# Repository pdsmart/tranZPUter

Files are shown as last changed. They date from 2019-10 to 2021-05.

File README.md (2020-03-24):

## Foreword

The tranZPUter is actively being developed and will be reflected in this document.

## Overview

The Sharp MZ80A is based on the Z80 CPU running at 2MHz. It is vintage and under powered compared with modern computers (or a Raspberry Pi). Besides being part of history, it has a software base that is useful from time to time and still has followers. A software Emulator could be written to prolong the usage of the software but there is something special about using original hardware and this is an alternative to keep the machine original yet provide an upgrade that can power the machine with multiple different CPU's (in FPGA, ie. ZPU, 68000 etc) and also power it with a Z80 running upto 128MHz. This is done by bus mastering where the original CPU is tri-stated and the FPGA takes control of the bus.

Besides providing more powerful and alternative CPU's and memory, the FPGA can also act as a Floppy Drive, Hard Drive etc using the connected SD Card and provide a menu system by overlaying the video memory when invoked.

This design is still a work in progress, I stopped development when I needed to advance the ZPU Evo SDRAM controller which I had been putting off for a while. The SDRAM is critical as the Cyclone 10LP on the CYC1000 has limited BRAM, only enough for the cache and IOCP Bootloader. Many features have been tested and the schematic/pcb made, it is just a matter of furthering the VHDL now that the SDRAM controller works and to develop the C/C++ code to provide the menu/SD services (already done in the ZPU code base).

I chose the CYC1000 as the FPGA solution as I am not competent soldering BGA devices, also at US$30 it is quite a cost effective choice. For software minded people, it is not that difficult to use a Pi Zero W or similar in place of the CYC1000 just a reworking of the PCB and interface logic, but that is a project for another time.

As the design replaces a Z80 in-situ it is not limited to the MZ80A but can be used in any Z80 based computer with the right software.

## tranZPUter

The tranZPUter gets its name from: A TRANsformable ZPU compuTER as the base CPU in the FPGA will be the ZPU Evo. The ZPU Evo will provide the Menu, SD, Video Overlay services to the Sharp MZ80A by tri-stating the original Z80 and accessing the MZ80A memory and peripherals as though they were ZPU devices.

To provide different CPU's it is just a matter of mapping in VHDL the softcore CPU signals to the MZ80A bus via this designs interface. The program memory could either be that on the MZ80A or the faster SDRAM. ie. There is no real need to use the MZ80A memory when using a softcore CPU. In my SharpMZ Emulator I run a Z80 at 112MHz using FPGA BRAM but tests show at least 128MHz is sustainable, thus a softcore Z80 CPU running at 128MHz with 48K BRAM slowing down only for MZ80A peripheral access would see a 64x boost in program run, which for say CP/M or database use is very desirable.

In the gallery are pictures of the current design and files uploaded onto github are relatively stable, WIP files wont be uploaded as they are in constant flux.

### Hardware

Sheet 1

The basics of this design lie in Z80 bus mastering, ie. the ability to switch the Z80 out of circuit and control the computer as required. Bus mastering was typically used by devices such as DMA for fast transfer of data from an I/O device to memory, or memory to memory 
for applications such as video/graphics. The device taking control of the Z80 bus could transfer data much faster than the Z80 running a program, hence the benefit.

In this design, the bus mastering is used in a similar vein, taking control of the Z80 bus to transfer data between main memory and an SD Card or between the I/O processor and the Video display buffer for presentation of menu's. It is also used where a soft processor
completely idle's the hard Z80 and acts as the main computer CPU. ie. using a soft T-80 ZPU CPU, it can process applications at 128MHz in local memory and slow down to access I/O and the Video buffer on the host machine.

The design centres around lifting the original Z80 onto a daughter card and rerouting several of its signals such that they can be controlled as needed. The core of the design is an FPGA, the Altera Cyclone 10LP on a mini development board made by Trenz Electronics.
This could quite easily be a Raspberry Pi or Teensy 3.6 but the aim of this project is to design electronic hardware in an FPGA using VHDL and making use of the ZPU Processor I have been working on in a seperate project.

The choice of the Trenz Electronic development board put a number of restrictions on the design in so much as it only provides limited I/O facilities. There were not so many other choices of pre-built FPGA development boards with the same size and features to choose from
and designing an FPGA directly into the design from project onset was considered too much a risk because my experience with BGA (Ball Grid Array) packaging and soldering of them was almost zero (I have reballed existing chips but those were working designs!).

As there were limited I/O facilities, I had to make use of two 16bit tri-state buffer latches in an addressed mode rather than a 1:1 mode. ie. The Z80 Data, Address and Control lines eminating out of the FPGA have to be 'set' one word at a time, ie. write data to latch, write address
to latch, write control signals to latch etc. This slows down the speed at which the FPGA can control the Z80 host (to be honest, a 100MHz FPGA can run 50 operations and still match the 2MHz original bus speed) and complicates the logic by requirement of FSM's in VHDL.

It is further complicated by the fact that the signals controlling the latches have themselves to be written in an addressed mode rather than direct, again due to lack of I/O facilities on the FPGA board. Thus in the schematic above you can see IC U6 & U8 being written to via
the common 16bit data bus (shared with the latches) and clocked by a single output signal from the FPGA. A delay line is used such that a write to the latch is performed by signal CYC_CTL/RST going high, this reaches the latch ~8ns after the same signal connected to the Master Reset goes high, thus clocking in the
data. The latches are reset when CYC_CTL/RST goes low and this is enough to control the 16 bit latches U5 & U9. ie. to write a 16bit word into U5 the procedure would be:
```
CYC_CTL/RST low
Set CYC_D0:7 to 0x02 (ADDR_LE active, low)
Set CYC_CTL/RST high, data on CYC_D0:7 is latched into U6/U8 and ADDR_LE goes active enabling transfer of data on CYC_D0:15 into U5 registers (latches on the rising edge of ADDR_LE).
Set required data on CYC_D0:15 that will be passed across to the Z80 BUS.
Set CYC_CTL/RST low, ADDR_LE goes inactive (high) and the data on CYC_D0:15 is latched into U5
```

Once the FPGA FSM is fine tuned, the actual write and read to/from the Z80 bus will be transparent but it is overly complicated as mentioned due to lack of I/O on the Trenz development board. 

### To Do
1. Write the ZPU C/C++ code to take control of the MZ80A, save/update/restore the Video Memory (for Menu system), convert the Main/sharpmz.? Menu/control code, and additional glue to use the SD card.<br/>
2. Convert the T80 CPU to act as a Z80 upgrade for the MZ80A.

## Credits

Where I have used or based any component on a 3rd parties design I have included the original authors copyright notice. All 3rd party software, to my knowledge and research, is open source and freely useable, if there is found to be any component with licensing restrictions, it will be removed from this repository and a suitable link/config provided.

## Licenses

This design, hardware and software, is licensed under the GNU Public Licence v3.

### The Gnu Public License v3
 The source and binary files in this project marked as GPL v3 are free software: you can redistribute it and-or modify it under the terms of the GNU General Public License as published by the Free Software Foundation, either version 3 of the License, or (at your option) any later version.

 The source files are distributed in the hope that it will be useful, but WITHOUT ANY WARRANTY; without even the implied warranty of MERCHANTABILITY or FITNESS FOR A PARTICULAR PURPOSE.  See the GNU General Public License for more details.

 You should have received a copy of the GNU General Public License along with this program.  If not, see http://www.gnu.org/licenses/.

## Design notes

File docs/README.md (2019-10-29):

## Foreword

This document is a work in progress.

## Overview

The Sharp MZ80A is based on the Z80 CPU running at 2MHz. It is vintage and under powered compared with modern computers (or a Raspberry Pi). Besides being part of history, it has a software base that is useful from time to time and still has followers. A software Emulator could be written to prolong the usage of the software but there is something special about using original hardware and this is an alternative to keep the machine original yet provide an upgrade that can power the machine with multiple different CPU's (in FPGA, ie. ZPU, 68000 etc) and also power it with a Z80 running upto 128MHz. This is done by bus mastering where the original CPU is tri-stated and the FPGA takes control of the bus.

Besides providing more powerful and alternative CPU's and memory, the FPGA can also act as a Floppy Drive, Hard Drive etc using the connected SD Card and provide a menu system by overlaying the video memory when invoked.

This design is still a work in progress, I stopped development when I needed to advance the ZPU Evo SDRAM controller which I had been putting off for a while. The SDRAM is critical as the Cyclone 10LP on the CYC1000 has limited BRAM, only enough for the cache and IOCP Bootloader. Many features have been tested and the schematic/pcb made, it is just a matter of furthering the VHDL now that the SDRAM controller works and to develop the C/C++ code to provide the menu/SD services (already done in the ZPU code base).

I chose the CYC1000 as the FPGA solution as I am not competent soldering BGA devices, also at US$30 it is quite a cost effective choice. For software minded people, it is not that difficult to use a Pi Zero W or similar in place of the CYC1000 just a reworking of the PCB and interface logic, but that is a project for another time.

As the design replaces a Z80 in-situ it is not limited to the MZ80A but can be used in any Z80 based computer with the right software.

## tranZPUter v1.0

The tranZPUter gets its name from: A TRANsformable ZPU compuTER as the base CPU in the FPGA will be the ZPU Evo. The ZPU Evo will provide the Menu, SD, Video Overlay services to the Sharp MZ80A by tri-stating the original Z80 and accessing the MZ80A memory and peripherals as though they were ZPU devices.

To provide different CPU's it is just a matter of mapping in VHDL the softcore CPU signals to the MZ80A bus via this designs interface. The program memory could either be that on the MZ80A or the faster SDRAM. ie. There is no real need to use the MZ80A memory when using a softcore CPU. In my SharpMZ Emulator I run a Z80 at 112MHz using FPGA BRAM but tests show at least 128MHz is sustainable, thus a softcore Z80 CPU running at 128MHz with 48K BRAM slowing down only for MZ80A peripheral access would see a 64x boost in program run, which for say CP/M or database use is very desirable.

Below are pictures of the current design and files uploaded onto github are relatively stable, WIP files wont be uploaded.

#### To Do
a) Write the ZPU C/C++ code to take control of the MZ80A, save/update/restore the Video Memory (for Menu system), convert the Main/sharpmz.? Menu/control code, and additional glue to use the SD card.<br/>
b) Convert the T80 CPU to act as a Z80 upgrade for the MZ80A.

### Images of the tranZPUter daughter board
##### 

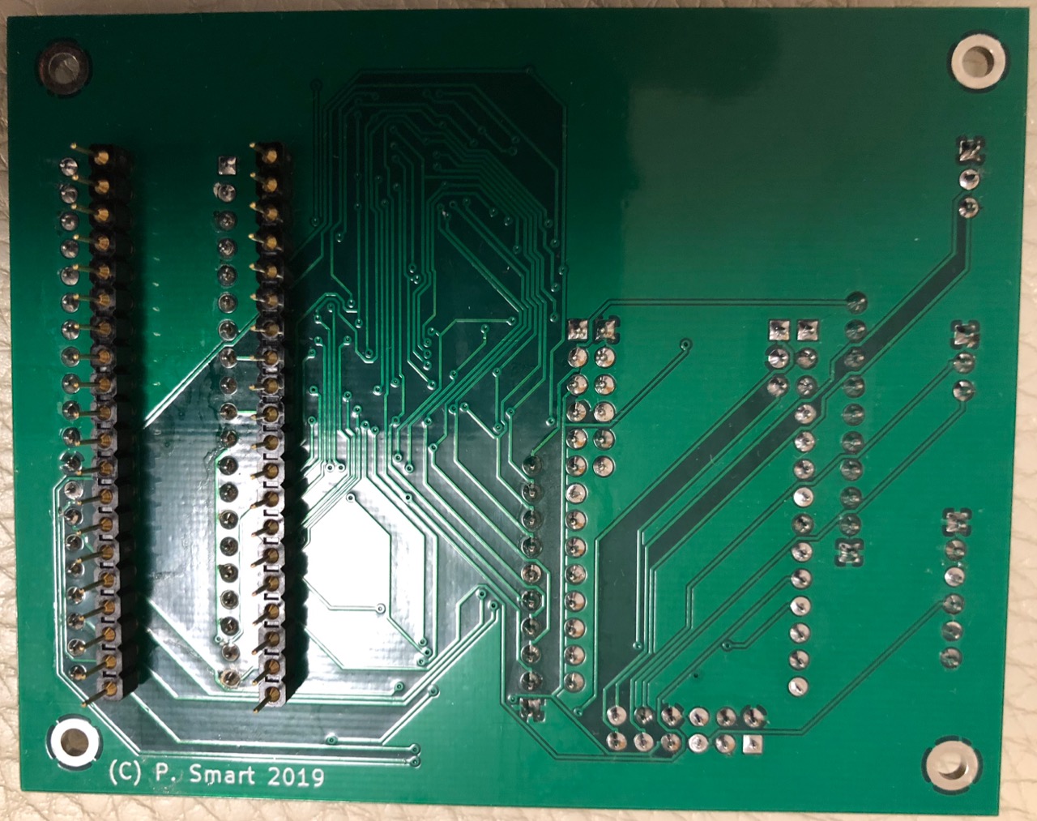
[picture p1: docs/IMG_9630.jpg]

Underside of the daughter board showing a 40pin standoff connector. The original Z80 CPU is removed, located onto the daughter board which is then connected by the 40pin standoff to the main board.

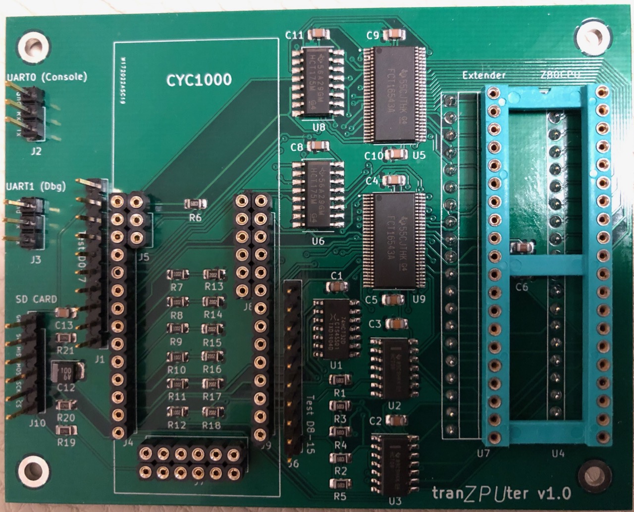
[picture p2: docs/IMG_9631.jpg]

Topside of the daughter board without the Z80 or CYC1000 devices.

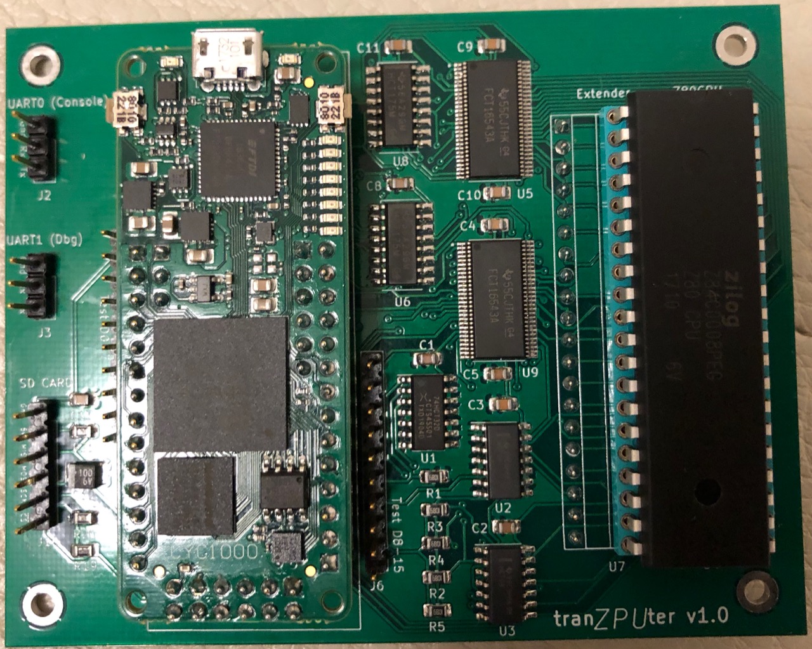
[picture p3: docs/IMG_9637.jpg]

Topside of the daughter board with the Z80 and CYC1000 in place.

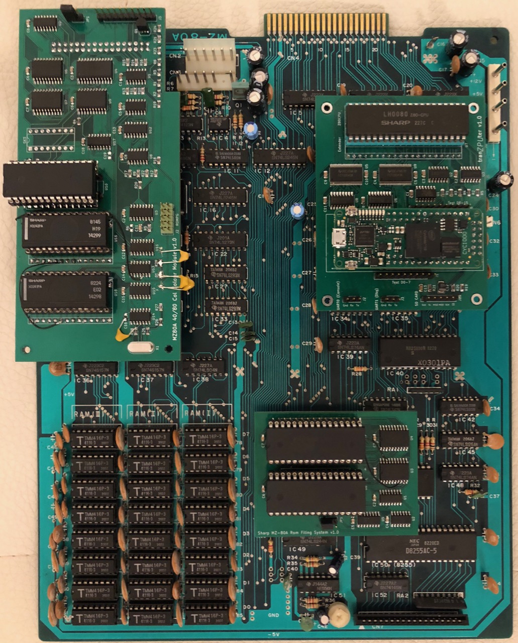
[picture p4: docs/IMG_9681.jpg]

The original motherboard, the tranZPUter daughter board is located top right and the 40/80 column and RFS daughter boards can also be seen in place.

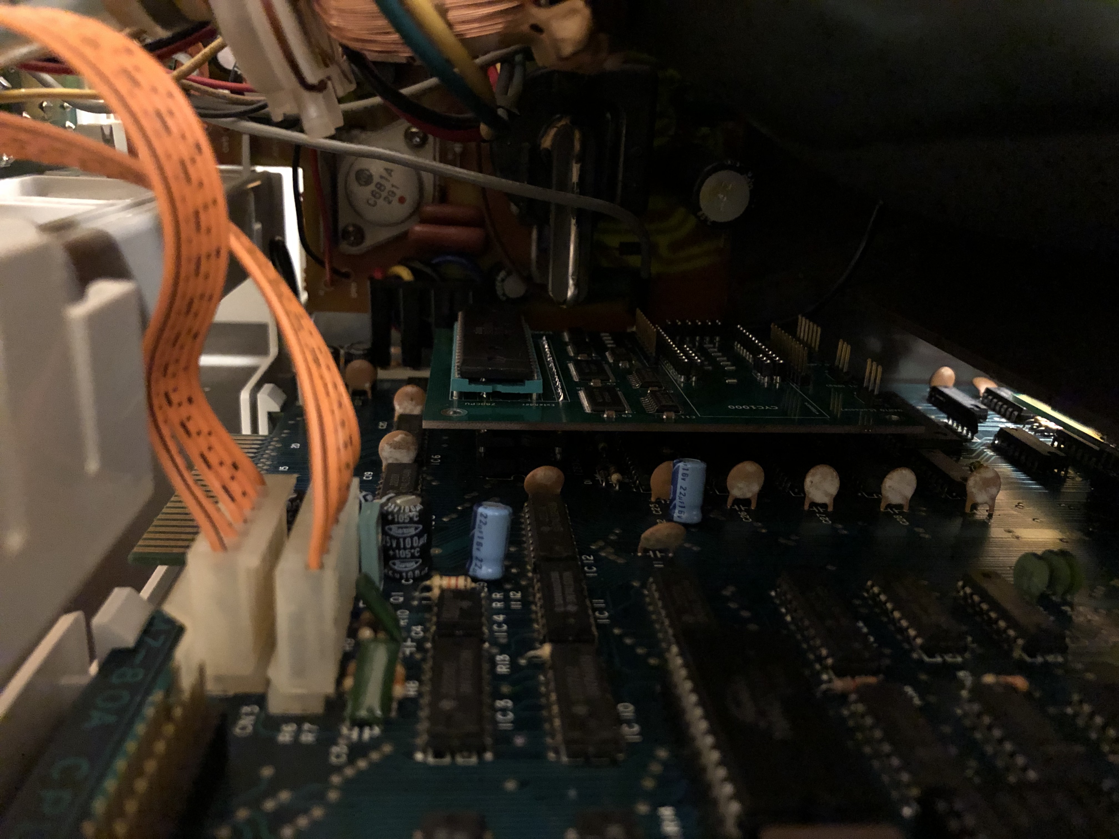
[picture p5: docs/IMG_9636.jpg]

A test to verify that the board sits correctly within the MZ80A computer.

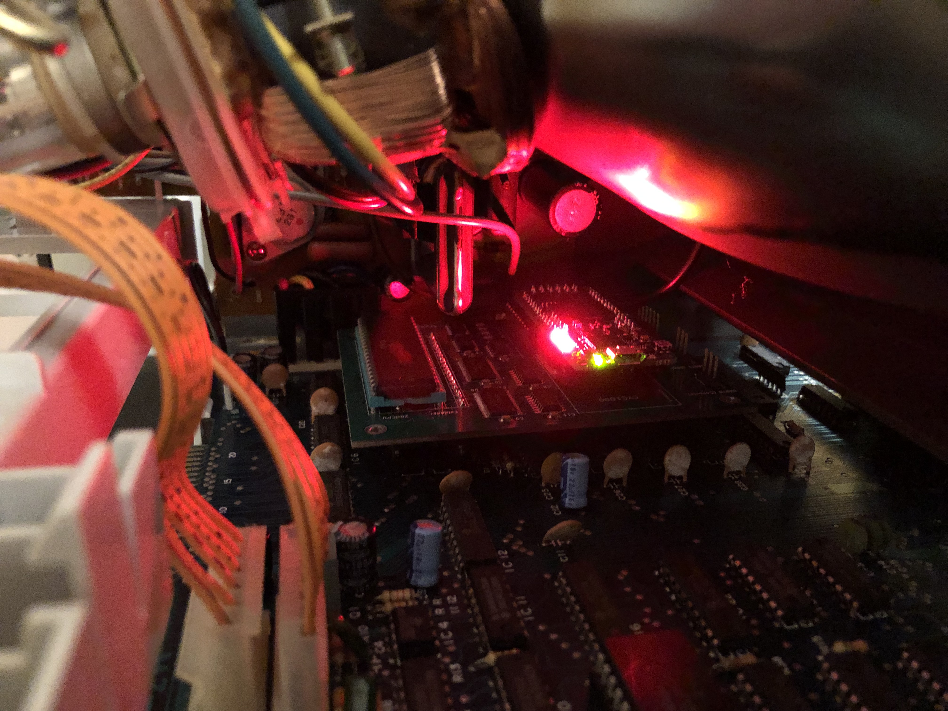
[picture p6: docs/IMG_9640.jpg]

A power on test and verification.

## Credits

Where I have used or based any component on a 3rd parties design I have included the original authors copyright notice.

## Licenses

This design, hardware and software, is licensed under th GNU Public Licence v3.

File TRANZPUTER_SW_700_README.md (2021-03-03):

## Foreword

<div style="text-align: justify">
The tranZPUter SW-700 is an evolution and merge of the tranZPUter, tranZPUter SW and Video Module v2.0 projects which were originally developed for the Sharp MZ-80A.
<br><br>

The project aims to provide the same functionality to the Sharp MZ-700 as is now provided on the Sharp MZ-80A.
<br><br>

The Sharp MZ-700 is a more compact design which required a new solution for upgrading it's CPU and Video. It wasnt possible, without hardware hacks, to upgrade the existing video and
with limited internal space presented more of a challenge. I eventually settled on a combined board where the tranZPUter SW and Video Module designs were used but with less components
and a co-existence of the new enhanced video with the original. This solution allows the machine to run as original or with selectable enhanced features as required. It is a more
wholesome solution with many possibilites beyond enhancing the MZ-700, for example it would be quite easy to run Linux on this machine, either via the on-board K64F processor using the
host as a terminal and/or reprogramming of the CPLD/FPGA to instantiate a soft-cpu and creating a development station for any conceivable processor, so would be of great use to 
students studying microprocessors and FPGA's.
<br><br>

The design is still being developed and these pages will be updated as new information becomes available. The reader is encouraged to read the seperate sections on the tranZPUter,
tranZPUter SW and Video Module to gain an understanding of the tranZPUter SW-700 evolution.
<br><br>

Everything will be written in C/C++ (FLW - Famous Last Words - I had to write the interrupt service routines in ARM Thumb assembler for the original tranZPUter SW as the K64F wasnt quite powerful enough
using compiled C).
</div>

--------------------------------------------------------------------------------------------------------

## Overview

<div style="text-align: justify">
The Sharp MZ-700 is based on the Z80 CPU running at 3.54MHz. It is vintage (albeit the Z80 is still widely used in new industrial designs clocking at 33MHz and above) and under powered compared
with modern computers (or a Raspberry Pi). Besides being part of history, it has a software base that is useful from time to time and still has followers. Many software Emulator's have been written
for the Sharp MZ-700 to prolong the usage of the software but there is something special about using original hardware and this is an alternative to keep the machine original yet provide an upgrade that can power
the machine with additional processing capabilities, storage and with multiple different CPU's based in software like the PiCoPro on the BBC Micro. This is all made possible with bus mastering
where the original CPU is tri-stated and the K64F/CPLD/FPGA takes control of the bus and the underlying original mainboard peripherals, when needed.
<br><br>

The upgrade also extends the Z80 hardware capabilities by providing additional RAM to allow for a 64K version of CP/M v2.2 (and upto 512K CP/M v3 when I get around to porting it) and to increase the speed of the
processor whilst maintaining the original speed when accessing the Sharp MZ-700 motherboard peripherals.
<br><br>

This design is a work in progress, albeit now mature and stable, it is working in tandem with the tranZPUter, tranZPUter SW and Video Module projects. As updates to the aforementioned projects are made or viz-a-viz, they are
back ported to this design. The C/C++ control software written for the tranZPUter SW is common and also intended to work on the tranZPUter under the ZPU.
</div>

--------------------------------------------------------------------------------------------------------

## tranZPUter SW-700

<div style="text-align: justify">
The tranZPUter gets its name from: A TRANsformable ZPU compuTER as the base CPU intended for the original tranZPUter is the ZPU Evo. The requirement was for the ZPU Evo to provide intended Menu, SD and Video Overlay services to the
Sharp MZ-80A by tri-stating the original Z80 and accessing the MZ-80A memory and peripherals as though they were ZPU devices.
<br><br>

The tranZPUter SW-700 follows on from the tranZPUter / tranZPUter SW designs and in addition adding the Video Module functionality to upgrade the host video. It also upgrades the underlying Z80 hardware enabling higher performance
and increased memory. It embeds a Freescale K64F ARM Cortex-M4 in place of the ZPU Evo as the tranZPUter SW-700 is more a software solution to the requirement rather than the ZPU Evo which is based on VHDL on an FPGA.
The project adds the suffix SW-700 for <u>S</u>oft<u>W</u>are for the MZ-<u>700</u> to distinguish the designs. 
<br><br>

The design of the tranZPUter SW-700 upgrades the Z80 hardware and can clock the processor, detached from the Sharp MZ-700 motherboard, at much higher clock rates, 
reliably tested and verified at 24MHz by overclocking a Z84C0020 20MHz CPU. Higher CPU performance will be a benefit to programs such as CP/M or databases such as DBase II.
<br><br>

To provide different CPU's you have the choice of taking existing ARM based software CPU emulations, for example those used in the PiCoPro and adapting them to use the CPU signals on the MZ-700 bus via this
designs interface or hardware based 'soft' processors instantiated on the FPGA. The program memory could be either: the MZ-700 motherboard 64K; the tranZPUter 512K; the faster K64F 256K memory;  FPGA BRAM or any combination. There is no real
need to use the MZ-700 memory when using a soft/'soft' CPU except for perhaps cache purposes. The benefits of using a soft/'soft' CPU with local K64F/FPGA RAM is better performance and access to alternative software.
<br><br>

In the gallery are pictures of the current design, files have been uploaded onto github and are relatively stable, WIP files wont be uploaded as they are in constant flux.
</div>

--------------------------------------------------------------------------------------------------------

## Hardware

<div style="text-align: justify">
The basics of this design lie in Z80 bus mastering, ie. the ability to switch the Z80 out of circuit and control the remaining computer hardware as required. Bus mastering was typically used
by devices such as DMA for fast transfer of data from an I/O device to memory, or memory to memory for applications such as video/graphics. The device taking control of the Z80 bus could transfer data much
faster than the Z80 running a program to perform the same action, hence the benefit.
<br><br>

Bus mastering is used to take control of the Z80 bus and to transfer data between main memory and an SD Card or between the I/O processor and the Video display
buffer for presentation of menu's. It is also used where a soft processor completely idle's the hard Z80 and acts as the main computer CPU. ie. using a soft CPU emulator, it can process
applications in local memory and slow down to access I/O and the Video buffer (if running with original video, the enhanced video runs at full speed) on the host machine as needed presenting a completely different
computing experience. Imagine, a 6809 or a 68000 based Sharp MZ-700!
<br><br>

The design centres around lifting the original Z80 onto a daughter card and rerouting several of its signals such that they can be controlled as needed. It also takes video output from the mainboard and routes it
internally to the FPGA based video module, where original or enhanced video can be selected before it is rerouted to the modulator via a new connector.
<br><br>

Design versions v1.0 and v1.1 were internal designs and wont appear in the repository. v1.2 was the first design which went on to be assembled and tested on the MZ-700. This design was used to further the software and FPGA development
and verify stability and reliability.  v1.3 is now the mainstream design, based on a more powerful FPGA, a Cyclone IV 75K (or a Cyclone IV 115K - build time selectable) which allows for higher resolution graphics and the ability to utilise 
alternate 'soft' hardware based processors, specifically the Z80 clone, T80 and the ZPU Evolution.
<br><br>

v1.2 and v1.3, with fundamental differences in logic and software, maintain their own branches in git. Both are proven designs, with v1.2 being cheaper to produce.
</div>

--------------------------------------------------------------------------------------------------------

## v1.2 Schematics

Version 1.2 is the first official release of the tranZPUter SW-700 design. It is based around the Sharp MZ-80A tranZPUter SW v2.2 and the Video Module v2.0 with optimisations to fit the Sharp MZ-700 platform.

### v1.2 Z80 Upgrade Schematic

Sheet 1

<div style="text-align: justify">
In order to be able to run programs for other Sharp models (ie. MZ-80A) or 64K CP/M the design adds a 512KB Static RAM device with necessary paging logic. An older MAX7000 series 512 macro cell CPLD is used as these devices are
5V tolerant thus saving on voltage translation circuitry between the 5V signals of the Sharp MZ-700 and the 3.3V signals used by the CPLD/FPGA. The CPLD provides the decoding logic, I/O remapping (ie. keyboard) and interface
to the FPGA (which is only 3.3V tolerant). The use of a CPLD, besides it's voltage translation abilities, allows for a very flexible development environment where features can be added at will, subject to the 512 macro cell limit.
<br><br>

The above schematic has been designed such that the board can be installed into an MZ-700 and the CPLD will be configured such that the machine is original, ie. no additional features enabled on power up. A write by the Z80 to the CPLD
I/O registers can enable features as required. This fulfills the requirement of keeping the machine original to maintain maximum compatibility with software.
</div>

### v1.2 The K64 I/O Processor

Sheet 2

<div style="text-align: justify"><br>
In order to provide embedded debugging, development and learning tools, enhanced features such as an SD card, soft-processors and offloaded co-processor services, an Freescale K64F ARM Cortex-M4 CPU is added into the design. This processor
has all the necessary hardware connectivity with the CPLD/Z80 giving it the ability to read or control any aspect of the tranZPUter SW-700 board or the MZ-700 mainboard. Under default conditions the K64F interacts with the Z80 to load the TZFS
enhanced monitor, provide an SD drive and aid in providing the alternate MZ series emulations such as the MZ-80A.
<br><br>

As the K64F utilises <b>zOS</b> as it's embedded OS, a USB connection can be made to the MZ-700 and a user can interact with an embedded session to change CPU frequency, edit/dump memory, change registers etc. This feature is ideal for learning
how a computer works or for debugging Z80/ARM code.
<br><br>

An optional feature is the installation and use of the PJRC bootstrap MCU which allows updating the K64F firmware via a USB cable. Without this MCU, the JTAG interface has to be used along with a compatible Open SDA interface such as the one provided
on the Freescale FRDM-K64F development board to update the K64F firmware. To allow for this optional device there are a set of 5 solder jumpers, connecting pads 1-2 on JP1-5 allows programming and use of the PJRC MCU, connecting pads 2-3 on JP1-4, pins 1-2 on JP5 
enables programming via the JTAG interface using the SWD protocol.
<br><br>

To power the K64F a seperate 3.3V regulator is used. It was intentionally chosen to use a seperate LDO to power the K64F rather than combining with the CPLD/FPGA requirements and use a larger LDO.
<br><br>

NB. A zOS application is being developed to flash new firmware into the K64F via the zOS console from the SD card and will remove the need to use the PJRC or JTAG tools. This tool should be available in zOS v1.2.
</div>

### v1.2 JTAG Programming and Oscillator

Sheet 3

<div style="text-align: justify"><br>
This design uses a CPLD and an FPGA both of which require programming via a JTAG interface. Using Altera best-practice the JTAG interface is wired to the highest voltage device first (CPLD) and daisy chained to the lower voltage
FPGA. The recommended pull-up/down resistors are as per Altera specifications.
<br><br>

The FPGA requires a bit stream to configure its internal logic matrix, which in turn provides the desired hardware functionality. This can be done real-time via a JTAG interface but doesnt solve the issue on power up. This is the
reason for the 16Mbit EPCS16 which is connected to the Cyclone III FPGA bootstrap pins. The EPCS16 is programmed via the Cyclone III using an Altera provided IP (Intellectual Property) which converts JTAG programming into EPCS16
programming. Once programmed and upon power up or pressing of the CONFIG switch, the EPCS16 contents are read into the FPGA and configures its logic matrix.
<br><br>

As the FPGA has 4 onboard PLL devices, the main crystal is fed into the Cyclone III FPGA and this acts as the timebase for all internal synchronous signals and video mode clocks. The frequencies used by the Z80, ie. the mainboard
frequency SYSCLK and the K64 generated alternate frequency CTLCLK are also fed into the Cyclone III to enable synchronisation.
</div>

### v1.2 Power Supply

Sheet 4

<div style="text-align: justify"><br>
Using more advanced technology requires voltages different to the original 5V standard. The CPLD requires 3.3V to function and the FPGA requires 1.2V for internal operations, 2.5V for analogue and PLL devices and a selectable 
I/O voltage, which in this design is 3.3V as it interfaces with the CPLD.
<br><br>

In order to generate these voltages, 3 LDO devices are used, each specified to 1A per rail. Using Altera tools the maximum power requirement for the CPLD/FPGA will be met by these LDO devices and by the original Sharp MZ-700 PSU.
<br><br>

Additionally, using CPLD/FPGA devices requires significant decoupling and Altera provide a dynamic spreadsheet to work out the number and value required. This is reflected in the schematic above.
</div>

### v1.2 Video Interface

Sheet 5

<div style="text-align: justify"><br>
Provision of enhanced video in this design differs from the method used in the Video Module v2.0. It was not possible to uplift existing IC's from the mainboard as most are soldered in place and internal space for expansion 
is also a big issue. Alternative methods were considered, eventually deciding on a mechanism which not only provided enhanced video from the FPGA but also allowed the original video to remain, switching between the two by software
as needed.
<br><br>

Using this mechanism, the video signals are uplifted from the mainboard modulator connector, routed into the FPGA via the CPLD (CPLD is 5V tolerant) and the FPGA either switches the original video to the output or generates it's 
own video. The CPLD takes care of enabling the mainboard such that when the enhanced FPGA video is being used, the signals to the original video hardware are blocked via the bus tri-state mechanism.
<br><br>

On the Video Module v2.0, 4 bits (3:0) per colour are output to give greater colour depth than the original MZ-700 hardware, which can be either driven directly from video ram attribute bits or via a colour palette lookup table. As this
design now has to maintain compatibility with the original modulator a 5th bit per colour has been added so that digital RGB monitors and the circuitry for composite/TV inside the modulator are driven by a voltage > 2V for logical
1 as opposed to the analogue RGB requirements of 0 - 0.75Vp-p. When driving a digital RGB monitor or driving the composite/TV output of the MZ-700 the 5th bit will be activated along with all the other bits therefore ensuring > 2.0V
for a digital 1. When driving an analogue RGB monitor the 5th bit cannot be activated as it will over saturate the inputs, BUT if the bit is set to hi-Z or 0 levels then the 5th bit can be used to create a further 16 sets of shades 
per colour, ie. R[3:0] + 0, G[3:0] + 0, B[3:0] + 0 or R[3:0] + hi-Z, G[3:0] + hi-Z, B[3:0] + hi-Z. This works when the 5th bit is set to 0 as it will act as a current sink for the other 4 bits, dropping the voltage seen by the monitor
when the 10R resistor is seen in-circuit. This provides 32 unique voltage levels per colour. When the 5th bit is set to hi-Z (high impedance) there is negligible change in the voltage output from bits 3:0.
<br><br>

</div>

#### v1.2 PCB

<div style="text-align: justify"><br>
The PCB requirements to fit inside the MZ-700 had to be accurate, in terms of the locations it could be sited to not affect mainboard components, casing obstacles, heat generation etc. Also the board has to fit into the Z80 socket yet
at the same time connect to the modulator connector, both would provide the anchor points to keep the board electrically connected and mechanically stable.
<br><br>

This design now uses 3 high density TQFP packages therefore adding more complexities, ie. routing. Space has to be available for all the lands given they are output in a 0.5mm pitch over a large area along with power distribution and decoupling.
The board is intentionally kept to 2 layer to gain the best production cost, typically US$60 including stencils for 10 boards, multi-layer would more than double the cost and only gain marginal size reductions.
<br><br>

The board below is a fully assembled and tested PCB for the Sharp MZ-700 along with images showing it installed in the physical machine.
</div>

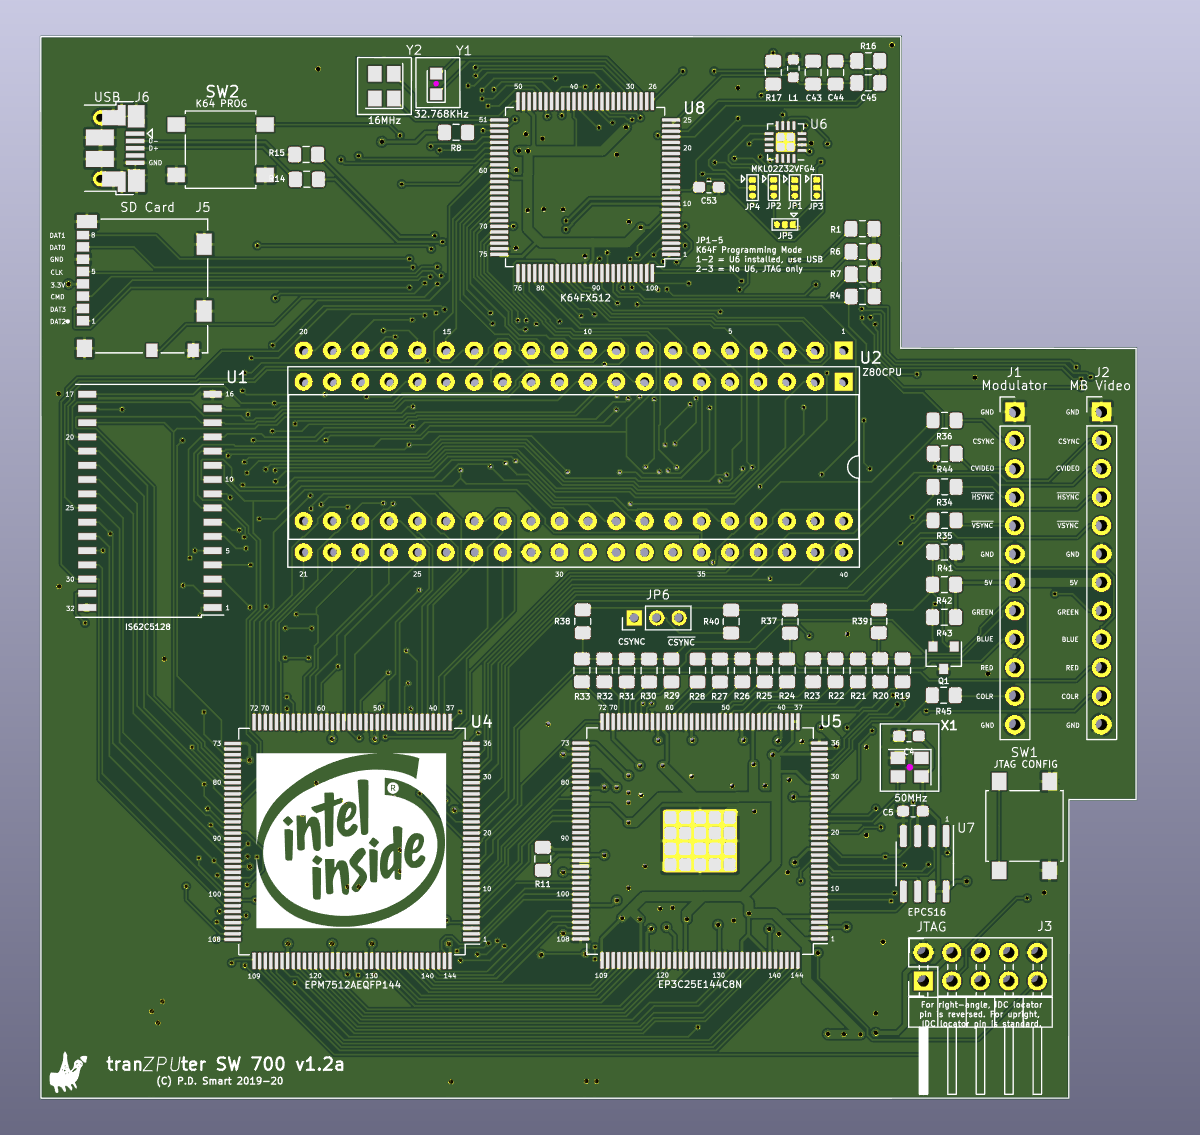
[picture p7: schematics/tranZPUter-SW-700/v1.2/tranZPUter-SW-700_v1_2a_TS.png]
PCB TopSide


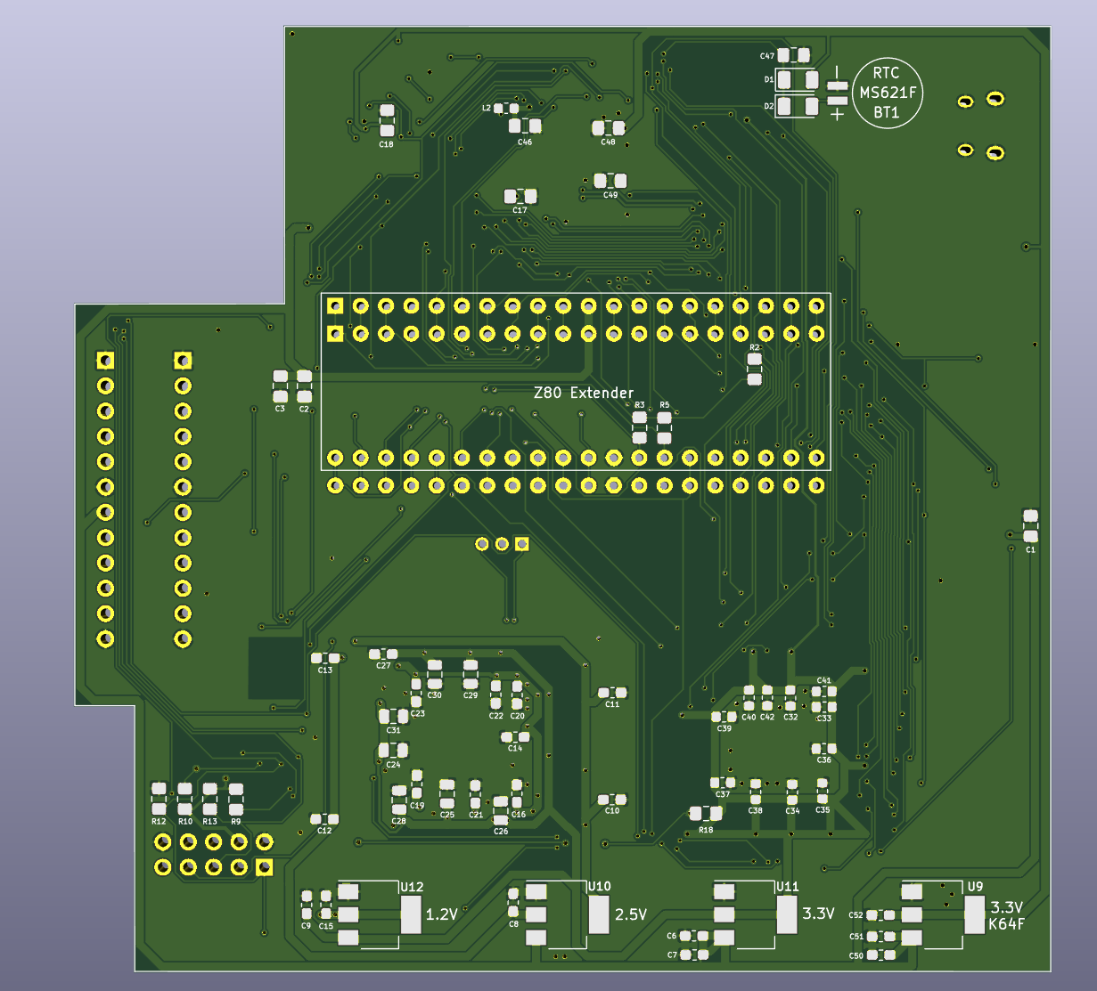
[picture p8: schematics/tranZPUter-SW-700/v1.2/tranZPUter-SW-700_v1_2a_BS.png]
PCB UnderSide


Installed, no case

Installed with case

--------------------------------------------------------------------------------------------------------

## v1.3 Schematics

Version 1.3 takes the working design of v1.2 and changes the FPGA to a more advanced component, the Cyclone IV EP4CE75, a 75K Logic Element device with over 340KB Block RAM. A build time option can use the Cyclone IV EP4CE115, a 115K Logic Element device with over 480K Block RAM.
These devices allows for more advanced graphics, higher resolution and more simultaneous colours. It also allows for the creation of 'soft' HDL based CPU's and is a stepping stone to the next iteration of the original ZPU based tranZPUter which will be based entirely on FPGA's (ie. no Z80, just a Z80 extender socket with 
the Z80 instantiated as a soft-cpu in the FPGA).

### v1.3 Z80 Upgrade Schematic

Sheet 1

<div style="text-align: justify">
Version 1.3 remains identical to v1.2 in all areas except the FPGA and additional interconnects between the CPLD/FPGA. V1.2 used a Cyclone III with 25K LE packaged as TQFP, v1.3 uses a Cyclone IV with 75K LE and is packaged as a 484pin BGA. The majority of the work centered around
decoupling, pin allocation and PCB production.
<br><br>

</div>

### v1.3 The K64 I/O Processor

Sheet 2

<div style="text-align: justify"><br>
The K64F schematic remains the same as v1.2 with the exception of reworking of the interconnects, removing some which no longer serve a useful function and adding to allow full 24bit direct addressing of memory and FPGA resources.
</div>

### v1.3 JTAG Programming and Oscillator

Sheet 3

<div style="text-align: justify"><br>
Version 1.3 sees the FPGA change and as a consequence, the clock is assigned to different clock inputs. In addition, as the device is larger, it requires a larger boot device in the form of the EPCS64, a 64mbit serial flash ram.
As the config switch proved redundant in v1.2 it has been removed from v1.3, programming via JTAG or PJRC MCU automatically invoke FPGA config mode.
</div>

### v1.3 Power Supply

Sheet 4

<div style="text-align: justify"><br>
Using a larger FPGA device places a greater demand on decoupling, no less than 34 decoupling capacitors are deemed necessary by the Altera PDN tool. This made for interesting PCB placement and routing!
</div>

### v1.3 Video Interface

Sheet 5

<div style="text-align: justify"><br>
The video interface remains the same as v1.2.
</div>

### v1.3 PCB

<div style="text-align: justify"><br>
Version 1.3 PCB is a rework of v1.2, replacing a 144 pin TQFP with a 484pin BGA, both identical in size but different in some parts placement and routing. The PCB remains as a 2 layer design but the inclusion of the BGA sees smaller via/land geometries and masked or filled via's. This increases the cost of PCB production
several fold over the v1.2 design. The PCB had a routing error which given the production cost had to be reworked, involving BGA pad rerouting and drilling, an intricate process but one which wont be forgotten. The old adage, 'measure twice, cut once' comes to mind, I measured twice but didnt make a final check, more especially after
a computer crash where I think the error originated, so my bad!
</div>

PCB TopSide

PCB UnderSide

PCB Installed
--------------------------------------------------------------------------------------------------------

## Design Detail

<div style="text-align: justify">
This section provides internal design information for understanding how the tranZPUter SW-700 functions and its interactions with the Host (the original computer).
</div>

--------------------------------------------------------------------------------------------------------

### K64F Z80 Host API

<div style="text-align: justify">
The API is based on a common block of RAM within the 64K memory space of the Z80 through which interprocessor communications take place. On the K64F this is declared
in C as a structure and on the Z80 as an assembler reference to memory variables.
<br>
</div>

```c
// Structure to contain inter CPU communications memory for command service processing and results.
// Typically the z80 places a command into the structure in it's memory space and asserts an I/O request,
// the K64F detects the request and reads the lower portion of the struct from z80 memory space, 
// determines the command and then either reads the remainder or writes to the remainder. This struct
// exists in both the z80 and K64F domains and data is sync'd between them as needed.
//
typedef struct __attribute__((__packed__)) {
    uint8_t                          cmd;                                // Command request.
    uint8_t                          result;                             // Result code. 0xFE - set by Z80, command available, 0xFE - set by K64F, command ack and processing. 0x00-0xF0 = cmd complete and result of processing.
    union {
        uint8_t                      dirSector;                          // Virtual directory sector number.
        uint8_t                      fileSector;                         // Sector within open file to read/write.
        uint8_t                      vDriveNo;                           // Virtual or physical SD card drive number.
    };
    union {
        struct {
            uint16_t                 trackNo;                            // For virtual drives with track and sector this is the track number
            uint16_t                 sectorNo;                           // For virtual drives with track and sector this is the sector number. NB For LBA access, this is 32bit and overwrites fileNo/fileType which arent used during raw SD access.
        };
        uint32_t                     sectorLBA;                          // For LBA access, this is 32bit and used during raw SD access.
    };
    uint8_t                          fileNo;                             // File number of a file within the last directory listing to open/update.
    uint8_t                          fileType;                           // Type of file being processed.
    union {
        uint16_t                     loadAddr;                           // Load address for ROM/File images which need to be dynamic.
        uint16_t                     saveAddr;                           // Save address for ROM/File images which need to be dynamic.
        uint16_t                     cpuFreq;                            // CPU Frequency in KHz - used for setting of the alternate CPU clock frequency.
    };
    union {
        uint16_t                     loadSize;                           // Size for ROM/File to be loaded.
        uint16_t                     saveSize;                           // Size for ROM/File to be saved.
    };
    uint8_t                          directory[TZSVC_DIRNAME_SIZE];      // Directory in which to look for a file. If no directory is given default to MZF.
    uint8_t                          filename[TZSVC_FILENAME_SIZE];      // File to open or create.
    uint8_t                          wildcard[TZSVC_WILDCARD_SIZE];      // A basic wildcard pattern match filter to be applied to a directory search.
    uint8_t                          sector[TZSVC_SECTOR_SIZE];          // Sector buffer generally for disk read/write.
} t_svcControl;
```

<div style="text-align: justify"><br>
Communications are all instigated by the Z80. When it needs a service, it will write a command into the svcControl.cmd field and set the svcControl.result field to 
REQUEST. The Z80 then writes to an output port (configurable but generally 0x68) which in turn sends an interrupt to the K64F. The K64F reads the command and sets the
svcControl.result to PROCESSING - the Z80 waits for this handshake, if it doesnt see it after a timeout period it will resend the command. The Z80 then waits for a valid
result, again if it doesnt get a result in a reasonable time period it retries the sequence and after a number of attempts gives up with an error.
<br><br>

Once the K64F has processed the command (ie. read directory) and stored any necessary data into the structure, it sets the svcControl.result to a valid result (success,
fail or error code) to complete the transaction.
</div>

**API Command List**

| Command | Cmd# | Description |
| --- | --- | --- |
| TZSVC_CMD_READDIR | 0x01 | Open a directory and return the first block of entries. |
| TZSVC_CMD_NEXTDIR | 0x02 | Return the next block in an open directory. |
| TZSVC_CMD_READFILE | 0x03 | Open a file and return the first block. |
| TZSVC_CMD_NEXTREADFILE | 0x04 | Return the next block in an open file. |
| TZSVC_CMD_WRITEFILE | 0x05 | Create a file and save the first block. |
| TZSVC_CMD_NEXTWRITEFILE | 0x06 | Write the next block to the open file. |
| TZSVC_CMD_CLOSE | 0x07 | Close any open file or directory. |
| TZSVC_CMD_LOADFILE | 0x08 | Load a file directly into tranZPUter memory. |
| TZSVC_CMD_SAVEFILE | 0x09 | Save a file directly from tranZPUter memory. |
| TZSVC_CMD_ERASEFILE | 0x0a | Erase a file on the SD card. |
| TZSVC_CMD_CHANGEDIR | 0x0b | Change active directory on the SD card. |
| TZSVC_CMD_LOAD40ABIOS | 0x20 | Request 40 column version of the SA1510 BIOS to be loaded, change frequency to match the Sharp MZ-80A. |
| TZSVC_CMD_LOAD80ABIOS | 0x21 | Request 80 column version of the SA1510 BIOS to be loaded, change frequency to match the Sharp MZ-80A. |
| TZSVC_CMD_LOAD700BIOS40 | 0x22 | Request 40 column version of the 1Z-013A MZ-700 BIOS to be loaded, change frequency to match the Sharp MZ-700 and action memory page commands. |
| TZSVC_CMD_LOAD700BIOS80 | 0x23 | Request 80 column version of the 1Z-013A MZ-700 BIOS to be loaded, change frequency to match the Sharp MZ-700 and action memory page commands. |
| TZSVC_CMD_LOAD80BIPL | 0x24 | Request the loading of the MZ-80B IPL, switch frequency and enable Sharp MZ-80B compatible mode. |
| TZSVC_CMD_LOADBDOS | 0x30 | Reload CPM BDOS+CCP. |
| TZSVC_CMD_ADDSDDRIVE | 0x31 | Attach a CPM disk to a drive number. |
| TZSVC_CMD_READSDDRIVE | 0x32 | Read an attached SD file as a CPM disk drive. |
| TZSVC_CMD_WRITESDDRIVE | 0x33 | Write to a CPM disk drive which is an attached SD file. |
| TZSVC_CMD_CPU_BASEFREQ | 0x40 | Set the tranZPUter to use the mainboard frequency for the Z80. |
| TZSVC_CMD_CPU_ALTFREQ | 0x41 | Switch the Z80 to use the K64F generated clock, ie. alternative frequency. |
| TZSVC_CMD_CPU_CHGFREQ | 0x42 | Change the Z80 frequency generated by the K64F to the Hertz value given in svcControl.cpuFreq, the Z80 will be clocked at the nearest timer resolution of this frequency. |
| TZSVC_CMD_CPU_SETZ80 | 0x50 | Switch to the external Z80 hard cpu. |
| TZSVC_CMD_CPU_SETT80 | 0x51 | Switch to the internal T80 soft cpu. |
| TZSVC_CMD_CPU_SETZPUEVO | 0x52 | Switch to the internal ZPU Evolution cpu. |
| TZSVC_CMD_SD_DISKINIT | 0x60 | Initialise and provide raw access to the underlying SD card.  |
| TZSVC_CMD_SD_READSECTOR | 0x61 | Provide raw read access to the underlying SD card. |
| TZSVC_CMD_SD_WRITESECTOR  | 0x62 | Provide raw write access to the underlying SD card. |
| TZSVC_CMD_EXIT | 0x7F | Terminate TZFS and restart the machine in original mode. |

**API Result List**

| Command | Result#  | Description |
| --- | --- | --- |
| TZSVC_STATUS_OK | 0x00 | The K64F processing completed successfully. |
| TZSVC_STATUS_FILE_ERROR | 0x01 | A file or directory error. |
| TZSVC_STATUS_BAD_CMD | 0x02 | Bad service command was requested. |
| TZSVC_STATUS_BAD_REQ | 0x03 | Bad request was made, the service status request flag was not set. |
| TZSVC_STATUS_REQUEST | 0xFE | Z80 has posted a request. |
| TZSVC_STATUS_PROCESSING | 0xFF | K64F is processing a command. |

--------------------------------------------------------------------------------------------------------

### K64F GPIO Organisation

<div style="text-align: justify">
In this design the K64F works in a supervisory and service role. The Z80 can function standalone without the K64F being present which leaves the host machine completely original and in addtion, the tranZPUter board also offers some
new upgrades such as 512K Static RAM which the Z80 can make use of as needed.
<br><br>

If advanced services are needed such as SD card access, alternate BIOS loading or variable alternative CPU clock then it needs the K64F to provide them, the Z80 see's the K64F as a hardware extension, it makes an I/O request and gets functionality in return.
<br><br>

If the Z80 for example requests a BIOS load, it generates an I/O out request which interrupts the K64F, the K64F puts the Z80 into tri-state bus mastered mode and then reads the BIOS from the SD card and operates the Z80 lines to write 
the BIOS data into the Z80 RAM.
<br><br>

In order to provide this functionality, the K64F needs to be able to read/write ALL of the Z80 signals. One of the advantages of the K64F is that it has an abundance of digitial I/O ports which are 5V tolerant, therefore connection
and operation of a 5V Z80 system is relatively straight forward.
<br><br>

The pin allocation of Z80 signals to K64F GPIO Port/Pin is a little disjointed as the K64F doesnt have a linear allocation of GPIO pins to internal registers, ie. the GPIO pins are split
over 5 32bit registers. This non-linear allocation adds overhead in piecing together 16bit address or 8bit data value's for realtime assembly and decode.
<br><br>

In earlier tranZPUter SW designs, the allocation of Z80 pins to GPIO Port/Pins led to some headaches in the interrupt service routine but these have now been solved by the addition of the CPLD which contains most of the time critical logic.
<br><br>

The following tables have been created to show Z80 signals to their associated K64F pins. The signals are spread across 5 x 32bit internal K64F registers.
</div>

##### K64F Port and Bit allocation 

| BIT / PORT | 31 | 30 | 29 | 28 | 27 | 26 | 25 | 24 | 23 | 22 | 21 | 20 | 19 | 18 | 17 | 16 | 15 | 14 | 13 | 12 | 11 | 10 | 9 | 8 | 7 | 6 | 5 | 4 | 3 | 2 | 1 | 0 |
|---|----|----|----|----|----|---|---|---|---|---|---|---|---|---|---|---|---|---|---|---|---|---|---|---|---|---|---|---|---|---|---|---|
| A | | | | | | | | | | | | | | |Z80_NMI |Z80_INT | |CTL_HALT  |CTL_RFSH |CTL_M1 | | | | | | |SYSCLK | | | | | |
| B | | | | | | | | |Z80_D7 |Z80_D6 |Z80_D5 |Z80_D4 |Z80_D3  |Z80_D2 |Z80_D1 |Z80_D0 | | | | |CTL_CLKSLCT|Z80_WAIT |Z80_MEM4 | | | | | |Z80_MEM3 |Z80_MEM2 |Z80_MEM1 |Z80_MEM0 |
| C | | | | | | | | | | | | | |Z80_A16 |Z80_A17 |Z80_A18 |Z80_A15 |Z80_A14 |Z80_A13 |Z80_A12 |Z80_A11 |Z80_A10 |Z80_A9 |Z80_A8 |Z80_A7 |Z80_A6 |Z80_A5 |Z80_A4 |Z80_A3 |Z80_A2 |Z80_A1 |Z80_A0 |
| D | | | | | | | | | | | | | | | | | | | | | | | | |Z80_RD |CTL_BUSACK |Z80_WR |Z80_RESET  |Z80_IORQ |Z80_MREQ |CTL_CLK |CTL_BUSRQ |
| E | | | | | |Z80_BUSACK| |SVCREQ  | | | | | | | | | | | | | | | | | | | | | | | | |

##### GPIO bits to Z80 Address Line mapping

| ADDR 18  | ADDR 17  | ADDR 16  | ADDR 15 | ADDR 14  | ADDR 13 | ADDR 12 | ADDR 11 | ADDR 10 | ADDR 9 | ADDR 8 | ADDR 7 | ADDR 6 | ADDR 5 | ADDR 4 | ADDR 3 | ADDR 2 | ADDR 1 | ADDR 0 |
|---|---|---|---|---|---|---|---|---|---|---|---|---|---|---|---|---|---|---|
|PORT C:16 | PORT C:17|PORT C:18 | PORT C:15 | PORT C:14| PORT C:13 | PORT C:12 | PORT C:11 | PORT C:10 | PORT C:9  | PORT C:8  | PORT C:7  | PORT C:6  | PORT C:5  | PORT C:4  | PORT C:3  | PORT C:2 | PORT C:1 | PORT C:0 |

##### GPIO bits to Z80 Data Line mapping

| DATA 7 | DATA 6 | DATA 5 | DATA 4 | DATA 3 | DATA 2 | DATA 1 | DATA 0 |
|---|---|---|---|---|---|---|---|
| PORT B:23 | PORT B:22 | PORT B:21 | PORT B:20 | PORT B:19 | PORT B:18 | PORT B:17  | PORT B:16  |

--------------------------------------------------------------------------------------------------------

### Z80 Memory Modes

<div style="text-align: justify">
One of the features of the tranZPUter SW-700 hardware design is the ability to create memory maps freely within the 512 macro cell CPLD. Any conceivable memory map within Z80 address space (or any soft-cpu address space upto 18 bits wide)
utilising the 512K Static RAM, 64K mainboard RAM, Video RAM, I/O can be constructed using a boolean equation and then assigned to a Memory Mode, The memory mode is then selected by Z80 software as required, ie. this ability is put to good
use in order to realise TZFS, CP/M and the compatible modes of the Sharp MZ-700 and MZ-80B.
<br><br>

The basis of the memory modes came from version 1 of the tranZPUter SW project where the decoder was based on a Flash RAM. All foreseen memory models required at that time, such as MZ-700, CP/M etc where devised. These modes have been enhanced in later designs
within the CPLD to cater for new features such as the Video Module and no doubt will be further enhanced in the future.
<br><br>

Modes which have been defined are in the table below leaving a few available slots for future expansion.
</div>

| Mode | Target | Range | Block&nbsp;&nbsp; | Function | DRAM Refresh | Description |
|---|---|---|---|---|---|---|
| 0 | Original | 0000:0FFF | Main  | MROM | Yes | Default, normal host (ie. Sharp MZ80A/MZ-700) operating mode, all memory and IO (except tranZPUter controlled I/O block) are on the mainboard |
| | | 1000:CFFF | Main  | D-RAM | | |
| | | D000:D7FF | Main  | VRAM | | |
| | | D800:DFFF | Main  | ARAM | | |
| | | E000:E7FF | Main  | MM I/O | | |
| | | E800:EFFF | Main  | User ROM | | |
| | | F000:FFFF | Main  | FDC ROM | | |
| 1 | Orig+ UROM  | 0000:0FFF | Main  | MROM | Yes | As 0 except User ROM is mapped to tranZPUter RAM and used for loadable BIOS images. |
| | | 1000:CFFF | Main  | D-RAM | | |
| | | D000:D7FF | Main  | VRAM | | |
| | | D800:DFFF | Main  | ARAM | | |
| | | E000:E7FF | Main  | MM I/O | | |
| | | E800:EFFF | RAM 0 | User ROM | | |
| | | F000:FFFF | Main  | FDC ROM | | |
| 2 | TZFS | 0000:0FFF | RAM 0 | MROM | No | Boot mode for TZFS or any other software requiring use of the tranZPUter RAM. User ROM appears as ROM to the Monitor so it will call the entry point at 0xE800 as part of it's normal startup procedure. The software stored at 0xE800 can switch out the mainboard and run in tranZPUter RAM as required. Two small holes at F3FE and F7FE exist for the Floppy disk controller (which have to be 2 bytes wude), these locations need to be on the mainboard. The floppy disk controller uses them as part of its data read/write as the Z80 isnt fast enough to poll the FDC. |
| | | 1000:CFFF | RAM 0 | Main RAM | | |
| | | D000:D7FF | Main  | VRAM | | |
| | | D800:DFFF | Main  | ARAM | | |
| | | E000:E7FF | RAM 0 | MM I/O | | |
| | | E800:EFFF | RAM 0 | User ROM | | |
| | | F000:FFFF | RAM 0 | FDC ROM | | |
| 3 | TZFS | 0000:0FFF | RAM 0 | MROM | No | Page mode for TZFS, all RAM in tranZPUter Block 0 except F000:FFFF which is in Block 1, this is page bank2 of TZFS. |
| | | 1000:CFFF | RAM 0 | Main RAM | | |
| | | D000:D7FF | RAM 0 | VRAM | | |
| | | D800:DFFF | RAM 0 | ARAM | | |
| | | E000:E7FF | RAM 0 | MM I/O | | |
| | | E800:EFFF | RAM 0 | User ROM | | |
| | | F000:FFFF | RAM 1 | FDC ROM | | |
| 4 | TZFS | 0000:0FFF | RAM 0 | MROM | No | As mode 3 but F000:FFFF is in Block 2, this is page bank3 of TZFS. |
| | | 1000:CFFF | RAM 0 | Main RAM | | |
| | | D000:D7FF | RAM 0 | VRAM | | |
| | | D800:DFFF | RAM 0 | ARAM | | |
| | | E000:E7FF | RAM 0 | MM I/O | | |
| | | E800:EFFF | RAM 0 | User ROM | | |
| | | F000:FFFF | RAM 2 | FDC ROM | | |
| 5 | TZFS | 0000:0FFF | RAM 0 | MROM | No | As mode 3 but F000:FFFF is in Block 3, this is page bank4 of TZFS. |
| | | 1000:CFFF | RAM 0 | Main RAM | | |
| | | D000:D7FF | RAM 0 | VRAM | | |
| | | D800:DFFF | RAM 0 | ARAM | | |
| | | E000:E7FF | RAM 0 | MM I/O | | |
| | | E800:EFFF | RAM 0 | User ROM | | |
| | | F000:FFFF | RAM 3 | FDC ROM | | |
| 6 | CP/M | 0000:FFFF | RAM 4 | Main RAM | No | CP/M, all memory on the tranZPUter board. Special case for F3C0:F3FF & F7C0:F7FF (floppy disk paging vectors) which resides on the mainboard. |
| 7 | CP/M | 0000:0100 | RAM 4 | CP/M Vectors | No | CP/M main CBIOS area, 48K + 2K available for the CBIOS and direct access to mainboard hardware. F000:FFFF remains in bank 4 and used as the gateway between this memory mode and mode 6. |
| | | 0100:CFFF | RAM 5 | Main RAM | | |
| | | D000:D7FF | Main  | VRAM | | |
| | | D800:DFFF | Main  | ARAM | | |
| | | E000:E7FF | Main  | MM I/O | | |
| | | E800:EFFF | RAM 5 | User ROM | | |
| | | F000:FFFF | RAM 4 | FDC ROM | | |
| 8 | Orig+ Emu | 0000:0FFF | Main  | MROM | Yes | Original mode but with the main RAM in the tranZPUter bank 0. This mode is used to bootstrap programs such as MZ-700 programs which bank change on startup and expect the loaded program to be within the main memory which is within a tranZPUter RAM bank. |
| | | 1000:CFFF | RAM 0 | Main RAM | | |
| | | D000:D7FF | Main  | VRAM | | |
| | | D800:DFFF | Main  | ARAM | | |
| | | E000:E7FF | Main  | MM I/O | | |
| | | E800:EFFF | Main  | User ROM | | |
| | | F000:FFFF | Main  | FDC ROM | | |
| 10 | MZ-700 | 0000:0FFF | RAM 6 | Main RAM | No | MZ-700 mode (OUT $E0) - Monitor RAM replaced with Main RAM |
| | | 1000:CFFF | RAM 0 | Main RAM | | |
| | | D000:D7FF | Main  | VRAM | | |
| | | D800:DFFF | Main  | ARAM | | |
| | | E000:E7FF | Main  | MM I/O | | |
| | | E800:EFFF | Main  | User ROM | | |
| | | F000:FFFF | Main  | FDC ROM | | |
| 11 | MZ-700 | 0000:0FFF | RAM 0 | MROM | No | MZ-700 mode (OUT $E0 + $E1) - I/O and Video block replaced with Main RAM |
| | | 1000:CFFF | RAM 0 | Main RAM | | |
| | | D000:D7FF | RAM 6 | VRAM | | |
| | | D800:DFFF | RAM 6 | ARAM | | |
| | | E000:E7FF | RAM 6 | MM I/O | | |
| | | E800:EFFF | RAM 6 | User ROM | | |
| | | F000:FFFF | RAM 6 | FDC ROM | | |
| 12 | MZ-700 | 0000:0FFF | RAM 6 | Main RAM | No | MZ-700 mode (OUT $E1 + $E2) - Monitor RAM replaced with RAM and I/O and Video block replaced with Main RAM |
| | | 1000:CFFF | RAM 0 | Main RAM | | |
| | | D000:D7FF | RAM 6 | VRAM | | |
| | | D800:DFFF | RAM 6 | ARAM | | |
| | | E000:E7FF | RAM 6 | MM I/O | | |
| | | E800:EFFF | RAM 6 | User ROM | | |
| | | F000:FFFF | RAM 6 | FDC ROM | | |
| 13 | MZ-700 | 0000:0FFF | RAM 0 | MROM | No | MZ-700 mode (OUT $E5) - Upper memory locked out, Monitor ROM paged in. |
| | | 1000:CFFF | RAM 0 | Main RAM | | |
| | | D000:FFFF | n/a | Undefined | | |
| 14 | MZ-700 | 0000:0FFF | RAM 6 | Main RAM | No | MZ-700 mode (OUT $E6) - Monitor RAM replaced with RAM and Upper memory locked out. |
| | | 1000:CFFF | RAM 0 | Main RAM | | |
| | | D000:FFFF | n/a | Undefined | | |
| 21 | K64F Access | 000000:FFFFFF | n/a | FPGA Resources | No | Access the FPGA memory by passing through the full 24bit Z80 address, typically from the K64F. |
| 22 | FPGA Access | 0000:FFFF | n/a | Host Resources | Yes | Access to the host mainboard 64K address space only. |
| 23 | K64F Access | 000000:FFFFFF | RAM | Main RAM | No | Access all memory and IO on the tranZPUter board with the K64F addressing the full 512K RAM. |
| 24 | K64F Access | 0000:FFFF | RAM 0 | Main RAM | Yes/No | All memory and IO are on the tranZPUter board, 64K block 0 selected. Mainboard DRAM is refreshed by the tranZPUter library when using this mode. |
| 25 | K64F Access | 0000:FFFF | RAM 1 | Main RAM | Yes/No | All memory and IO are on the tranZPUter board, 64K block 1 selected. Mainboard DRAM is refreshed by the tranZPUter library when using this mode. |
| 26 | K64F Access | 0000:FFFF | RAM 2 | Main RAM | Yes/No | All memory and IO are on the tranZPUter board, 64K block 2 selected. Mainboard DRAM is refreshed by the tranZPUter library when using this mode. |
| 27 | K64F Access | 0000:FFFF | RAM 3 | Main RAM | Yes/No | All memory and IO are on the tranZPUter board, 64K block 3 selected. Mainboard DRAM is refreshed by the tranZPUter library when using this mode. |
| 28 | K64F Access | 0000:FFFF | RAM 4 | Main RAM | Yes/No | All memory and IO are on the tranZPUter board, 64K block 4 selected. Mainboard DRAM is refreshed by the tranZPUter library when using this mode. |
| 29 | K64F Access | 0000:FFFF | RAM 5 | Main RAM | Yes/No | All memory and IO are on the tranZPUter board, 64K block 5 selected. Mainboard DRAM is refreshed by the tranZPUter library when using this mode. |
| 30 | K64F Access | 0000:FFFF | RAM 6 | Main RAM | Yes/No | All memory and IO are on the tranZPUter board, 64K block 6 selected. Mainboard DRAM is refreshed by the tranZPUter library when using this mode. |
| 31 | K64F Access | 0000:FFFF | RAM 7 | Main RAM | Yes/No | All memory and IO are on the tranZPUter board, 64K block 7 selected. Mainboard DRAM is refreshed by the tranZPUter library when using this mode. |

<font size="2">
<div style="text-align: left">
Key:<br>
    MROM       = Monitor ROM, the original boot firmware ie. SA-1510 <br>
    D-RAM      = Dynamic RAM on the mainboard. <br>
    VRAM       = Video RAM on the mainboard. <br>
    ARAM       = Colour Attribute RAM on the mainboard. <br>
    MM I/O     = Memory Mapped I/O controllers on the mainboard. <br>
    RAM 0 .. 7 = 64K RAM Block number within the 512K Static RAM chip. <br>
    Main       = Host computer mainboard, ie the Sharp MZ-80A mainboard. <br>
</div>
</font>

--------------------------------------------------------------------------------------------------------

### Z80 CPU Frequency Switching

<div style="text-align: justify">
In order to make the tranZPUter SW-700 compatible with other machines it is necessary to clock the CPU at the speed of that machine. It is also desirable to clock the CPU as fast as possible when using software such
as CP/M for maximum performance.
<br><br>

One of the main issues with frequency switching is that the underlying host cannot have its frequency changed, the host is generally generating the clock and it's circuits have been designed to operate within it's clock
tolerances. The tranZPUter SW-700 overcomes this limitation as described below.
<br><br>

To fulfil the requirement to have a switchable Z80 CPU frequency a positive edge triggered frequency switch has been implemented which takes the host frequency as one input and a square wave generator from the K64F as its second input.
The switching mechanism is tied to the bus control logic and so any access to the host will see the frequency of the CPU being changed to that of the host which ensures continued reliable operation. Under startup conditions, the Z80 is
always clocked by the host clock to ensure original specifications of the machine are met.
<br><br>

A second frequency can be selected if the K64F is present as it has the ability using its onboard timers to generate a programmable square wave output. The K64F sets the frequency of this second clock source
and the Z80 can select it via an I/O OUT command. This gives the software running on the Z80 the opportunity to change it's own frequency, albeit to a fixed set one. An extension to the K64F Host API allows the Z80 to make a request
of the K64F to set the Z80 CPU frequency to any possible value, this is useful in TZFS or CP/M so a user can select their own frequency.
<br><br>

Current testing on a CMOS Z84C0020 20MHz CPU has the following observations:
</div>

   * tranZPUter reliable in the range 1Hz to 24MHz for all functionality.
   * When the mainboard is accessed the frequency slows to 3.54MHz (ie. the system clock) and returns to the higher frequency after the mainboard access has completed.

<div style="text-align: justify"><br>
It is also possible to slow down the CPU for training or debugging purposes albeit access to the host circuitry will always run at the host clock frequency,
<br><br>

On an application running under the Z80, the following table outlines the I/O ports to which it must read/write in order to switch frequencies.
<br></div>

##### <u>Z80 CPU Frequency Switching Ports</u>

| Port | Dir  | Function |
| ---- | ---  | --- |
| 0x62 |  W | Switch Z80 CPU frequency to the second source, ie. the frequency generated by the K64F or external oscillator. |
| 0x64 |  W | Switch Z80 CPU frequency to default host source. This is the default on RESET. |
| 0x66 |  R | Bit [0] - Clock Selected, 0 = Host Clock, 1 = second clock source (K64F or external oscillator). |

--------------------------------------------------------------------------------------------------------

## System Configuration

The CPLD holds an internal configuration register to change how it operates with the underlying host. The table below outlines the ports along with each bits function.

##### <u>System Configuration Register (0x6E - 110 decimal)</u>

|  Bits | Dir  | Description |
|  ---- | ---  | --- |
|  2:0 | R/W  | Set hardware model compatibility. This configures the CPLD to remap host hardware to be compatible with the configured model.<br>000 = MZ-80K<br>001 = MZ-80C<br>010 = MZ-1200<br>011 = MZ-80A<br>100 = MZ-700<br>101 = MZ-800<br>110 = MZ-80B<br>111 = MZ-2000 |
|  3 | R/W  | Set the mainboard video state, 0 = enabled, 1 = disabled. If the mainboard video is enabled, the FPGA enhanced video will be disabled. |
|  4 | R/W  | Set the video wait state generator to be used during FPGA Video frame rendering, 0 = wait state disabled, 1 = enabled. |
|  7 | R/W  | Preserve configuration over reset (=1) or set to default on reset (=0). |

NB: The compatibility modes which have been implemented appear in the paragraphs below, all other modes are yet to be implemented. Selecting a mode which hasnt been implemented results in no mapping and reverts to the base MZ-700 hardware.

The CPLD also holds a read only information register which indicates the capabilities of the running machine.

##### <u>System Information Register (0x6F - 111 decimal)</u>

|  Bits | Dir | Description |
|  ---- | --- | --- |
|  2:0 |  R  | The underlying host model in which the tranZPUter is installed, ie. the physical computer hardware.<br>000 = MZ-80K<br>001 = MZ-80C<br>010 = MZ-1200<br>011 = MZ-80A<br>100 = MZ-700<br>101 = MZ-800<br>110 = MZ-80B<br>111 = MZ-2000 |
|  3 |  R  | FPGA Video Module installed, 0 = not installed, 1 = installed. |
|  7:5 |  R  | Version number of the CPLD. Used by Z80 code when newer versions of the CPLD VHDL provide differing features.  |

--------------------------------------------------------------------------------------------------------

## Soft Processors

<div style="text-align: justify">
One of the primary goals of the tranZPUter project was to be able to run various physical processors on a host machine. In this project, the host is a Sharp MZ series computer utilizing a Zilog Z80 processor but the board and concept could quite easily be used on another
host architecture, such as the BBC Micro Model B using the MOS 6502 CPU.
<br><br>

In the FPGA or even ASIC world, the word 'soft' can often be used out of context. A 'soft' processor isnt a software emulation, it
is a physical hardware device described in a HDL which can be instantiated and used inside an FPGA or masked onto an ASIC. The 'soft' is more relevant to FPGA where you can change the actual hardware device by uploading a new interconnect map at will. This
is because an FPGA (Field Programmable Gate Array) is a mass of electronic components with an interconnect layer and this interconnect layer is like RAM where a '1' will link two components together. You load up an interconnect bit map either by a
JTAG programming tool or via one of the FPGA's supported protocols such as a serial Flash configuration device. Once a device is instantiated and its interconnect loaded, it behaves like any other piece of hardware and so a 'soft' processor in an FPGA, when running,
is the same as any other 'hard' processor. 
<br><br>

Initially, to work out the framework for a 'soft' CPU to exist in the FPGA yet control the underlying Sharp MZ-700 hardware I chose to embed a T80 processor. This is a redesign of the venerable Zilog Z80 and achieves near cycle accuracy implementing all the documented
and undocumented instructions and presenting the correct hardware signals for external use. The design required changes in the CPLD as it now had to be a bidirectional gateway along with instantiation of a T80 processor and support logic within the FPGA. The end result was a processor,
running in the FPGA on a Sharp MZ-700 which was identical to the 'hard' Z80 running on the tranZPUter card.
<br><br>
Apart from aiding in the framework design, the 'soft' T80 has no advantages over a 'hard' Z80 except that you can modify the architecture/instructions for research 
or to aid a program speed and optionally choose the enhanced 'fast' mode of the T80. The actual Fmax is slower than the 'hard' Z80 due to the switching and propogation delays of the FPGA/CPLD, the 'hard' Z80 can run at 24MHZ, the T80 tops out at 18MHz. NB. If RAM was instantiated on the
FPGA and the T80 ran from FPGA BRAM instead of the hard 512K static RAM on the tranZPUter card it would achieve speeds upto 120MHz as it does in my Sharp MZ Series Emulator but this would require reworking of the control software (TZFS and the 1Z-013A monitor) as the memory model would be different.
<br><br>

Keeping with the Z80 theme, the AZ80 and the NextZ80 were added as build time choices (instead of the T80) for evaluation and comparison. The AZ80 has some slight I/O timing issues which result in an odd spurious keyboard read but otherwise runs flawlessly with all the MZ-700 software I tested. The NextZ80 is more of an instruction
compatible Z80 processor and doesnt present all the correct signals or follow the Z80 timing cycles, so more work is needed to make it run correctly.
</div>

The second processor added is the ZPU Evolution, a 32bit stack based processor originally written by Øyvind Harboe from [Zylin AS](https://opensource.zylin.com/) as a minimal logic size CPU to run in a supervisory mode in embedded systems. There have been a few extensions to the
design, the ZPU Flex and ZPUINO of note, but both didnt offer what I wanted for embedding into the Sharp MZ Series Emulator, so I redesigned it to gain speed and expandability creating the [ZPU Evolution](/zpu-evo/).

As the ZPU Evolution was intended to be embedded, [zOS](/zos/) was written with this functionality in mind, an OS which would run tasks inside a device to enhance it's functionality along with provision of an interactive session over a serial connection. Using a console connected to the serial connection you would be presented with
an MS-DOS like environment where you could run applications, control hardware or inspect/update memory and process flow, an ideal tool to work with a 'soft' ZPU Evolution running inside an FPGA which in turn was running inside an end application such as the Sharp MZ Series Emulator. When the tranZPUter SW project was born, zOS
was ported to the K64F which has been a great asset, being able to connect inside the tranZPUter SW and the Sharp MZ host has aided design and debug immensely. 

Adding a ZPU Evo into the tranZPUter SW-700 as a 'soft' processor required zOS to evolve, it no longer had serial connectivity and was required to control keyboard, screen etc directly. This led to the SharpMZ module being added which provides zOS with the basic hardware abstraction layers to drive the Sharp MZ-700 keyboard and screen, providing
the basic user I/O functionality including an ANSI terminal emulator. When the ZPU is selected from the Sharp MZ-700 monitor, zOS boots and you are presented with an interactive, MS-DOS like environment. There are some basic applications such as tbasic, mbasic. kilo (a VT100 based screen editor) and these can all be found in the [apps](/apps/) section of zOS.
As can be imagined, there isnt a lot of software to be run under zOS, although a lot of open source projects can be ported, the limiting factor is the GNU C/C++ 99 standard compiler or missing features such as thread control and virtual memory.

<div style="text-align: justify">
The ZPU and zOS are really for research and development and not meant for an end user. It is useful to learn the ZPU architecture, to design a processor or an OS so would benefit a student of electronics or computers immensely.
</div>

I am currently looking at instantiating a NIOSII processor with MMU as the FPGA has the resources to implement this processor and its support circuits and the end result would be Linux running on a Sharp MZ-700. This would be a far more useful platform so consider this is work in progress until completed and this page updated.

### CPU Configuration Registers

##### <u>CPU Configuration Register (0x6C - 108 decimal)</u>

|  Bits | Dir  | Description |
|  ---- | ---  | --- |
|  5:0 | R/W  | This register configures the FPGA to enable a soft/hard CPU and the CPLD is reconfigured to allow a CPU operation on the FPGA side rather than the physical hardware side.<br>Only one processor can be selected at one time, 1 bit per processor. Multiple bit selection will be voided and the hard processor selected.<br>000000 = Hard CPU <br>000001 = T80 CPU <br>000010 = ZPU Evolution <br>000100 = NIOS11<br>001000 = Future CPU 4 <br>010000 = Future CPU 5 <br>100000 = Future CPU 6 |
|  6 | R/W  | Clock enable. Enable (1) or disable the soft CPU clock. |
|  7 | R/W  | CPU Reset. When set to active ('1'), a reset pulse is generated and the bit state returned to 0. |

The FPGA holds a read only information register which indicates the soft processor capabilities.

##### <u>CPU Information Register (0x6D - 109 decimal)</u>

|  Bits | Dir | Description |
|  ---- | --- | --- |
|  5:0 |  R  | Bit mask, a 1 indicates a processor is available.<br>000000 = Hard CPU only<br>000001 = T80 CPU <br>000010 = ZPU Evolution <br>000100 = NIOSII<br>001000 = Future CPU 4 <br>010000 = Future CPU 5 <br>100000 = Future CPU 6 |
|  7:6 |  R  | Soft CPU capabilities, 01 = soft cpu capable, all other values indicate soft cpu capabilities not available. |

### ZPU Memory Map.

The ZPU has a configurable linear address space, typically 18-32 bit wide. When used as a soft processor it is configured for 24bit.

| Address Range | Sub Range |  Description |
| --- | --- |  --- |
| 000000:020000 | 000000:013FFF  |  zOS Kernel. |
| | 014000:01BFFF  |  Heap. |
| | 01C000:01FD7F  |  Stack. |
| | 01FD80:01FFFF  |  I/O processor service control record. Used for inter processor communications between the ZPU and the K64F so that the ZPU can make service calls, ie. read SD card. |
| 100000:180000 | |  512Kbyte 8bit wide static RAM on tranZPUter board. Applications are loaded and run from this area of RAM starting at 0x100000. |
| D00000:EFFFFF | |  Z80 Bus State Machine.  Depending on the accessed address will determine the type of transaction. In order to provide byte level access on a 32bit read CPU, a bank of addresses, word aligned per byte is assigned in addition to an address to read 32bit word aligned value. |
| | D00000:D7FFFF  | 512K Static RAM on the tranZPUter board. All reads are 32bit, all writes are 8, 16 or 32bit wide on word boundary. |
| | D80000:DBFFFF  | 64K address space on host mainboard (ie. RAM/ROM/Memory mapped I/O) accessed 1 byte at a time. The physical address is word aligned per byte, so 4 bytes on the ZPU address space = 1byte on the Z80 address space. ie. 0x00780 ZPU = 0x0078 Z80. |
| | DC0000:DFFFFF  | 64K I/O space on the host mainboard or the underlying CPLD/FPGA. 64K address space is due to the Z80 ability to address 64K via the Accumulator being set in 15:8 and the port in 7:0. The ZPU, via a direct address will mimic this ability for hardware which requires it. ie. A write to 0x3F with 0x10 in the accumulator would yield an address of 0xF103f.  All reads are 8 bit, writes are 8, 16 or 32bit wide on word boundary. The physical address is word aligned per byte, so 4 bytes on the ZPU address space = 1byte on the Z80 address space. ie. 0x00780 ZPU = 0x0078 Z80. |
| | E00000:E0FFFF  | 64K address space on host mainboard (ie. RAM/ROM/Memory mapped I/O) accessed 4 bytes at a time, a 32 bit read will return 4 consecutive bytes, start of read must be on a 32bit word boundary.
| | E80000:EFFFFF  | 512K Video address space - the video processor memory is directly mapped into ZPU memory address space. See the Video controller direct access mode below for a detailed explanation.
| | E80000:E8FFFF  | 64K Video / Attribute RAM
| | E90000:E9FFFF  | 64K Character Generator ROM/PCG RAM.
| | EA0000:EBFFFF  | 128K Red Framebuffer address space.
| | EC0000:EDFFFF  | 128K Blue Framebuffer address space.
| | EE0000:EFFFFF  | 128K Green Framebuffer address space.
| F00000:FFFFFF | F00800:F008FF  |  Interrupt Controller. Spacing between interrupt controller devices = 0x10. |
| | F00800:F00803  | Status Register. |
| | F00804:F00807  | Control Register. |
| | F00900:F009FF  |  SD Card Controller. |
| | F00900:F00903  | Address Register. |
| | F00904:F00907  | Data Register. |
| | F0090c:F0090f  | Status Register. |
| | F00C00:F00CFF  |  Timer. Spacing between timer devices = 0x40. |
| | F00C00:F00C3F  |  Timer 0. |
| | F00C00:F00C03  | TIMER_MICROSEC_DOWN - Programmable microsecond down counter. |
| | F00C04:F00C07  | TIMER_MILLISEC_DOWN - Programmable millisecond down counter. |
| | F00C08:F00C0B  | TIMER_MILLISEC_UP - Programmable millisecond up counter. |
| | F00C0C:F00C0F  | TIMER_SECONDS_DOWN - Programmable second down counter. |
| | F00C1C:F00C1F  | RTC_MILLISECONDS_EPOCH - Real Time milliseconds since EPOCH. |
| | F00C20:F00C23  | RTC_MICROSECONDS - Real Time microseconds count in current second. |
| | F00C24:F00C27  | RTC_MILLISECONDS - Real Time milliseconds count in current second. |
| | F00C28:F00C2B  | RTC_SECOND - Real Time seconds count. |
| | F00C2C:F00C2F  | RTC_MINUTE - Real Time minutes count. |
| | F00C30:F00C33  | RTC_HOUR - Real Time hours count. |
| | F00C34:F00C37  | RTC_DAY - Real Time days in month count. |
| | F00C38:F00C3B  | RTC_MONTH - Real Time month in year count.  |
| | F00C3C:F00C3F  | RTC_YEAR - Real Time current year count. |
| | F00C40:F00C7F  |  Timer 1 .. n, hardware build dependent. |
| | F00C40:F00C43  | Enable Register. |
| | F00C44:F00C47  | Index Register. |
| | F00C48:F00C4b  | Counter Register. |
| | F00F00:F00FFF  |  System on Chip Configuration. |
| | F00F00:F00F03  | SOCCFG_ZPU_ID - ID of the instantiated ZPU |
| | F00F04:F00F07  | SOCCFG_SYSFREQ - System Clock Frequency in MHz x 10 (ie. 100MHz = 1000) |
| | F00F08:F00F0B  | SOCCFG_MEMFREQ - Sysbus SDRAM Clock Frequency in MHz x 10 (ie. 100MHz = 1000) |
| | F00F0C:F00F0F  | SOCCFG_WBMEMFREQ - Wishbone SDRAM Clock Frequency in MHz x 10 (ie. 100MHz = 1000) |
| | F00F00:F00F03  | SOCCFG_DEVIMPL - Bit map of devices implemented in SOC. |
| | F00F04:F00F07  | SOCCFG_BRAMADDR - Address of Block RAM. |
| | F00F08:F00F0B  | SOCCFG_BRAMSIZE - Size of Block RAM. |
| | F00F0C:F00F0F  | SOCCFG_RAMADDR - Address of RAM (additional BRAM, DRAM etc). |
| | F00F00:F00F03  | SOCCFG_RAMSIZE - Size of RAM. |
| | F00F04:F00F07  | SOCCFG_BRAMINSNADDR - Address of dedicated instruction Block RAM. |
| | F00F08:F00F0B  | SOCCFG_BRAMINSNSIZE - Size of dedicated instruction Block RAM. |
| | F00F0C:F00F0F  | SOCCFG_SDRAMADDR - Address of SDRAM. |
| | F00F00:F00F03  | SOCCFG_SDRAMSIZE - Size of SDRAM. |
| | F00F04:F00F07  | SOCCFG_WBSDRAMADDR - Address of Wishbone SDRAM. |
| | F00F08:F00F0B  | SOCCFG_WBSDRAMSIZE - Size of Wishbone SDRAM. |
| | F00F0C:F00F0F  | SOCCFG_CPURSTADDR - Address CPU executes after a RESET. |
| | F00F00:F00F03  | SOCCFG_CPUMEMSTART - Start address of Memory containing BIOS/Microcode for CPU. |
| | F00F04:F00F07  | SOCCFG_STACKSTART - Start address of Memory for Stack use. |

--------------------------------------------------------------------------------------------------------

## Video Module

<div style="text-align: justify">
The Video Module, on the v1.2 board is based around an Altera Cyclone III FPGA with 76KB internal B(lock)RAM and 25K Logic Elements (groups of configurable logic gates). On the updated v1.3 board it is based around an
Altera Cyclone IV E75/E115 with 360K/480K and 75K/115K Logic Elements.
<br><br>

Using the FPGA allows the tranZPUter SW-700 to provide video capabilites for nearly all the Sharp MZ series, ie: MZ-80K, MZ-80C, MZ-1200, MZ-80A, MZ-700, MZ-80B (including graphics). In the near future the video capabilities will be upgraded to
include the MZ-800 and MZ-2000 machines. To use a specific machines video capabilities, a mode (described below) is written into the mode register to select the required video capabilites based on machine model and you then use the normal methods
of accessing the video of the selected machine ie. 0xD000-0xD7FF for video on an MZ-80A. This includes functions such as the invert or hardware scroll functionality.
<br><br>

An addition to the original Sharp MZ series capabilites, is the addition of a 640x200/320x200 8 colour Graphics frame buffer. This frame buffer is made up of 3x16K RAM blocks, 1 per colour with a resolution of 640x200 which matches the output display
buffer bit for bit.  If the display is working at 40x25 characters then the resolution is 320x200, otherwise for 80x25 it is 640x200.
<br><br>

For all modes except 640x200 (limitation only the Cyclone III) the display is double buffered whereby the image is assembled in a seperate buffer to the one which is rendered for screen display. Due to lack of memory in the Cyclone III FPGA, in 640x200 mode the display isnt double buffered
and therefore an optional WAIT state generator can be enabled to prevent screen snow/tear as required. The Cyclone IV has sufficient RAM to double buffer, as per the Sharp MZ Series Emulator from where the video logic design was taken.
<br><br>

The RAM for the Graphics frame buffer can be switched into the main CPU address range C000H – FFFFH by programmable registers, 1 bank at a time (ie. Red, Green, Blue banks). This allows for direct CPU addressable pixels to be read and/or written.
Each pixel is stored in groups of 8 (1 byte in RAM) scanning from right to left per byte, left to right per row, top to bottom. Ie. if the Red bank is mapped into CPU address space, the byte at C000H represents red pixels 7 - 0 of 320/640 (X) at pixel
0 of 200 (Y). Thus 01H written to C000H would set Pixel 7 (X), Row 0 (Y) to On, 80H written to C000H would set pixel 0 (X), Row 0 (Y) . This applies for Green and Blue banks when mapped into CPU address space.
<br><br>

In order to speed up the display, there is a Colour Write register (similar to what is available on the Sharp MZ-2500), so that a write to the graphics RAM will update all 3 banks at the same time which allows for immediate colour write.
</div>

### Programmable Registers

In order to make use of the video functionality a set of registers have been designed through which all functions can be accessed. 

The functionality is grouped as follows:
 <ul>
   <li style="margin: 1px 0"> Control  - set the video capability mode, set the column width, set the colour/mono capabilities.</li>
   <li style="margin: 1px 0"> Graphics - configure the graphics capability.</li>
   <li style="margin: 1px 0"> GPU - offload tasks to the inbuilt graphics processor to speed up video tasks.</li>
   <li style="margin: 1px 0"> Palette - set and configure the display palette.</li>
 </ul>

The registers lie in the upper I/O region from 0xD0 - 0XFD and are accessed with standard Z80 I/O commands IN/OUT. Unless otherwise stated, all registers are read/write and a read will return the current value stored.

##### <u>Control Register (0xF8 - 248 decimal)</u>

This is the video mode register. It specifies the hardware model the Video Module should function as in addition the column width and colour abilities of the output display.

|  Bits | Dir  | Description |
|  ---- | ---  | --- |
|  2:0 | R/W  | Set the hardware model of the Video Module.<br>000 = MZ-80K<br>001 = MZ-80C<br>010 = MZ-1200<br>011 = MZ-80A<br>100 = MZ-700<br>101 = MZ-800<br>110 = MZ-80B<br>111 = MZ-2000 |
|  3 | R/W  | Set the column width of the video output. 0 = 40 Column, 1 = 80 Column |
|  4 | R/W  | Set the colour capabilities of the video output. 0 = Monochrome, 1 = Colour.  |
|  5 | R/W  | Enable the Programmable Character Generator RAM. 0 = disabled, 1 = enabled. |
|  7:6 | R/W  | Set the VGA mode.<br>00 = Original MZ video format, 15.62KHz Horizontal x 60Hz Vertical.<br>01 = VGA 640x480 @ 60Hz<br>10 = VGA 1024x768 @ 60Hz<br>11 = VGA 800x600 @ 60Hz. |

##### <u>Graphics Mode Register (0xF9 - 249 decimal)</u>

This is the graphics mode control register. It specifies what video is to be output, how it is blended and which Graphics RAM bank can be read/written to.

|  Bits | Dir  | Description |
|  ---- | ---  | --- |
|  1:0 | R/W  | Read mode (00=Red Bank, 01=Green Bank, 10=Blue Bank, 11=Not used). Select which bank to be read when enabled in CPU address space. |
|  3:2 | R/W  | Write mode (00=Red Bank, 01=Green Bank, 10=Blue Bank, 11=Indirect). Select which bank to be written to when enabled in CPU address space.  |
|  4 | R/W  | VRAM Output. 0=Enable, 1=Disable. Output Character RAM to the display. |
|  5 | R/W  | GRAM Output. 0=Enable, 1=Disable. Output Graphics RAM to the display. |
|  7:6 | R/W  | Blend Operator (00=OR ,01=AND, 10=NAND, 11=XOR). Operator to blend Character display with Graphics Display. |

##### <u>Colour Writer Registers (0xFA - 250 decimal to 0xFC - 252 decimal)</u>

<div style="text-align: justify">
The colour writer register is a bit map which is applied to each colour frame buffer during an indirect write (ie. all 3 colour pages at once).
<br><br>

For Indirect mode (Control Register bits 3/2 set to 11), a write to the Graphics
RAM when mapped into CPU address space C000H – FFFFH will see the byte masked by the Red Colour Writer Register and written to the Red Bank with the same operation for Green and Blue. This allows rapid setting of a colour across the 3 banks.
<br><br>

ie. Red Filter = 0x80, Green Filter = 0x40, Blue Filter = 0x20, then an indirect write to address C000H will set pixel 0,0 to red, 1,0 to green, 2,0 to blue.
<br><br>
</div>

| Bit  | Dir  | Pixel  | I/O Addr | Colour | Description |
| ---  | ---  | -----  | --- | --- | --- |
| 0 | R/W  | 7 | 0xFAH | Red | Set to Red during indirect write.  |
| 1 | R/W  | 6 | 0xFAH | Red | |
| 2 | R/W  | 5 | 0xFAH | Red | |
| 3 | R/W  | 4 | 0xFAH | Red | |
| 4 | R/W  | 3 | 0xFAH | Red | |
| 5 | R/W  | 2 | 0xFAH | Red | |
| 6 | R/W  | 1 | 0xFAH | Red | |
| 7 | R/W  | 0 | 0xFAH | Red | Set to Red during indirect write.  |
| 0 | R/W  | 7 | 0xFBH | Green | Set to Green during indirect write.|
| 1 | R/W  | 6 | 0xFBH | Green | |
| 2 | R/W  | 5 | 0xFBH | Green | |
| 3 | R/W  | 4 | 0xFBH | Green | |
| 4 | R/W  | 3 | 0xFBH | Green | |
| 5 | R/W  | 2 | 0xFBH | Green | |
| 6 | R/W  | 1 | 0xFBH | Green | |
| 7 | R/W  | 0 | 0xFBH | Green | Set to Green during indirect write.|
| 0 | R/W  | 7 | 0xFCH | Blue | Set to Blue during indirect write. |
| 1 | R/W  | 6 | 0xFCH | Blue | |
| 2 | R/W  | 5 | 0xFCH | Blue | |
| 3 | R/W  | 4 | 0xFCH | Blue | |
| 4 | R/W  | 3 | 0xFCH | Blue | |
| 5 | R/W  | 2 | 0xFCH | Blue | |
| 6 | R/W  | 1 | 0xFCH | Blue | |
| 7 | R/W  | 0 | 0xFCH | Blue | Set to Blue during indirect write. |

##### <u>Memory Page Registers (0xFD - 253 decimal)</u>

This register is responsible for enabling Video memory into Z80 address space. It is possible to enable 1 of the 3 colour 16KB GRAM (chosen via the Graphics Mode register) into Z80 address C000:FFFF or the CGROM into Z80 address space D000:DFFF. This register
overrides all other memory page settings.

|  Bits | Dir  | Description |
|  ---- | ---  | --- |
|  0 | R/W  | Switches in a 16Kb graphics ram bank to C000 - FFFF. The bank (or colour) is selected by the Graphics Mode register.<br>0 = Off, normal Z80 memory operations.<br>1 = 16KB GRAM enabled.<br>Setting this register overrides all MZ-700/MZ-80B specific memory page settings. |
|  7 | R/W  | Switches in CGROM for upload at D000:DFFF. 0 - Normal memory operations, 1 - CGROM paged in. |

##### <u>Video Module Status Register (0xFD - 253 decimal)</u>

This register reports on the Video Module status. Bits 7 & 0 are reserved for reporting the Memory Page register settings.

|  Bits | Dir  | Description |
|  ---- | ---  | --- |
|  5 |  R | Framebuffer Horizontal Blanking. 1 = Horizontal Blanking active, 0 = no horizontal blanking. |
|  6 |  R | Framebuffer Vertical Blanking. 1 = Vertical Blanking active, 0 = no vertical blanking. |

##### <u>GPU Parameters Register (0xF6 - 246 decimal)</u>

<div style="text-align: justify">
This register is a 128bit push/pop register for storing parameters to be used by a GPU command. The actual contents varies according to the command issued (ie. see GPU command description below). Every push into this register shifts the current 128bits left by 8 bits and then stores the
new value into bits 7:0. 
<br><br>

A read from this register pops off bits 7:0 then shifts the register right by 8 bits.
</div>

##### <u>GPU Command Register (0xF7 - 247 decimal)</u>

<div style="text-align: justify">
The FPGA implements a basic Graphics Processing Unit which will expand in functionality over time. Currently the commands it executes are in the table below. To use the GPU, you first push any required parameters into the parameter register via the GPU Parameters Register at I/O port 0xF5.
You then issue the command and poll the status flag awaiting completion.
<br><br>
</div>

| Command  | Parameters  | Description |
| ---  | ---  | --- |
|  0x00 | n/a | No operation. This is the idle state command when the GPU isnt busy, issuing it performs no action. |
|  0x01 | n/a | Clear VRAM screen. The entire video and attribute RAM are cleared to space character (ie. blank) with white characters on a blue background. |
|  0x02 | [15:8] - character<br>[7:0] - attribute byte | Clear VRAM screen with char and attribute. The entire video and attribute RAM are cleared to the values given in the parameter list. |
|  0x03 | [47:40] - Start X<br>[39:32] - Start Y<br>[31:24] - End X<br>[23:16] - End Y<br>[15:8] - display char<br>[7:0] - attribute byte. | A portion of the video and attribute RAM are cleared to the given character and attribute value, starting at Start X/Y and finishing at End X/Y. |
|  0x81 | n/a | The entire 16KB frambuffer (red/green/blue) is cleared. |
|  0x82 | [87:72] - Start X<br>[71:56] - Start Y<br>[55:40] - End X<br>[39:24] - End Y<br>[23:16] - Red Filter<br>[15:8] - Green Filter<br>[7:0] - Blue Filter<br>R/G/B Filters are 8 pixel wide, bit 7 is the leftmost pixel. | A section of the 16KB frambuffer (red/green/blue) is cleared according to the given parameters. Cleared area is from Start X/Y to End X/Y and the filters set the pixels in this area according to their values. 1 = set the corresponding pixel, 0 - clear the corresponding pixel. |
|  0xFF | n/a | Reset the GPU. Cancel any running operation and return to idle state immediately. |

##### <u>GPU Status Register (0xF7 - 247 decimal)</u>

This register returns the current GPU status and should be polled before each new command is requested.

|  Bits | Dir  | Function | Description |
|  ---- | ---  | --- | --- |
| 0 | R | BUSY | Flag to indicate busy status of the GPU. 1 = Busy, 0 = Idle. If busy no further command will be processed until the GPU returns to Idle except the RESET command which will be acted on immediately. |

##### <u>VGA Border Area Register (0xF3 - 243 decimal)</u>

In VGA modes, the expansion of the graphics RAM/VRAM doesnt quite fill the entire display area which is normally left blank. This register allows attributes to be set so that different colours can be applied as needed.

|  Bits | Dir  | Description |
|  ---- | ---  | --- |
|  2:0 | R/W  | Set the border colour.<br>2: = Red<br>1: = Green<br>0: = Blue |

##### <u>Select Palette Register (0xF5 - 245 decimal)</u>

<div style="text-align: justify">
This register selects the active palette.  The Video Module supports 4 (5 bits on the tranZPUter SW-700) bits per colour output but there is only enough RAM for 1 bit per colour so the pallette is used to change the colours output.
<br><br>
There are 256 palettes, 0 is the default with system colours, 1..255 are fixed palettes at time of FPGA HDL compilation. The palettes can be reprogrammed via the palette configuration registers described below.
<br><br>
On the tranZPUter SW-700, bit 4 selects a shade of sub-colours for the given colour in bits 3:0. The hardware uses bit 4 to drive a digital output when in original mode and when in FPGA mode it can be configured to 1 which will select a set
of sub-colours or 0 for standard RGB 3:0 colours.
</div>

##### <u>Select Palette Configration Off Pointer Register (0xD3 - 211 decimal)</U>

This register sets the palette number to be configured when a pixel (R/G/B) is in the off state. ie. colour to be output when the pixels are off. A write to this register is made prior to writing into the actual palette colour registers.

##### <u>Select Palette Configration On Pointer Register (0xD4 - 212 decimal)</U>

This register sets the palette number to be configured when a pixel (R/G/B) is in the on state. ie. colour to be output when the pixels are on. A write to this register is made prior to writing into the actual palette colour registers.

##### <u>Set Palette Red Value Register (0xD5 - 213 decimal)</U>

This register sets the 5 bit Red value to be used in the palette selected via The Off/On Pointer Registers.

##### <u>Set Palette Green Value Register (0xD6 - 214 decimal)</U>

This register sets the 5 bit Green value to be used in the palette selected via The Off/On Pointer Registers.

##### <u>Set Palette Blue Value Regist

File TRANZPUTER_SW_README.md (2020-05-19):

## Foreword

The tranZPUter and tranZPUter SW are actively being developed and changes are reflected in the documentation on a regular basis.

The tranZPUter SW is an offshoot from the tranZPUter project and utilises a Freescale K64F processor as the IO Control processor as opposed to the ZPU in the original tranZPUter project.

During testing of the tranZPUter v1.0 and with the advent of the RFS v2.0 upgrade with CP/M it was noticed that the tranZPUter should be updated so that the Z80 had additional memory
and was able to run at higher clock frequencies. It should also run independent of the controlling IO processor, ie. the ZPU Evo on FPGA fabric.

V1.0 of the tranZPUter had design restrictions which in all honesty make the project much harder to complete, for example, because of my lack of experience soldering BGA (Ball Grid Array)
IC's, I chose the next best thing, a pre-fab FPGA board, the CYC1000 with the FPGA already soldered. This device and all other possibilities for the given size and FPGA ALM requirements had
too few general I/O pins. This meant that multiplexing had to be used with tri-state register latches. KISS comes back to mind, Keep It Simple Stupid! So in order to further the concept
and design I took a step back, looked at what was needed at the Z80 side to realise the CP/M requirements and looked at what was needed for the controlling IO Processor. As I am still not
happy about soldering a 30+ pound IC where only an X-Ray machine can validate that it was soldered correctly, I opted for a powerful mini-development board, the Teensy 3.5 which has more
than enough general I/O pins and is 5V tolerant, hence this interim design (which is actually better for anyone who is a software programmer and is not happy with electronics or VHDL yet 
wants to enhance a Z80 machine). Everything will be written in C/C++ and once working, I can take the bold step into speccing a tranZPUter v2.0 with a BGA knowing that the ZPU will run all
the software just written.

## Overview

The Sharp MZ80A is based on the Z80 CPU running at 2MHz. It is vintage and under powered compared with modern computers (or a Raspberry Pi). Besides being part of history, it has a software
base that is useful from time to time and still has followers. A software Emulator could be written to prolong the usage of the software but there is something special about using original
hardware and this is an alternative to keep the machine original yet provide an upgrade that can power the machine with additional processing capabilities, storage and with multiple different
CPU's based in software like the PiCoPro on the BBC Micro. This is all made possible with bus mastering where the original CPU is tri-stated and the K64F takes control of the bus and the
underlying original mainboard peripherals, when needed.

The upgrade also extends the Z80 hardware capabilities by providing additional RAM to allow for a 64K version of CP/M and to increase the speed of the processor whilst maintaining the
original speed when accessing the Sharp MZ80A motherboard peripherals.

This design is a work in progress, working in tandem with the tranZPUter. The C/C++ control software written for the tranZPUter SW will also work on the tranZPUter under the ZPU.

As the design replaces a Z80 in-situ it is not limited to the MZ80A but can be used in any Z80 based computer with the right software adaptations.

## tranZPUter SW

The tranZPUter gets its name from: A TRANsformable ZPU compuTER as the base CPU in the original tranZPUter is the ZPU Evo. The ZPU Evo provides the Menu, SD, Video Overlay services to the
Sharp MZ80A by tri-stating the original Z80 and accessing the MZ80A memory and peripherals as though they were ZPU devices.

The tranZPUter SW makes an improvement on the Z80 hardware and uses a Freescale K64F ARM Cortex-M4 in place of the ZPU Evo. As the K64F is a software solution rather than the ZPU Evo which
is based on VHDL in an FPGA, the project adds the suffix SW for *S*oft*W*are.

To provide different CPU's it is just a matter of taking existing CPU emulators, for example those used in the PiCoPro and adapting them to use the CPU signals on the MZ80A bus via this
designs interface. The program memory could either be that on the MZ80A or the faster K64F memory. ie. There is no real need to use the MZ80A memory when using a soft CPU. The benefits
of using a soft CPU is potentially better performance albeit this is yet to be determined as the K64F only runs at 120MHz. The design of the tranZPUter SW upgrades the Z80 hardware and can
clock the processor, detached from the Sharp MZ80A motherboard, at much higher clock rates, potentially to 20MHz using the Z8400 20MHz CPU. Higher CPU performance will be a benefit to
programs such as CP/M or databases such as DBase II.

In the gallery are pictures of the current design and files uploaded onto github are relatively stable, WIP files wont be uploaded as they are in constant flux.

### Hardware

Sheet 1

The basics of this design lie in Z80 bus mastering, ie. the ability to switch the Z80 out of circuit and control the computer as required. Bus mastering was typically used by devices such as
DMA for fast transfer of data from an I/O device to memory, or memory to memory for applications such as video/graphics. The device taking control of the Z80 bus could transfer data much
faster than the Z80 running a program, hence the benefit.

In this design, the bus mastering is used in a similar vein, taking control of the Z80 bus to transfer data between main memory and an SD Card or between the I/O processor and the Video display
buffer for presentation of menu's. It is also used where a soft processor completely idle's the hard Z80 and acts as the main computer CPU. ie. using a soft CPU emulator, it can process
applications in local memory and slow down to access I/O and the Video buffer on the host machine as needed presenting a completely different computing experience. Imagine, a 6809 or a 68000
based Sharp MZ80A!

The design centres around lifting the original Z80 onto a daughter card and rerouting several of its signals such that they can be controlled as needed. In order to be able to run programs
for other Sharp models (ie.MZ-700) or 64K CP/M the design adds a 512KB Static RAM device with necessary paging logic. As the design needs to be flexible at this stage on memory remapping
(ie. mapping blocks of the underlying Sharp MZ80A address space out and mapping in blocks of the 512Kbyte static RAM), a programmable decoder in the form of a Flash RAM is used. This allows
maximum flexibility during development to settle on a final set of memory maps for required functionality and a v2.0 of this project can use hardwired logic in a PAL/GAL rather than the Flash RAM
to save cost and board space.

The above schematic has been designed such that no IO processor is needed, just plug this board into the Z80 socket on the Sharp MZ80A, update the RFS software and you have an enhanced machine. Add the
IO Control processor (a Teensy 3.5) and suddenly a whole new range of options becomes available. Using this design it will be easier to use an FPGA in place of the Teensy 3.5 for the final 
tranZPUter project.

Sheet 2

The second schematic is the Teensy 3.5 development board which comes in a 48pin DIL package (outline, has more pins underneath), ideal to place onto a project board. It contains the Freescale K64F processor, an SD card and USB logic
to upload programs into its memory. Very little supporting hardware is needed to enable the Teensy3.5 to control the Z80 in this project.

### PCB

As per previous schematics and PCB boards, this project has been designed with KiCad Schematic Capture and PCB Layout. Below are the finished boards awaiting components and assembly.

PCB TopSide

PCB UnderSide

### Software

The existing ZPU software, ZPUTA and zOS have been ported to the K64F platform in anticipation of forwarding this design with rapid application development. Please see the [zSoft](/zsoft/) section for details
on current OS status.

Tools for the Teensy are stored in the \<z-tools> directory to aid in development and keeping consistent tested versions within the repository.

### Paths

For ease of reading, the following shortnames refer to the corresponding path in this chapter. Two repositories are used, the primary one for the [tranZPUter](https://github.com/pdsmart/tranZPUter) and [zSoft](https://github.com/pdsmart/zSoft) for the software developments.

*zSoft Repository (software)*

|  Short Name | |
|---|---|
| \[\<ABS PATH>\]  | The path where this repository was extracted on your system. |
| \<z-apps\> | \[\<ABS PATH>\]/zsoft/apps |
| \<z-build\> | \[\<ABS PATH>\]/zsoft/build |
| \<z-common\> | \[\<ABS PATH>\]/zsoft/common |
| \<z-libraries\>  | \[\<ABS PATH>\]/zsoft/libraries |
| \<z-teensy3\> | \[\<ABS PATH>\]/zsoft/teensy3 |
| \<z-include\> | \[\<ABS PATH>\]/zsoft/include |
| \<z-startup\> | \[\<ABS PATH>\]/zsoft/startup |
| \<z-iocp\> | \[\<ABS PATH>\]/zsoft/iocp |
| \<z-zOS\> | \[\<ABS PATH>\]/zsoft/zOS |
| \<z-zputa\> | \[\<ABS PATH>\]/zsoft/zputa |
| \<z-rtl\> | \[\<ABS PATH>\]/zsoft/rtl |
| \<z-docs\> | \[\<ABS PATH>\]/zsoft/docs |
| \<z-tools\> | \[\<ABS PATH>\]/zsoft/tools |

*tranZPUter Repository*

|  Short Name | |
|---|---|
| \<cpu\> | \[\<ABS PATH>\]/tranZPUter/cpu |
| \<build\> | \[\<ABS PATH>\]/tranZPUter/build |
| \<devices\> | \[\<ABS PATH>\]/tranZPUter/devices |
| \<docs\> | \[\<ABS PATH>\]/tranZPUter/docs |
| \<pcb\> | \[\<ABS PATH>\]/tranZPUter/pcb |
| \<roms\> | \[\<ABS PATH>\]/tranZPUter/software/roms |
| \<schematics\> | \[\<ABS PATH>\]/tranZPUter/schematics |
| \<software\> | \[\<ABS PATH>\]/tranZPUter/software |
| \<tools\> | \[\<ABS PATH>\]/tranZPUter/software/tools |

### Tools

All development has been made under Linux, specifically Debian/Ubuntu. Besides the standard Linux buildchain, the following software is needed.

| | |
| --- | --- |
[ZPU GCC ToolChain](https://github.com/zylin/zpugcc)        | The GCC toolchain for ZPU development. Install into */opt* or similar common area.                                  |
[Arduino](https://www.arduino.cc/en/main/software)          |  The Arduino development environment, not really needed unless adding features to the K64F version of zOS from the extensive Arduino library. Not really needed, more for reference. |
[Teensyduino](https://www.pjrc.com/teensy/td_download.html) | The Teensy3 Arduino extensions to work with the Teensy3.5 board at the Arduino level. Not really needed, more for reference. |

For the Teensy3.5/K64F the ARM compatible toolchain is stored in the repo within the build tree.

#### Memory Decoder Tool

The tranZPUterSW uses a 512KB Flash RAM as the active decoder. This was chosen intentionally to allow multiple different memory maps so as the development progressed the tranZPUter SW
could run software from the MZ80K/C/B/700/800 machines as they all are very similar just with different memory maps (graphics can differ but the [MZ80A Colour Board](/sharpmz-upgrades-80col/)
does a pretty good job at providing compatible video and it will be upgraded shortly with MZ80B/800 capable pixel graphics.

In order to generate the decoder bit map I have written a tool in C which creates the map based on internal coding. The internal coding uses Z80 sigals so it is relatively straight
forward to say 'Memory map 5, Z80 WR and Addr:0xE800:EFFF has tranZPUter RAM mapped into it'. This tool will be extended as development progresses.

To use it and create a bit map, clone the [repository](https://github.com/pdsmart/tranZPUter.git) and follow the steps below:

```
1. Change to <software>/src/tools/ directory and issue command:
   make
   make install
2. Run the command:
   <tools>/flashmmcfg -o <roms>/tranZPUterDecoderMappingFile.bin
3. Flash the file:<roms>/tranZPUterDecoderMappingFile.bin  to
   a suitable 512KB Flash RAM.
```

```
The tool currently has the following options:o

FLASHMMCFG v1.0

Options:-
  -h | --help              This help test.
  -i | --io-addr <addr>    Base address for the IO Control Registers.
  -o | --output <file>     Output the final binary image to the given file. This file is programmed into the Flash RAM.
  -v | --verbose           Output more messages.

Examples:
  flashmmcfg --output Decode1.bin --io-addr 0x20       Create the mapping binary using 0x20 as the base address for the IO Control Registers.
```

Adding decoding options is a matter of editting the file \<software\>/src/tools/flashmmcfg.c and adding suitable clauses in the setMap() method. I will add more detail how to do it
in this document later.

More software details specific to this board will appear here as development progresses.

### Flash Teensy3.5

All the necessary files and executables to program the Teensy can be found in the \<z-tools> directory within the [zSoft](/zsoft/) repository, 

To program the Teensy after an OS build, follow the steps below:

```
1. Connect the teensy 3.5 board to your PC with the USB cable.
2. Launch the Teensy programming application: 
   \<z-soft>/teensy 
3. In the Teensy application, select File->Open HEX file and navigate to the \<z-zOS> or \z<zputa> directory (depending on which OS your uploading) and select the file 'main.hex'.
4. Press the RESET button on the Teensy 3.5
5. In the Teensy application, select Operation->Program - this programs the onboard Flash RAM.
6. Ensure you have a terminal emulator open configured to the virtual serial device (if unsure, issue the 'dmesg' command from within Linux to see the latest USB attachment and its name). Normally the device is /dev/ttyACM0. There is no need to set the Baud rate or Bits/Parity, this is a virtual serial port and operates at USB speed.
7. In the Teensy application, select Operation->Reboot - this will now reboot the K64F and it will startup running zOS or ZPUTA.
8. Interact with the OS via the terminal emulator. 
```
For further information, see the Teensy [basic usage guid](https://www.pjrc.com/teensy/td_usage.html).

### To Do
1. Write the ZPU C/C++ code to take control of the MZ80A, save/update/restore the Video Memory (for Menu system), convert the MisTer Main/sharpmz application.? Menu/control code, and additional glue to use the SD card.<br/>
2. Look into converting the PiCoPro soft processors to work with the K64F. Both are ARM based so should be possible.

## Credits

Where I have used or based any component on a 3rd parties design I have included the original authors copyright notice. All 3rd party software, to my knowledge and research, is open source and freely useable, if there is found to be any component with licensing restrictions, it will be removed from this repository and a suitable link/config provided.

## Licenses

This design, hardware and software, is licensed under the GNU Public Licence v3.

### The Gnu Public License v3
 The source and binary files in this project marked as GPL v3 are free software: you can redistribute it and-or modify it under the terms of the GNU General Public License as published by the Free Software Foundation, either version 3 of the License, or (at your option) any later version.

 The source files are distributed in the hope that it will be useful, but WITHOUT ANY WARRANTY; without even the implied warranty of MERCHANTABILITY or FITNESS FOR A PARTICULAR PURPOSE.  See the GNU General Public License for more details.

 You should have received a copy of the GNU General Public License along with this program.  If not, see http://www.gnu.org/licenses/.

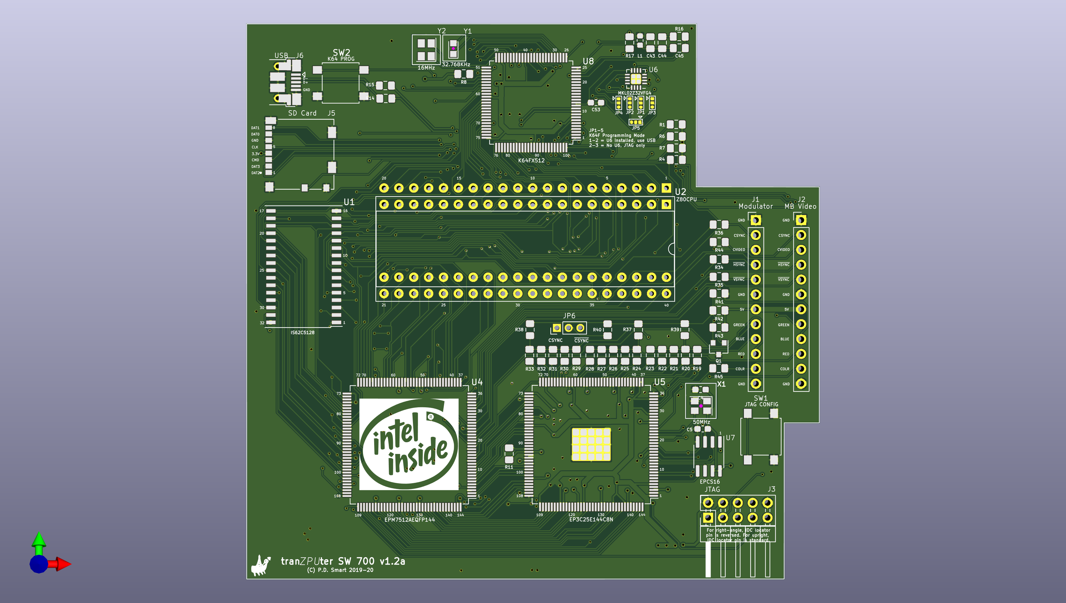
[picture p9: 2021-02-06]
schematics/tranZPUter-SW-700/v1.2/tranZPUter-SW-700_v1_2_TS.png

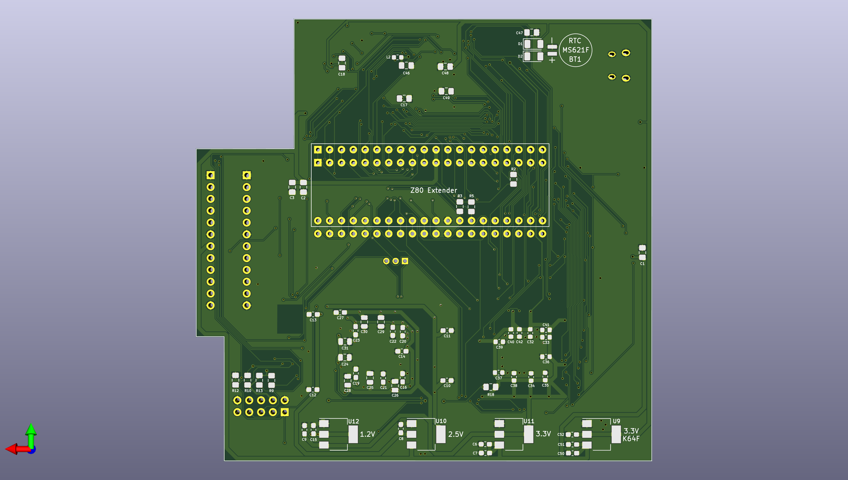
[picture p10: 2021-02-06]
schematics/tranZPUter-SW-700/v1.2/tranZPUter-SW-700_v1_2_BS.png

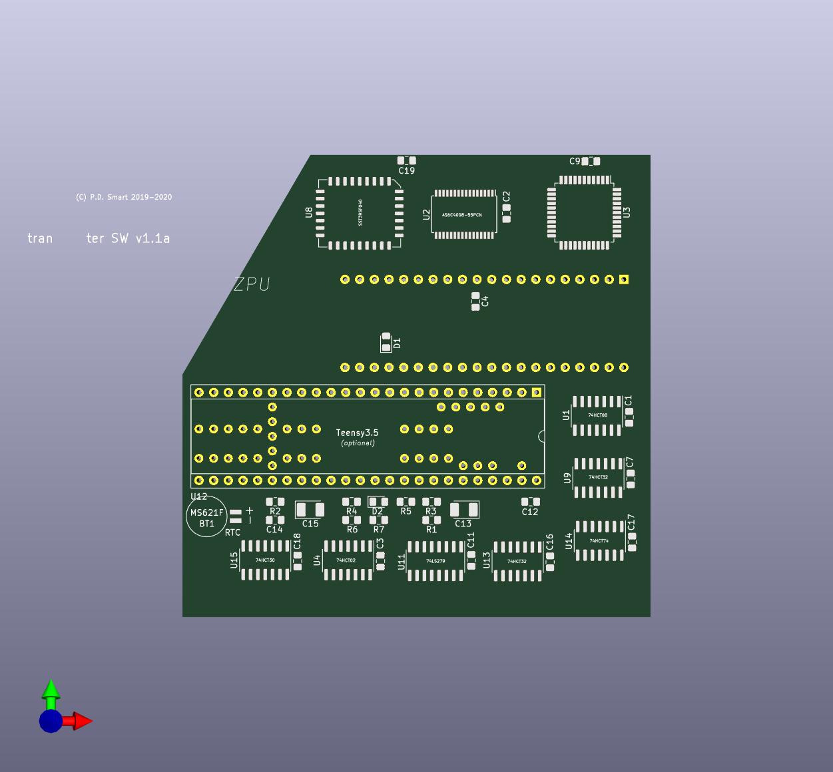
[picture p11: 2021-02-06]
schematics/tranZPUter-SW-700/v1.2/tranZPUter-SW-700_v1_2.jpg

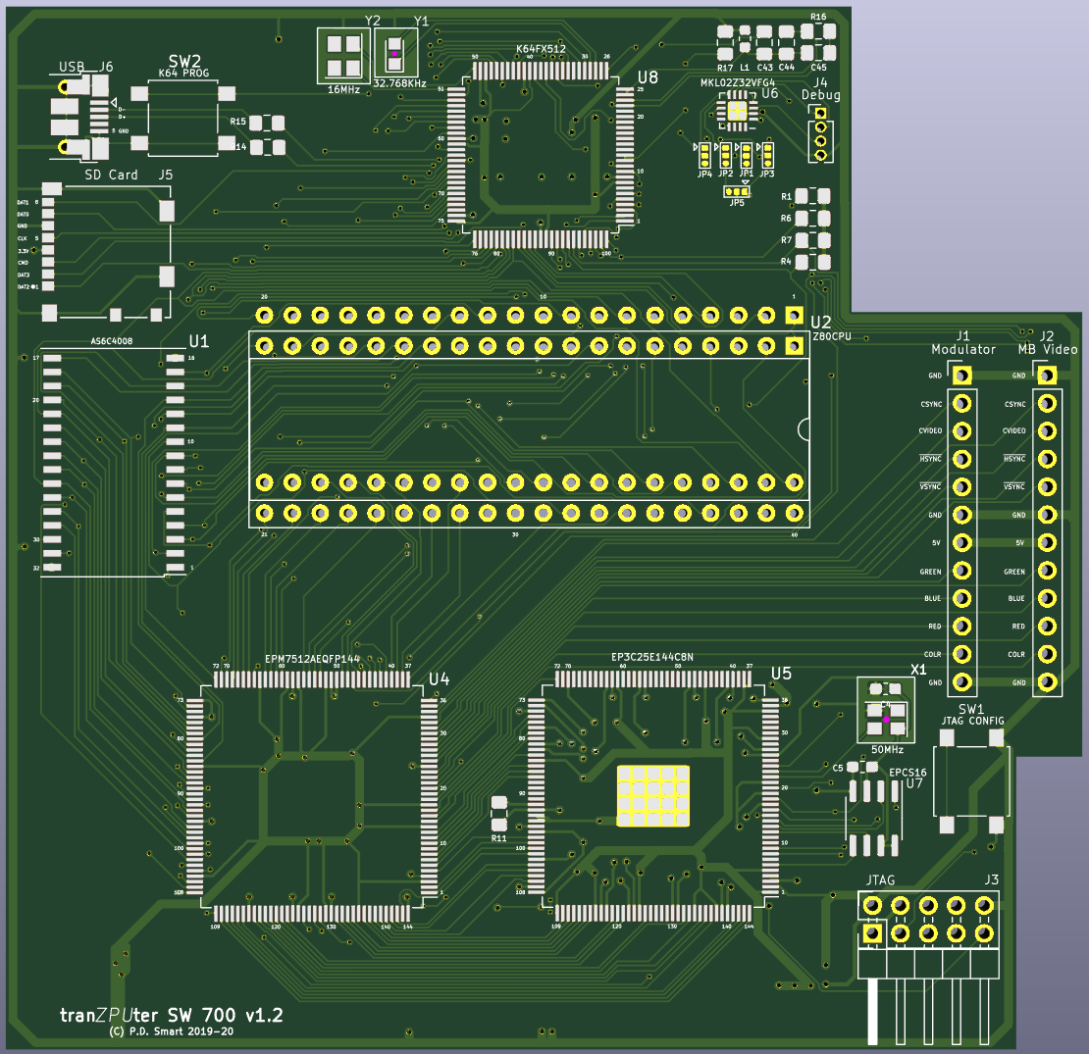
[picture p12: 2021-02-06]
schematics/tranZPUter-SW-700/v1.2/tranZPUter-SW-700_v1_2.png

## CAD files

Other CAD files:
build/tranZPUter.stp

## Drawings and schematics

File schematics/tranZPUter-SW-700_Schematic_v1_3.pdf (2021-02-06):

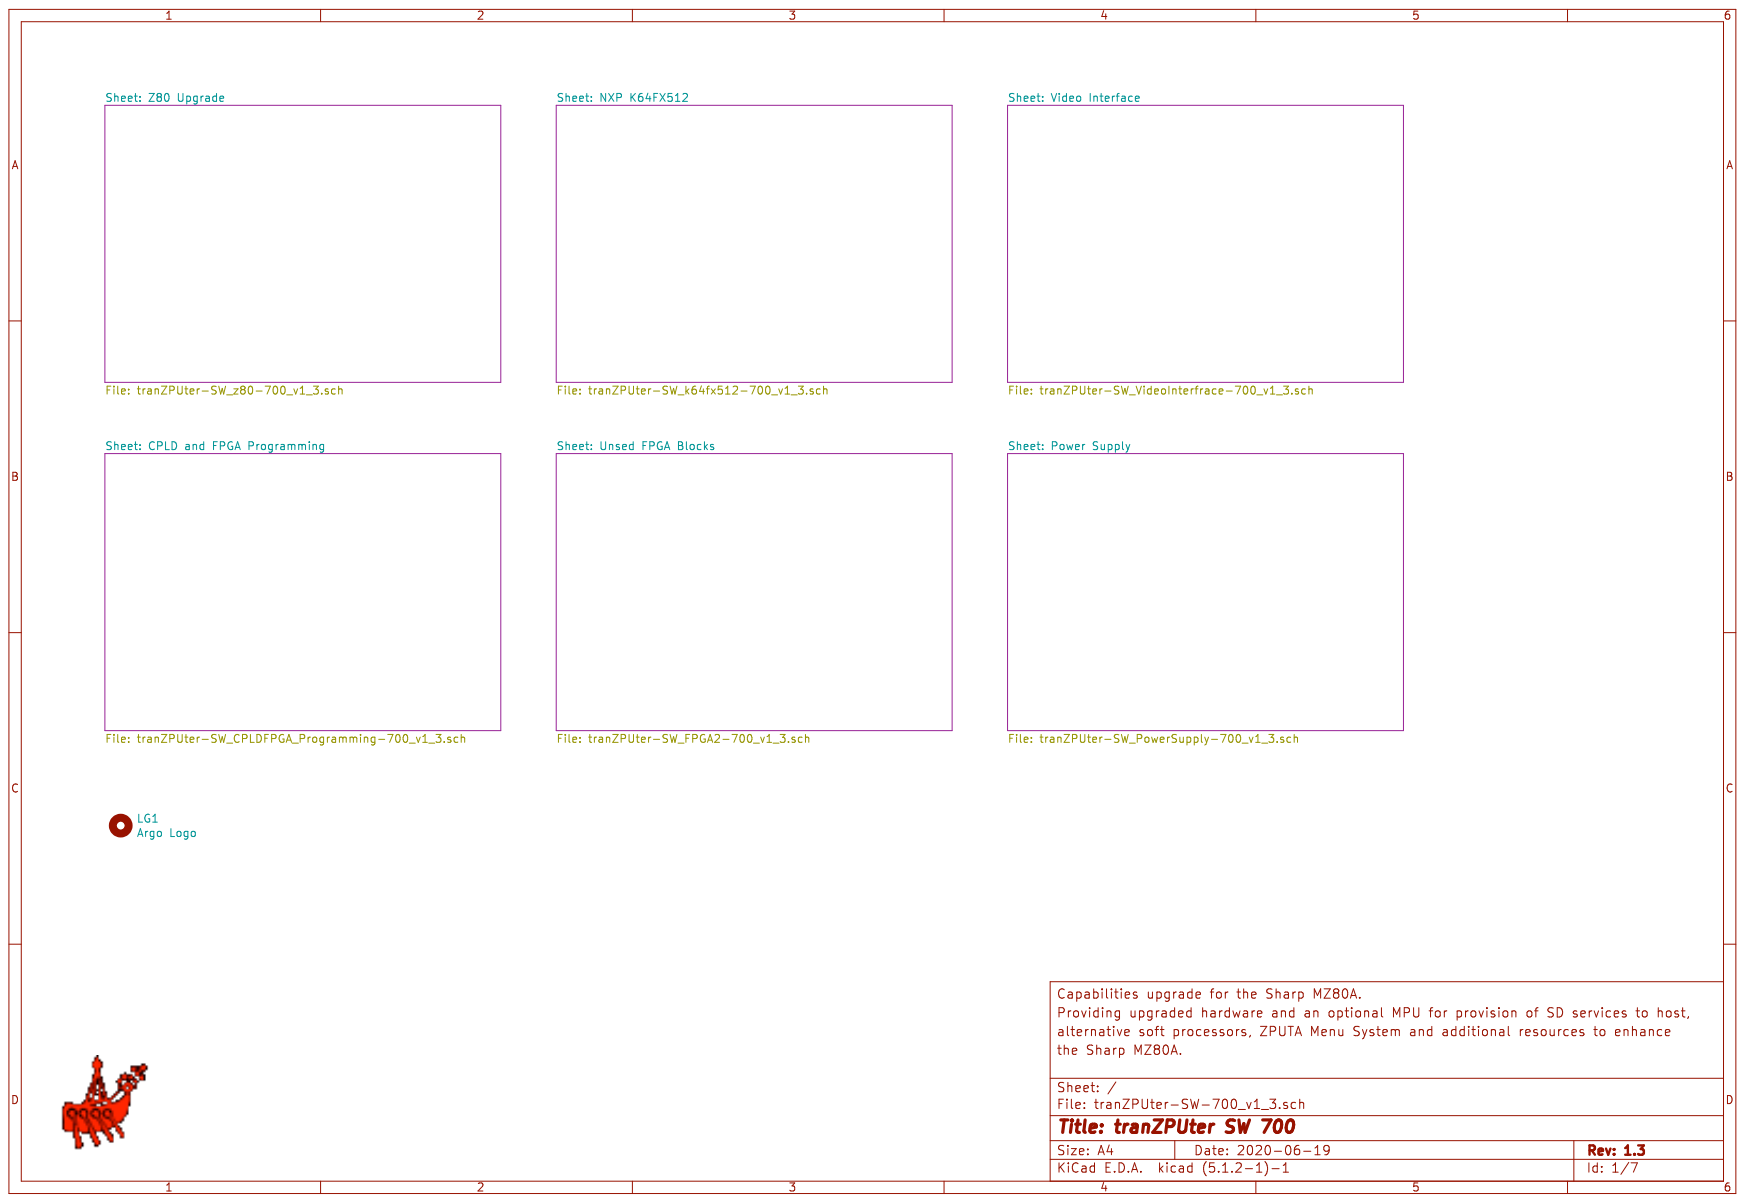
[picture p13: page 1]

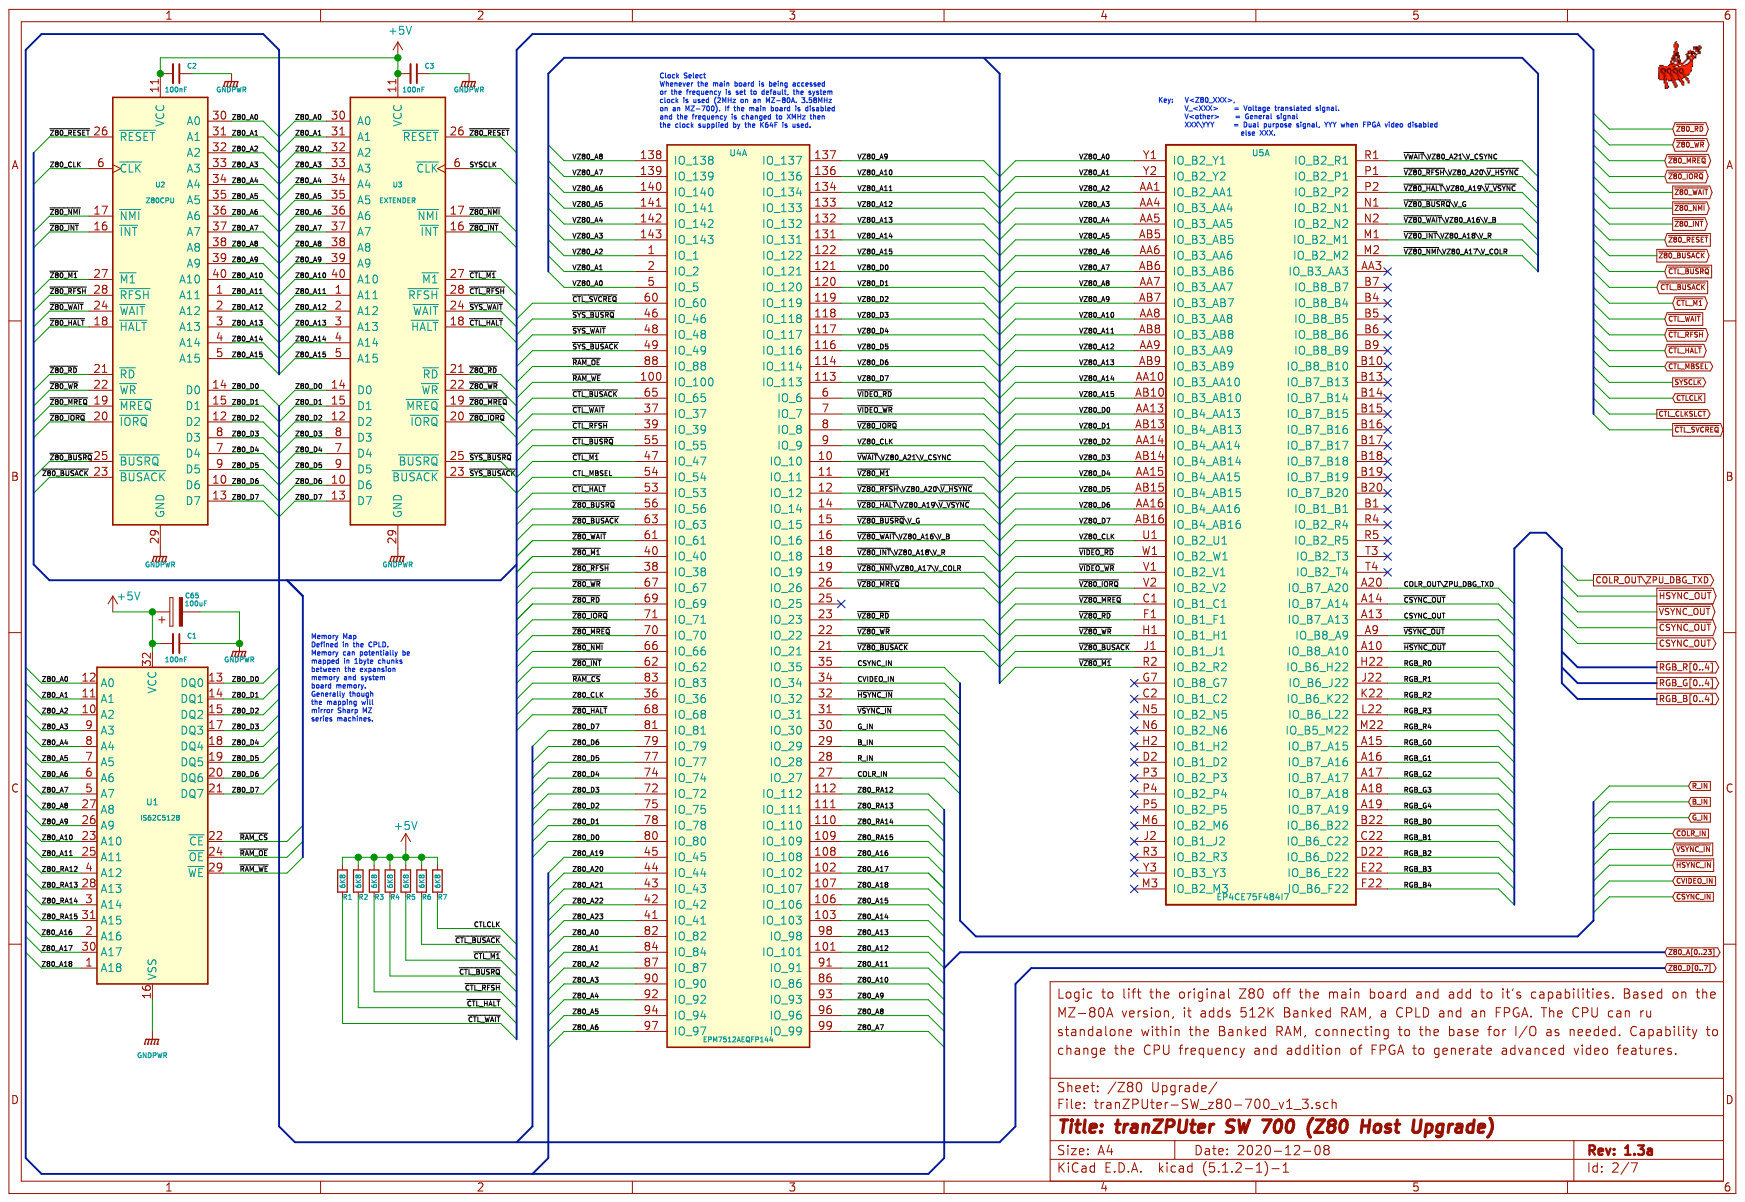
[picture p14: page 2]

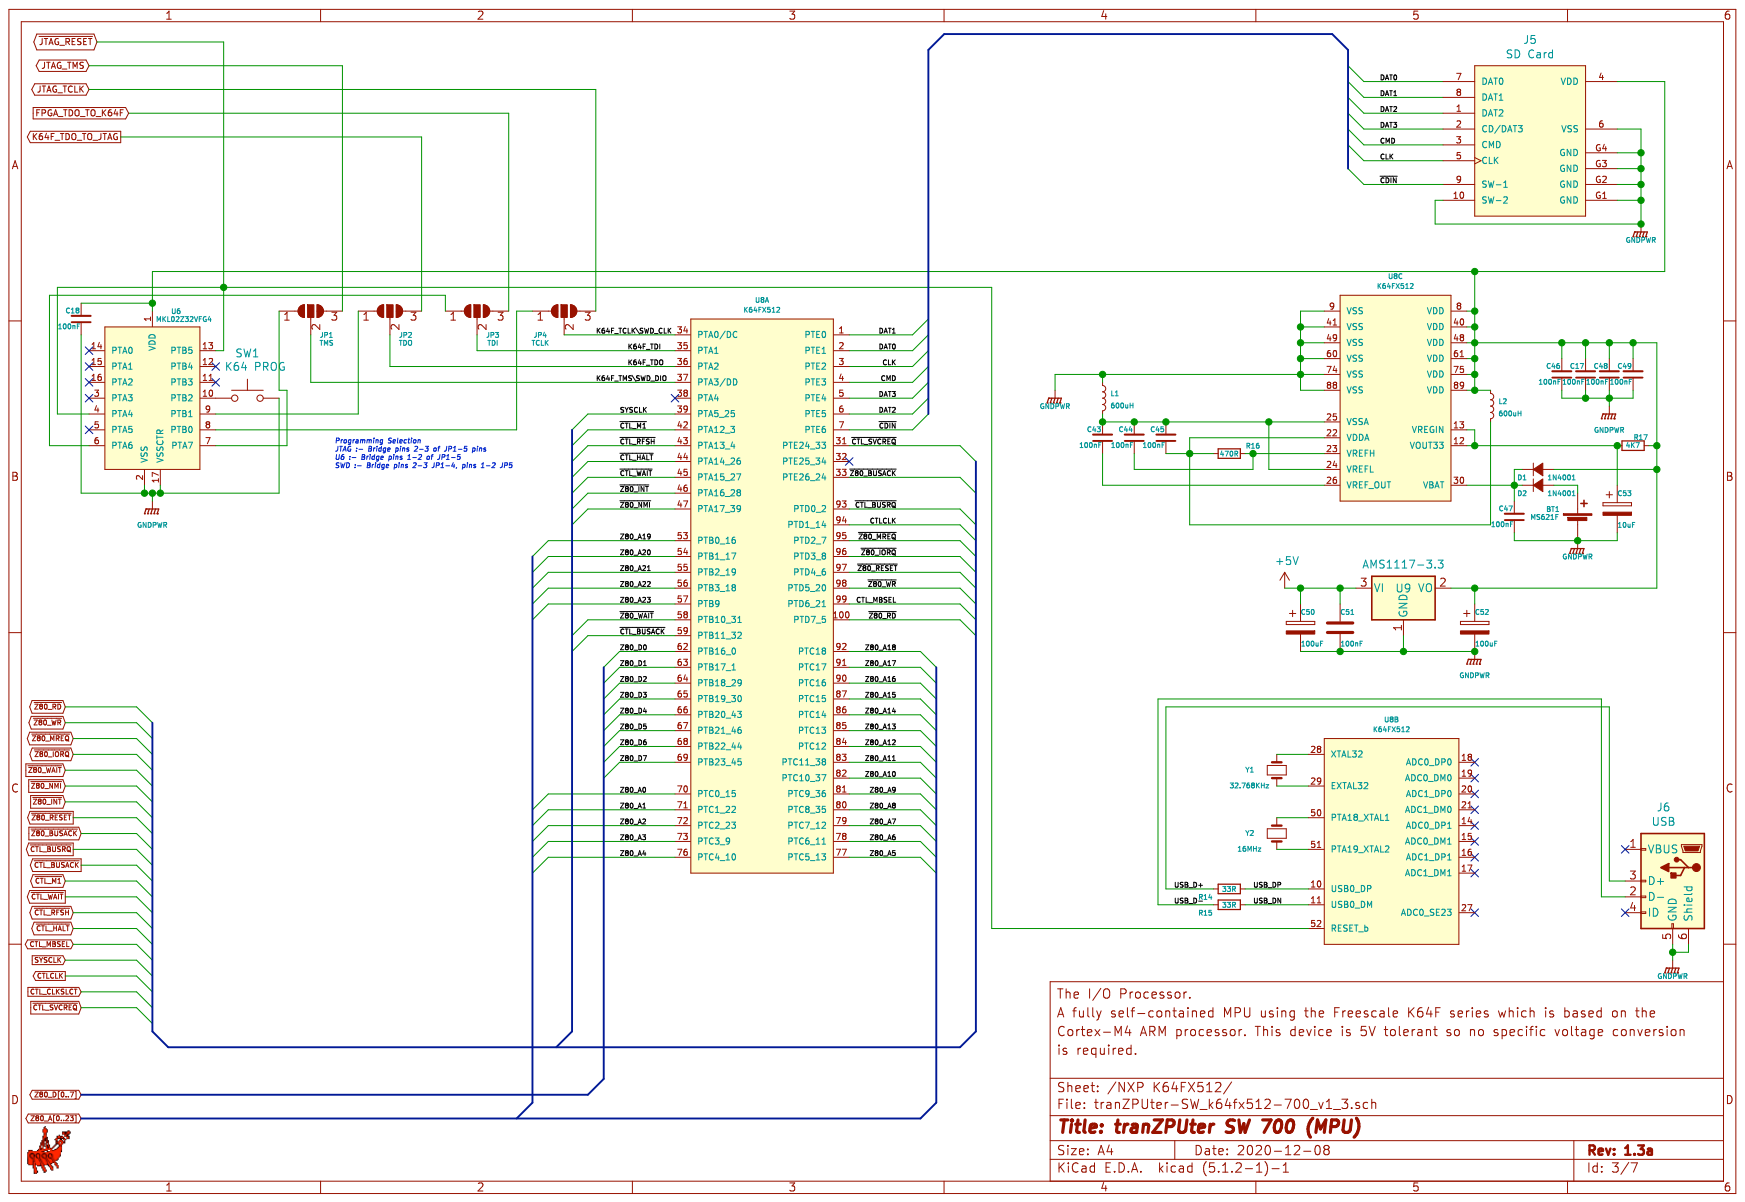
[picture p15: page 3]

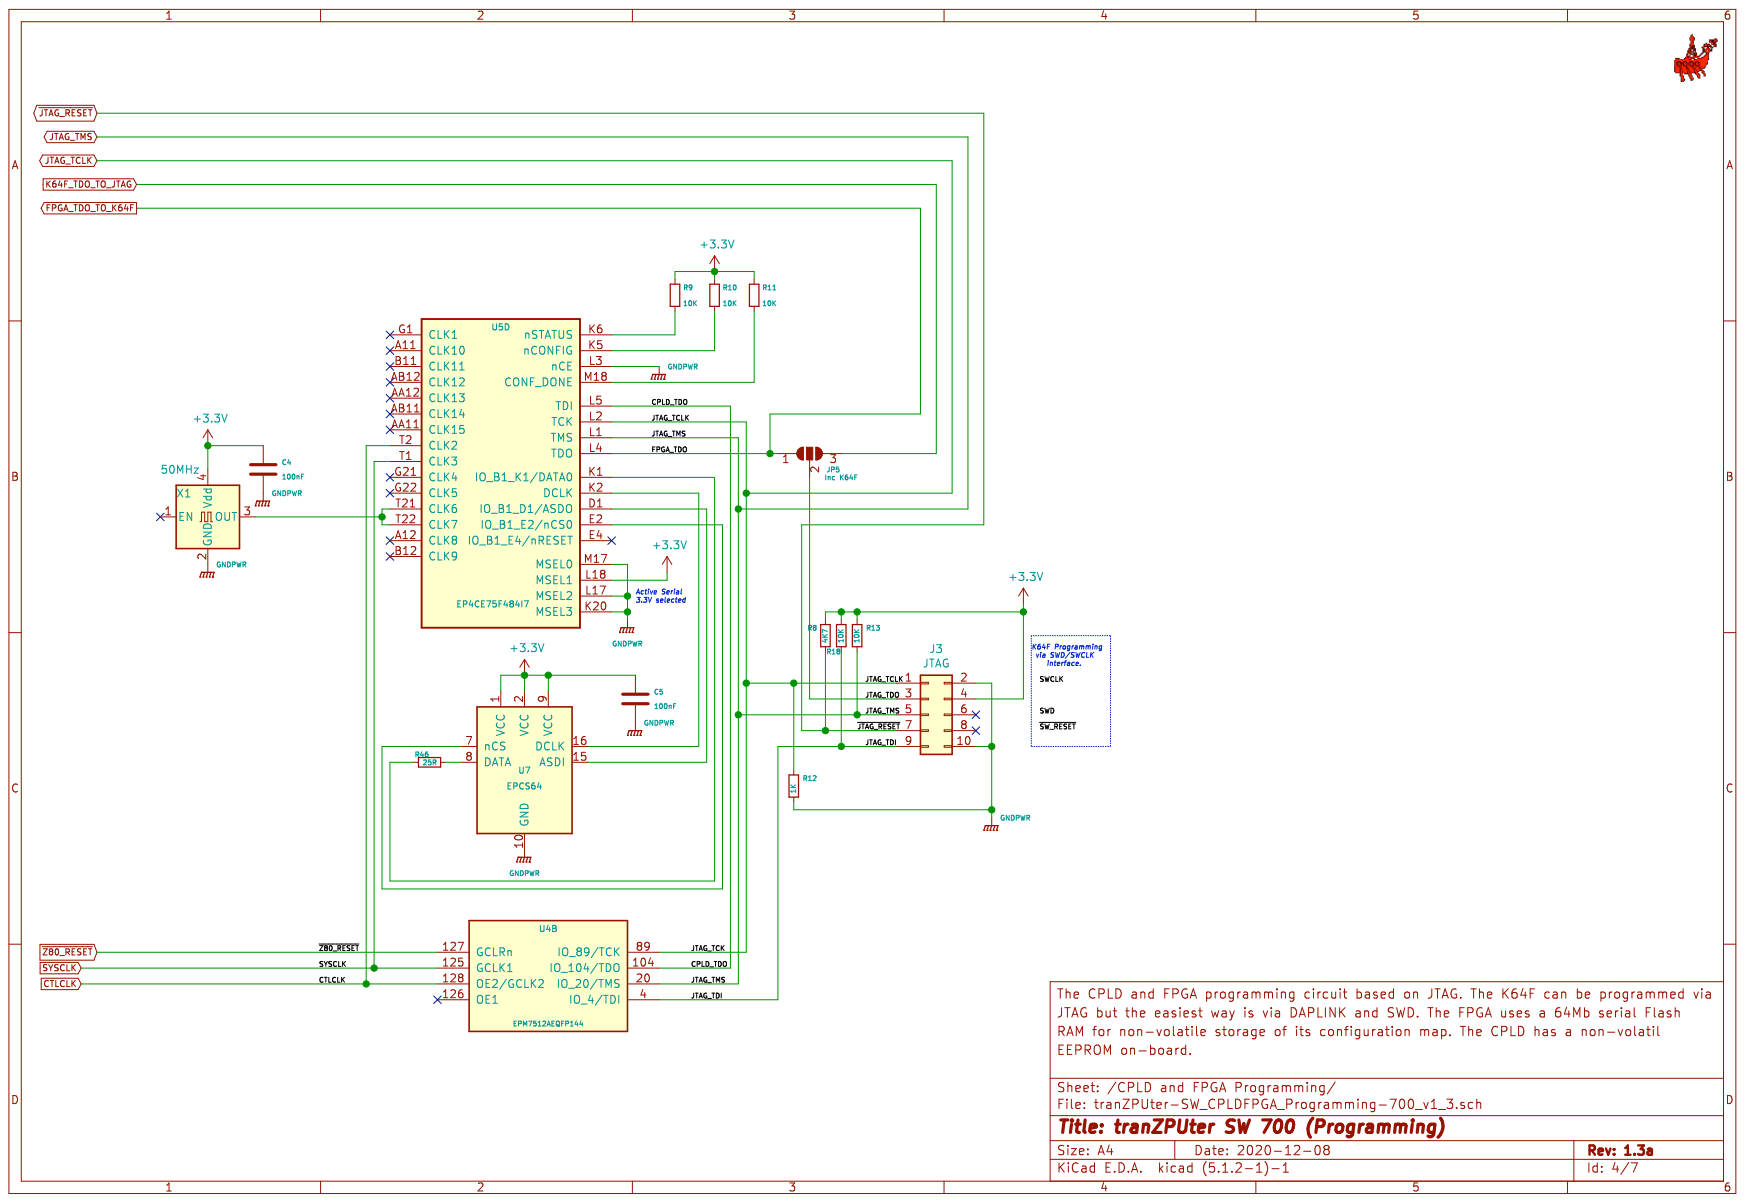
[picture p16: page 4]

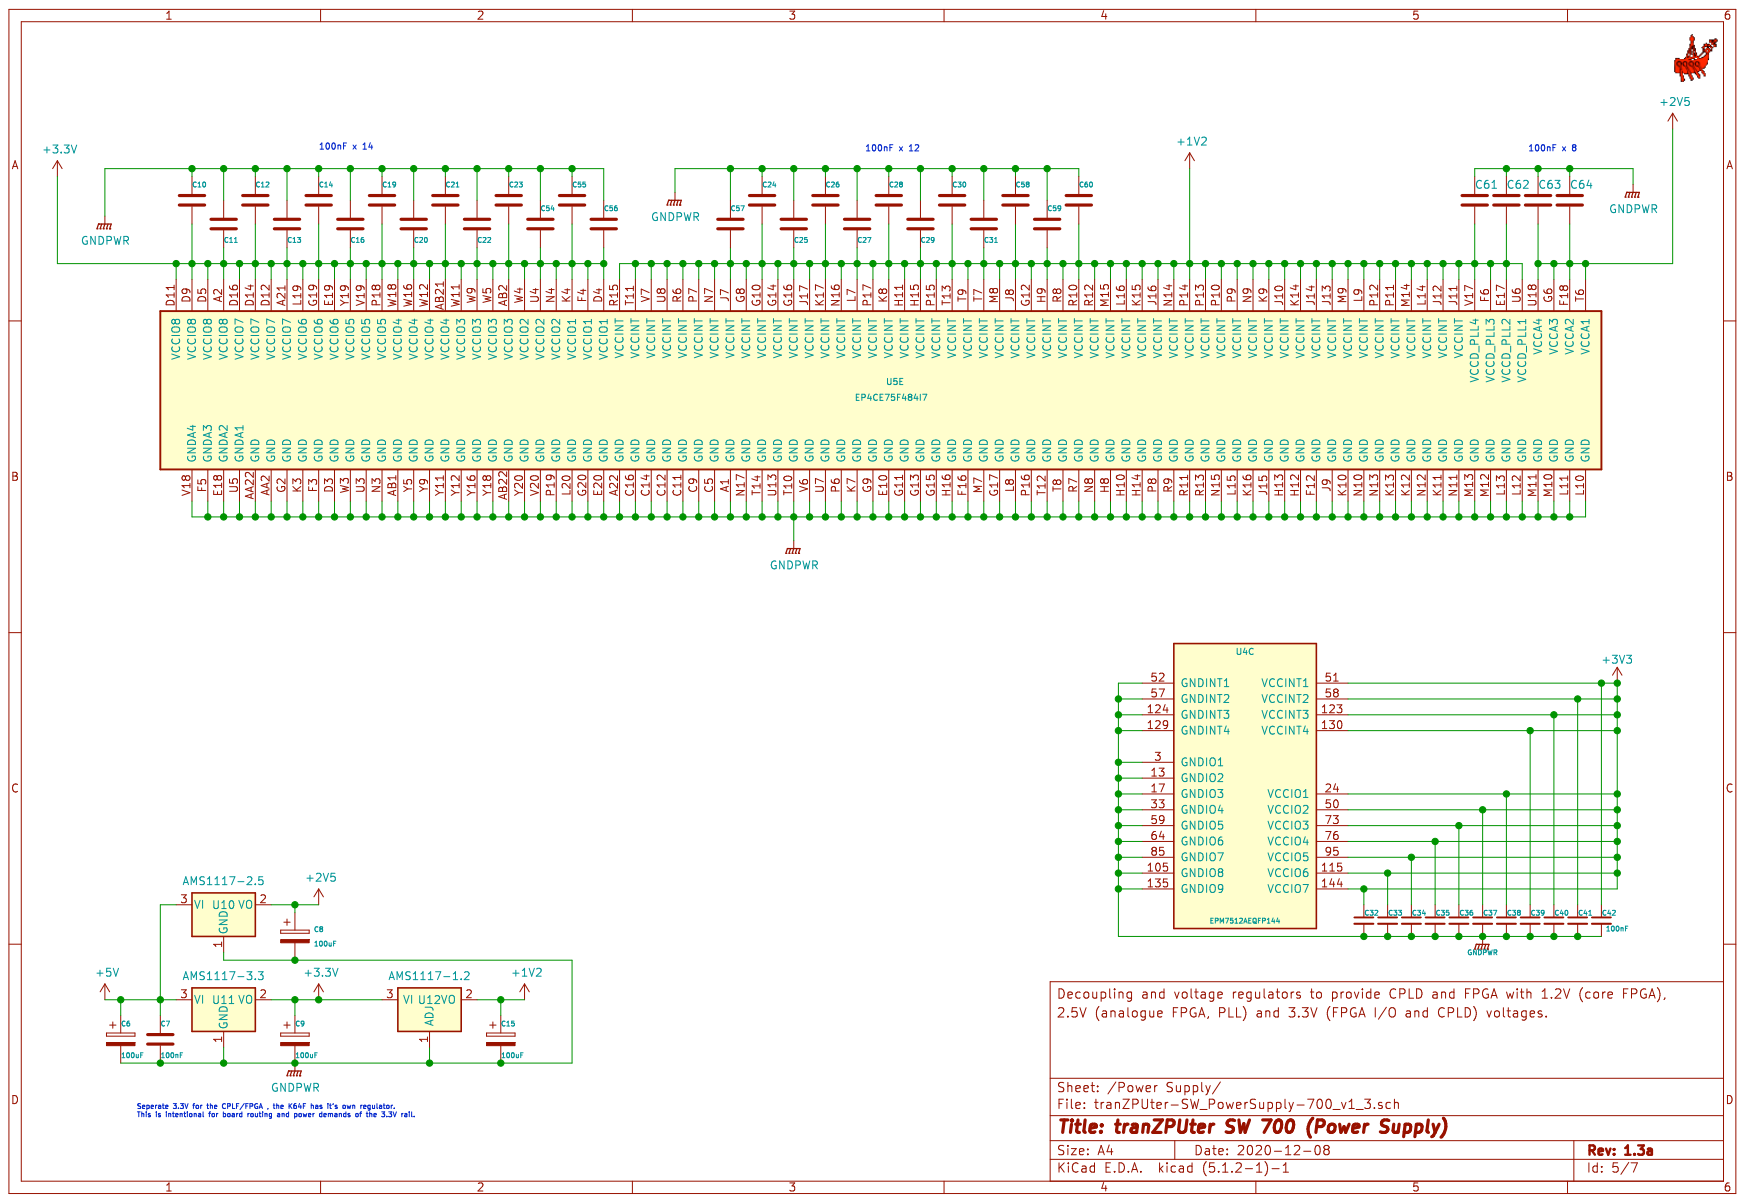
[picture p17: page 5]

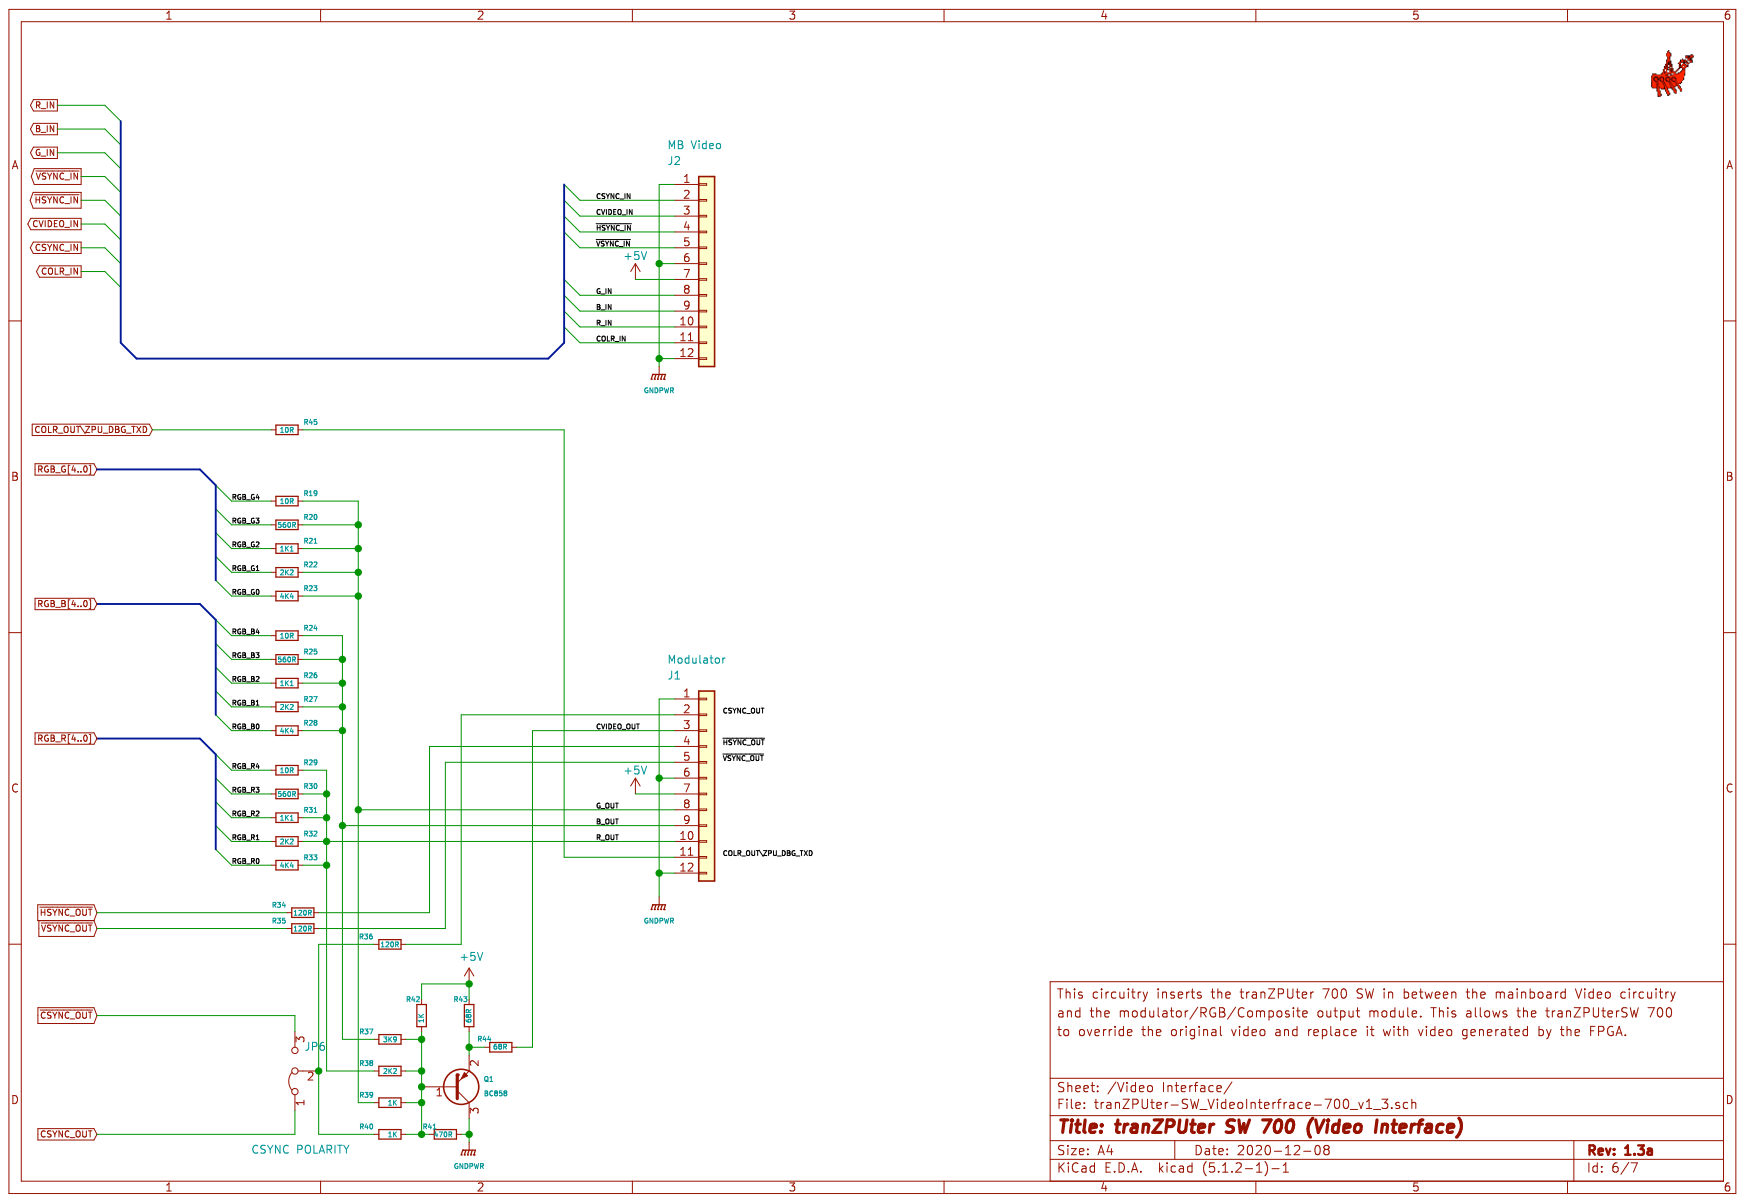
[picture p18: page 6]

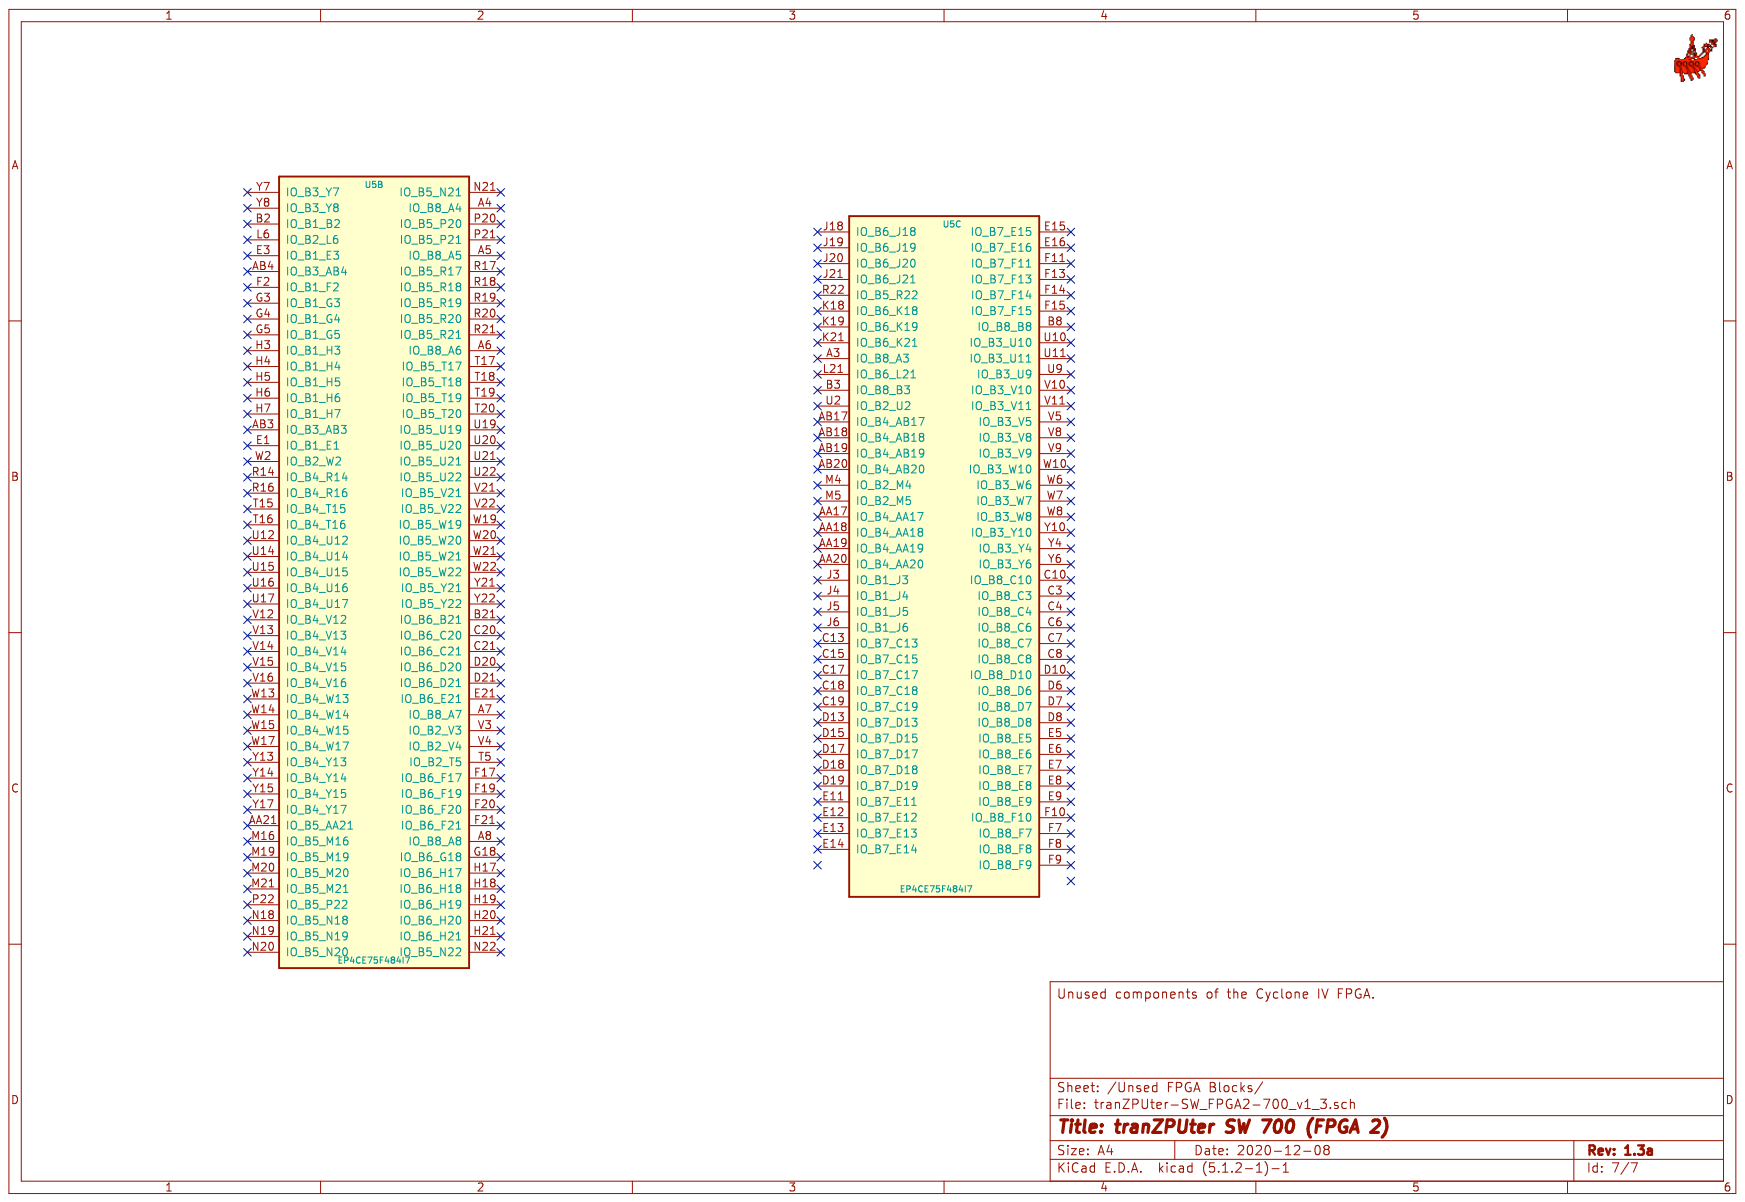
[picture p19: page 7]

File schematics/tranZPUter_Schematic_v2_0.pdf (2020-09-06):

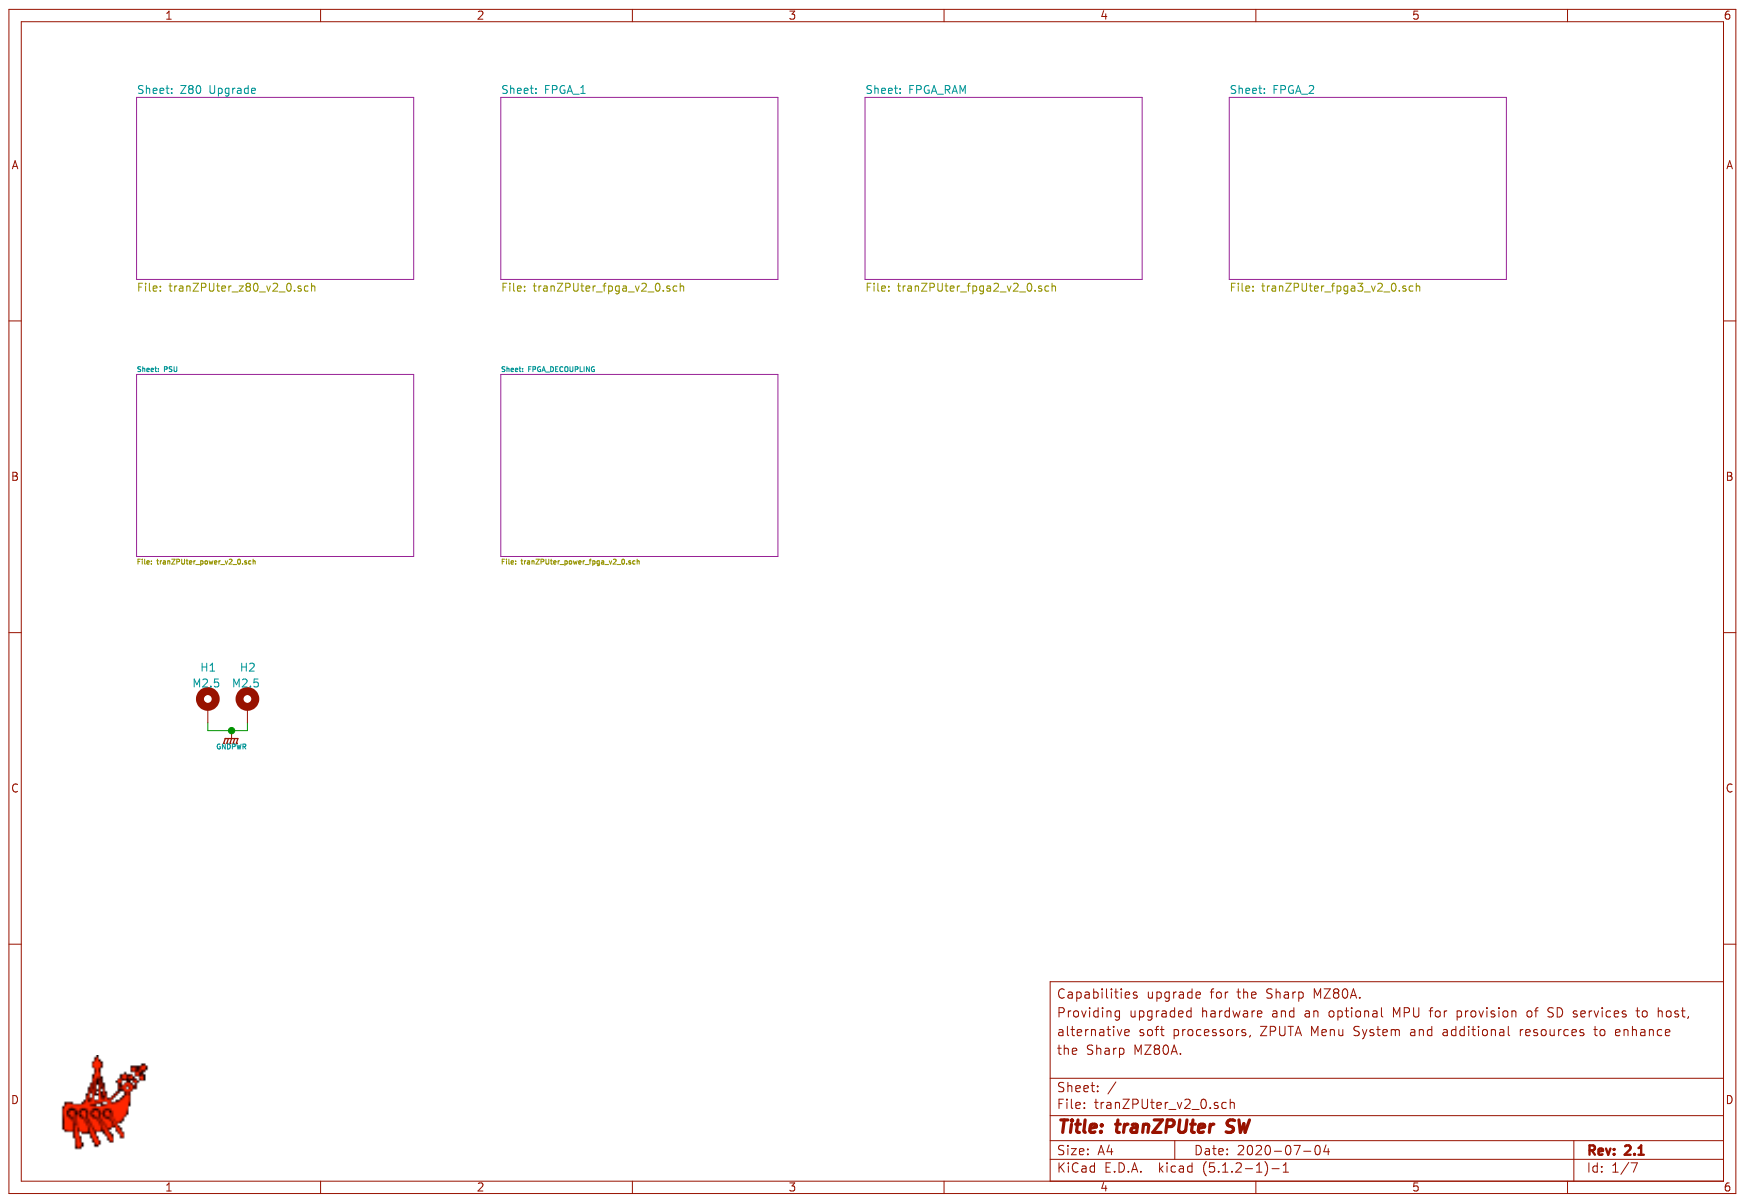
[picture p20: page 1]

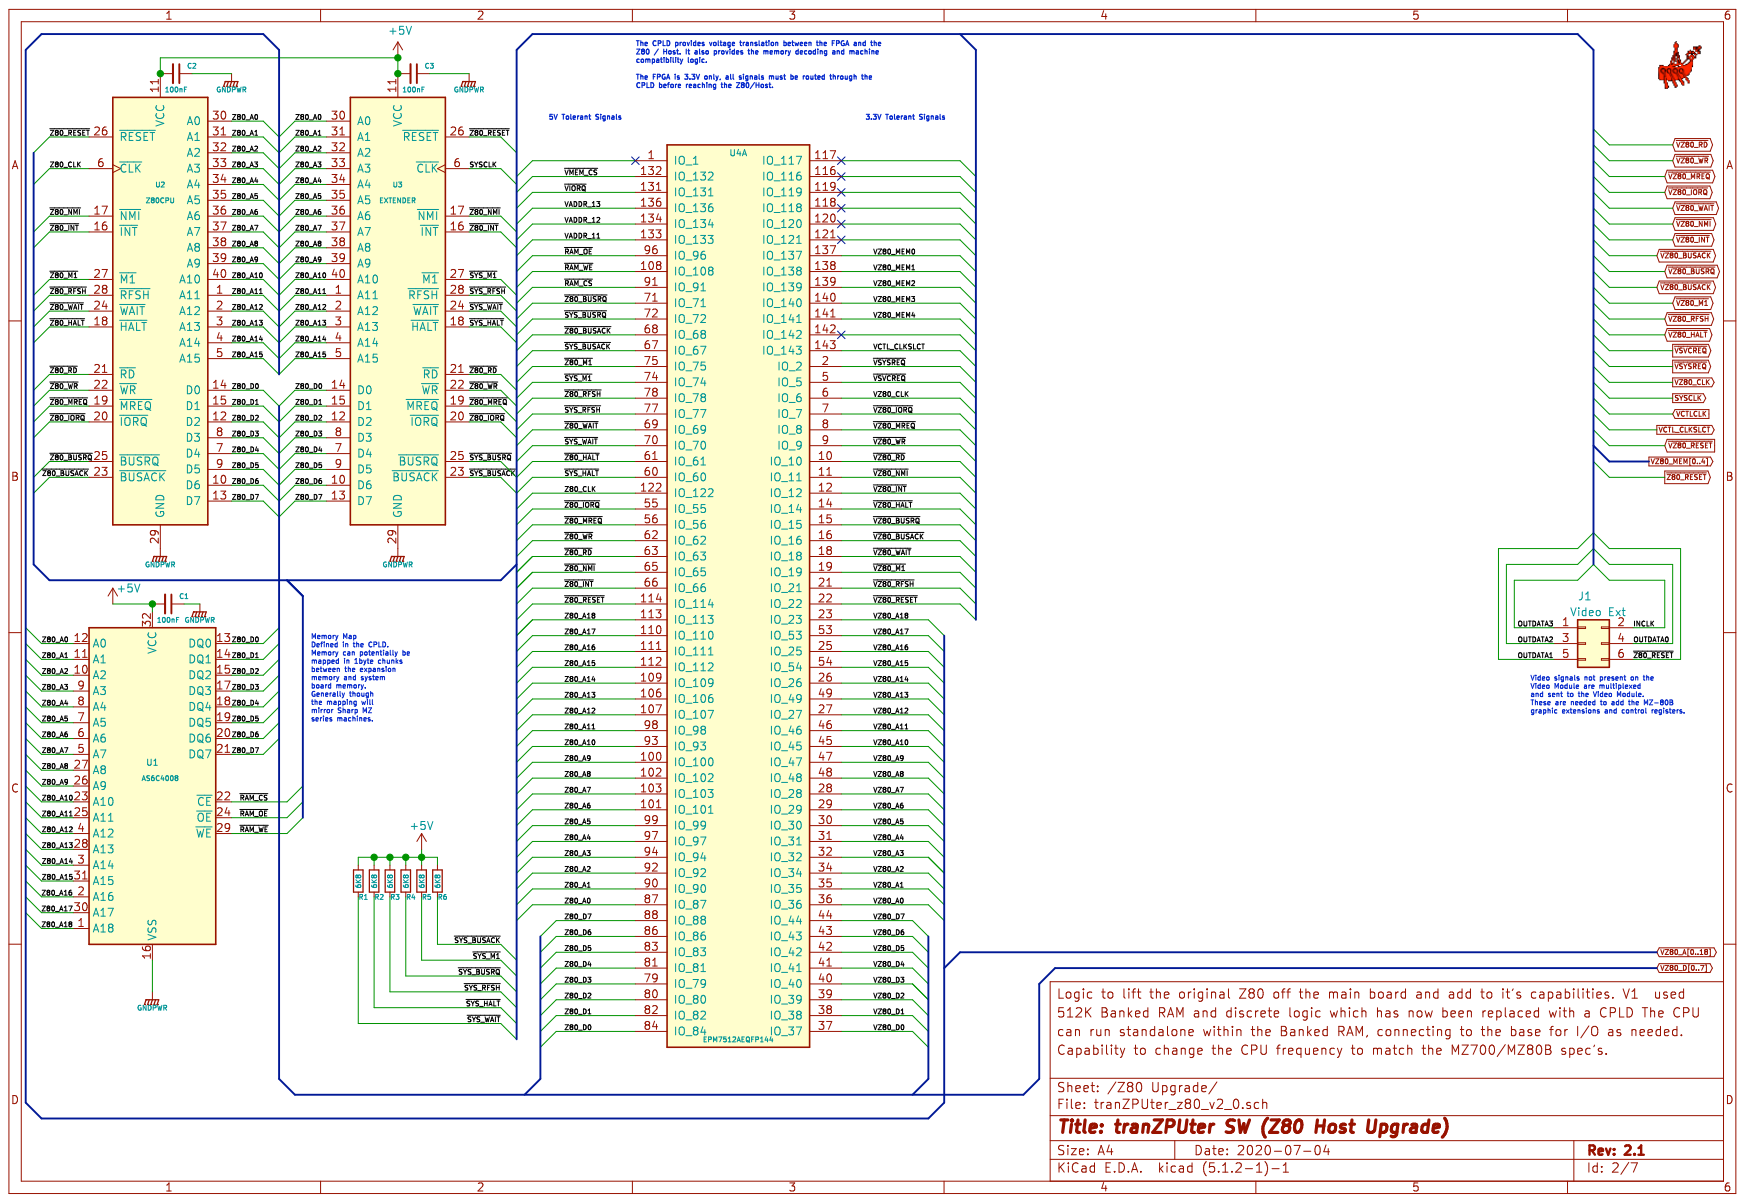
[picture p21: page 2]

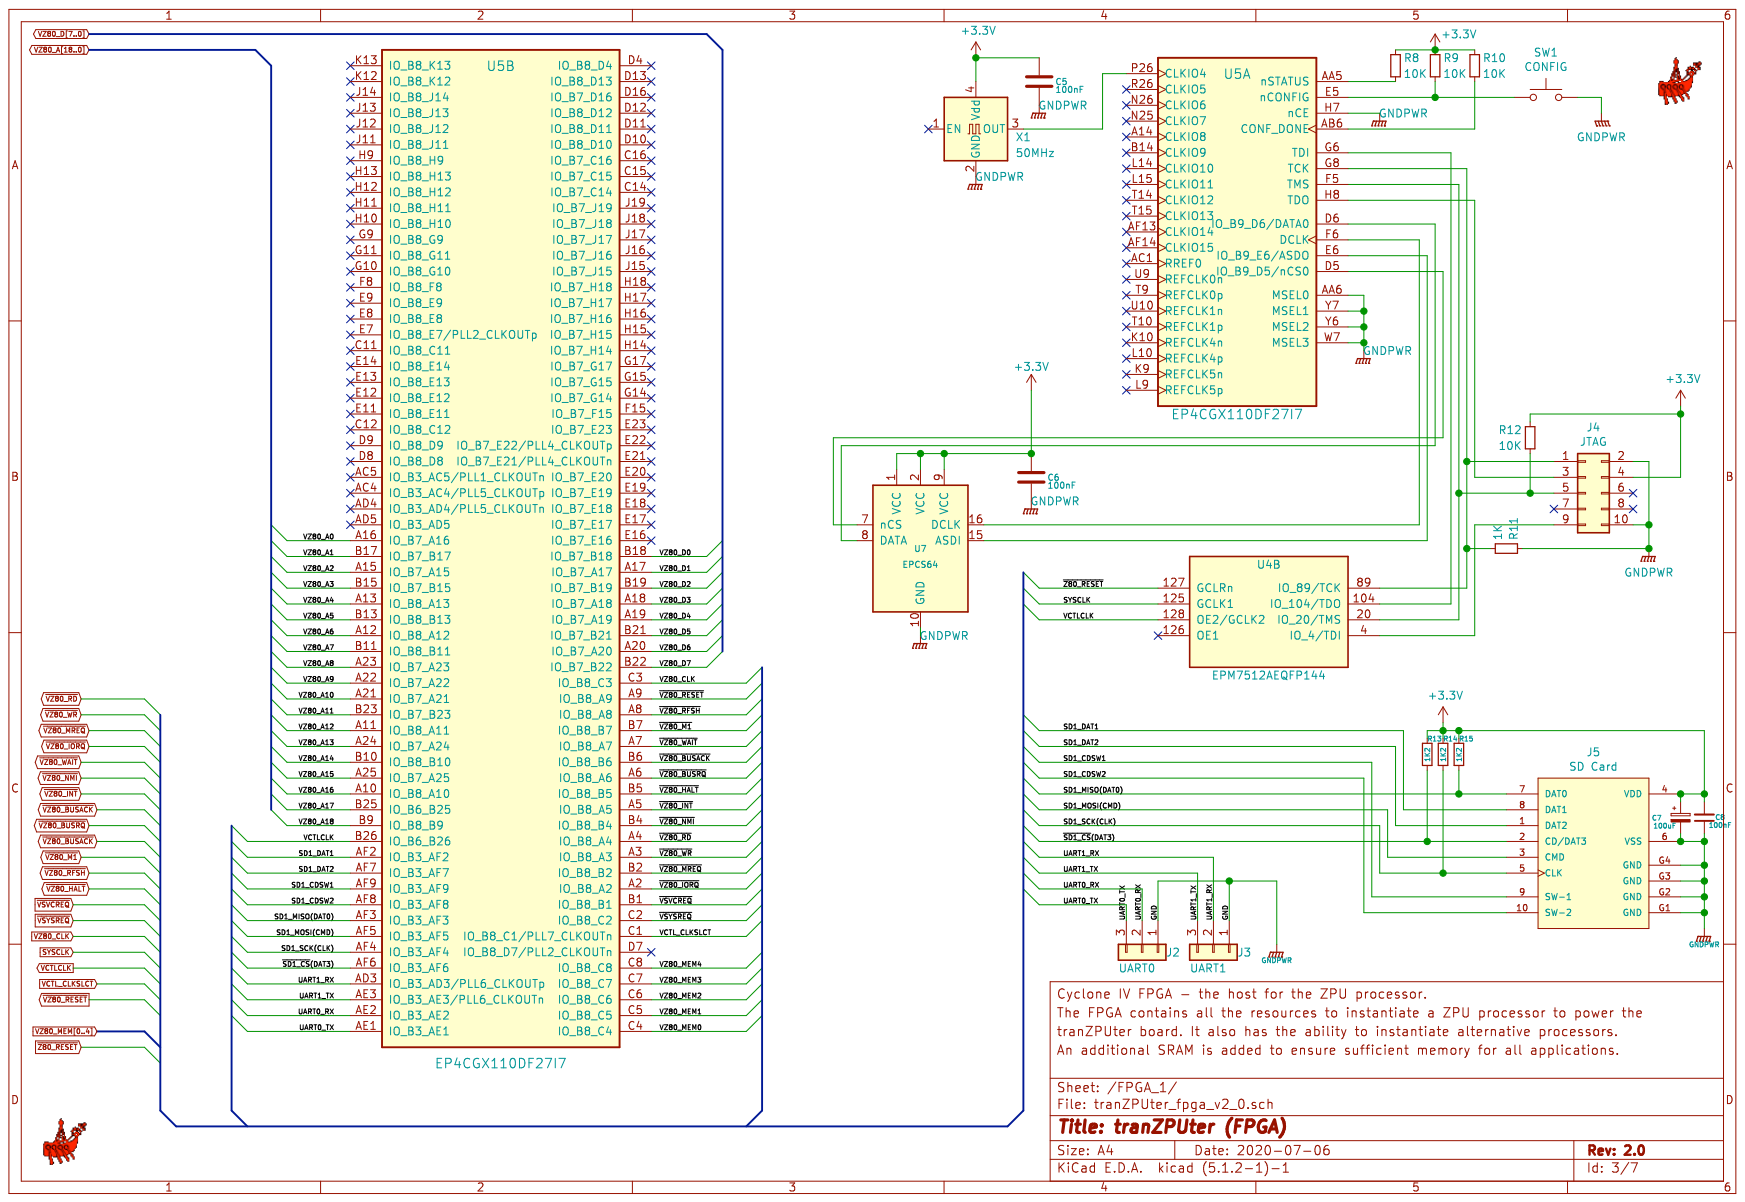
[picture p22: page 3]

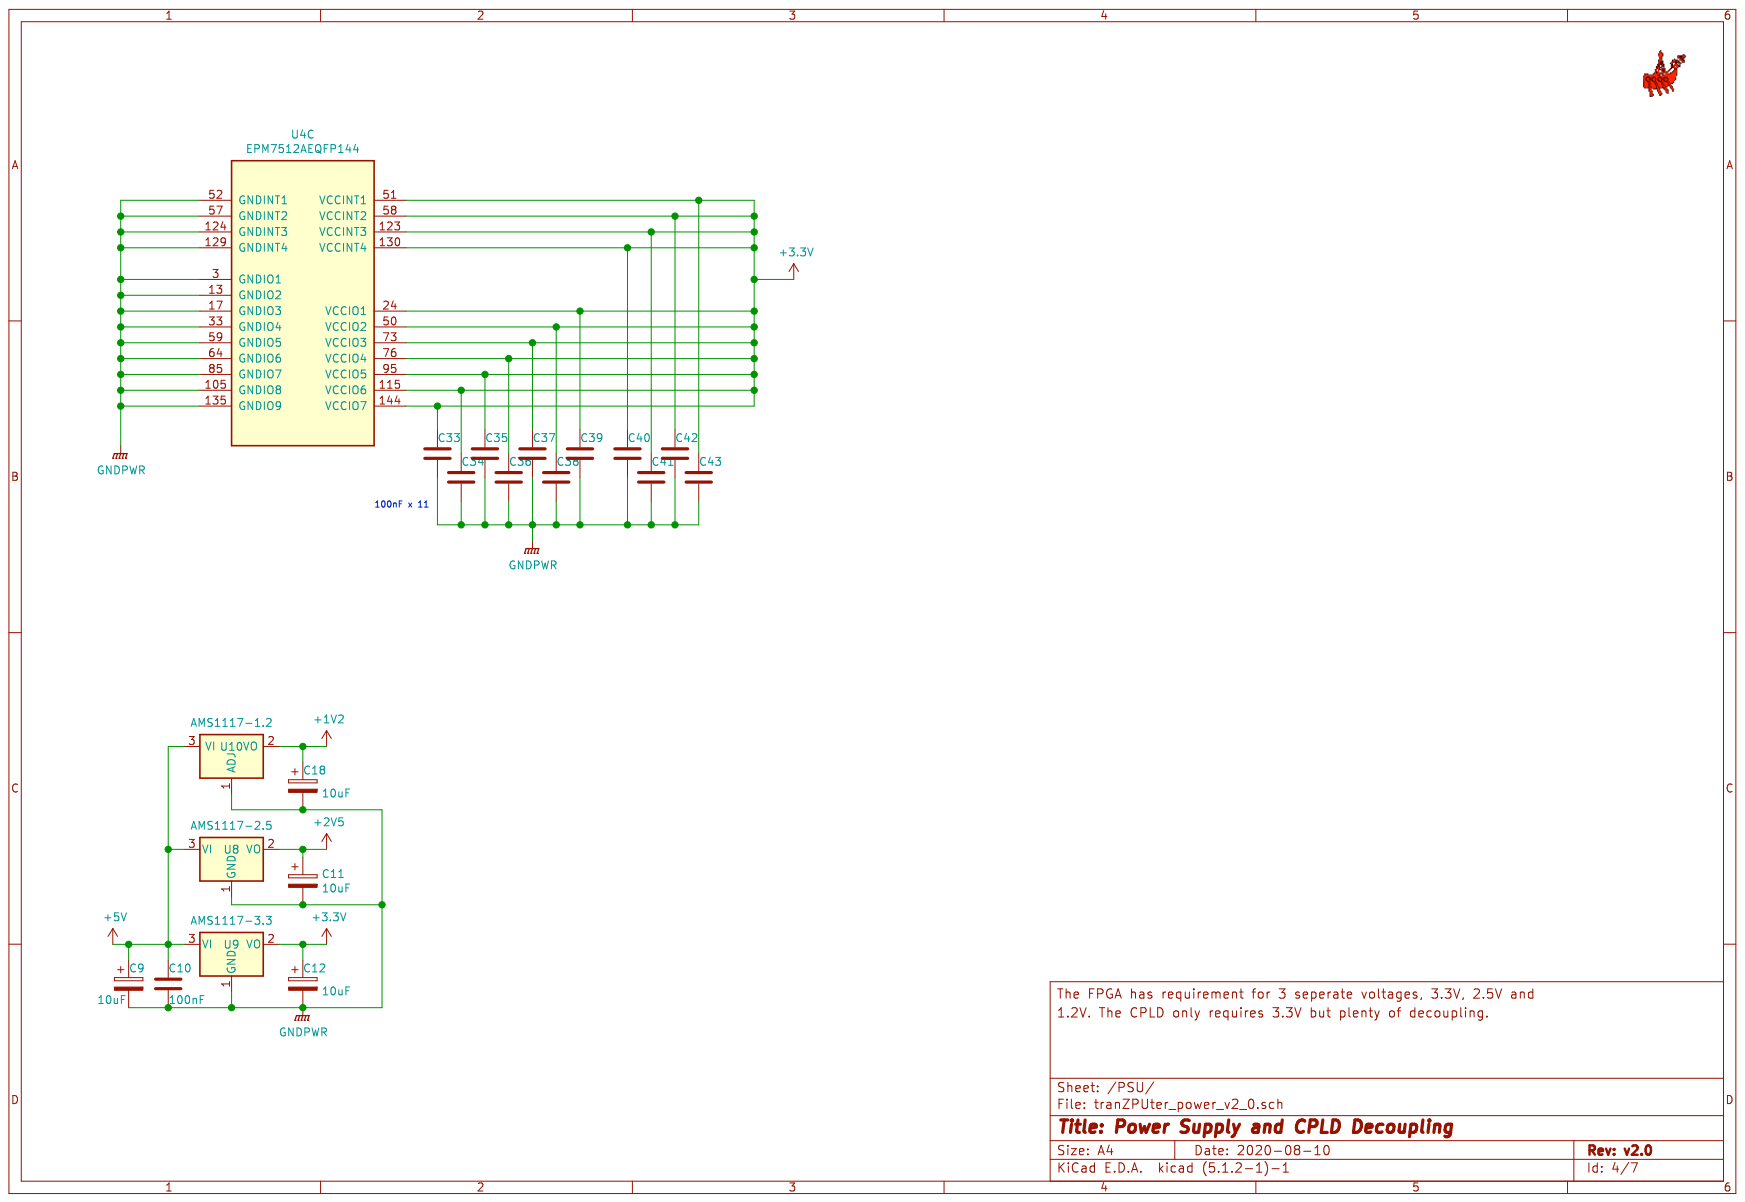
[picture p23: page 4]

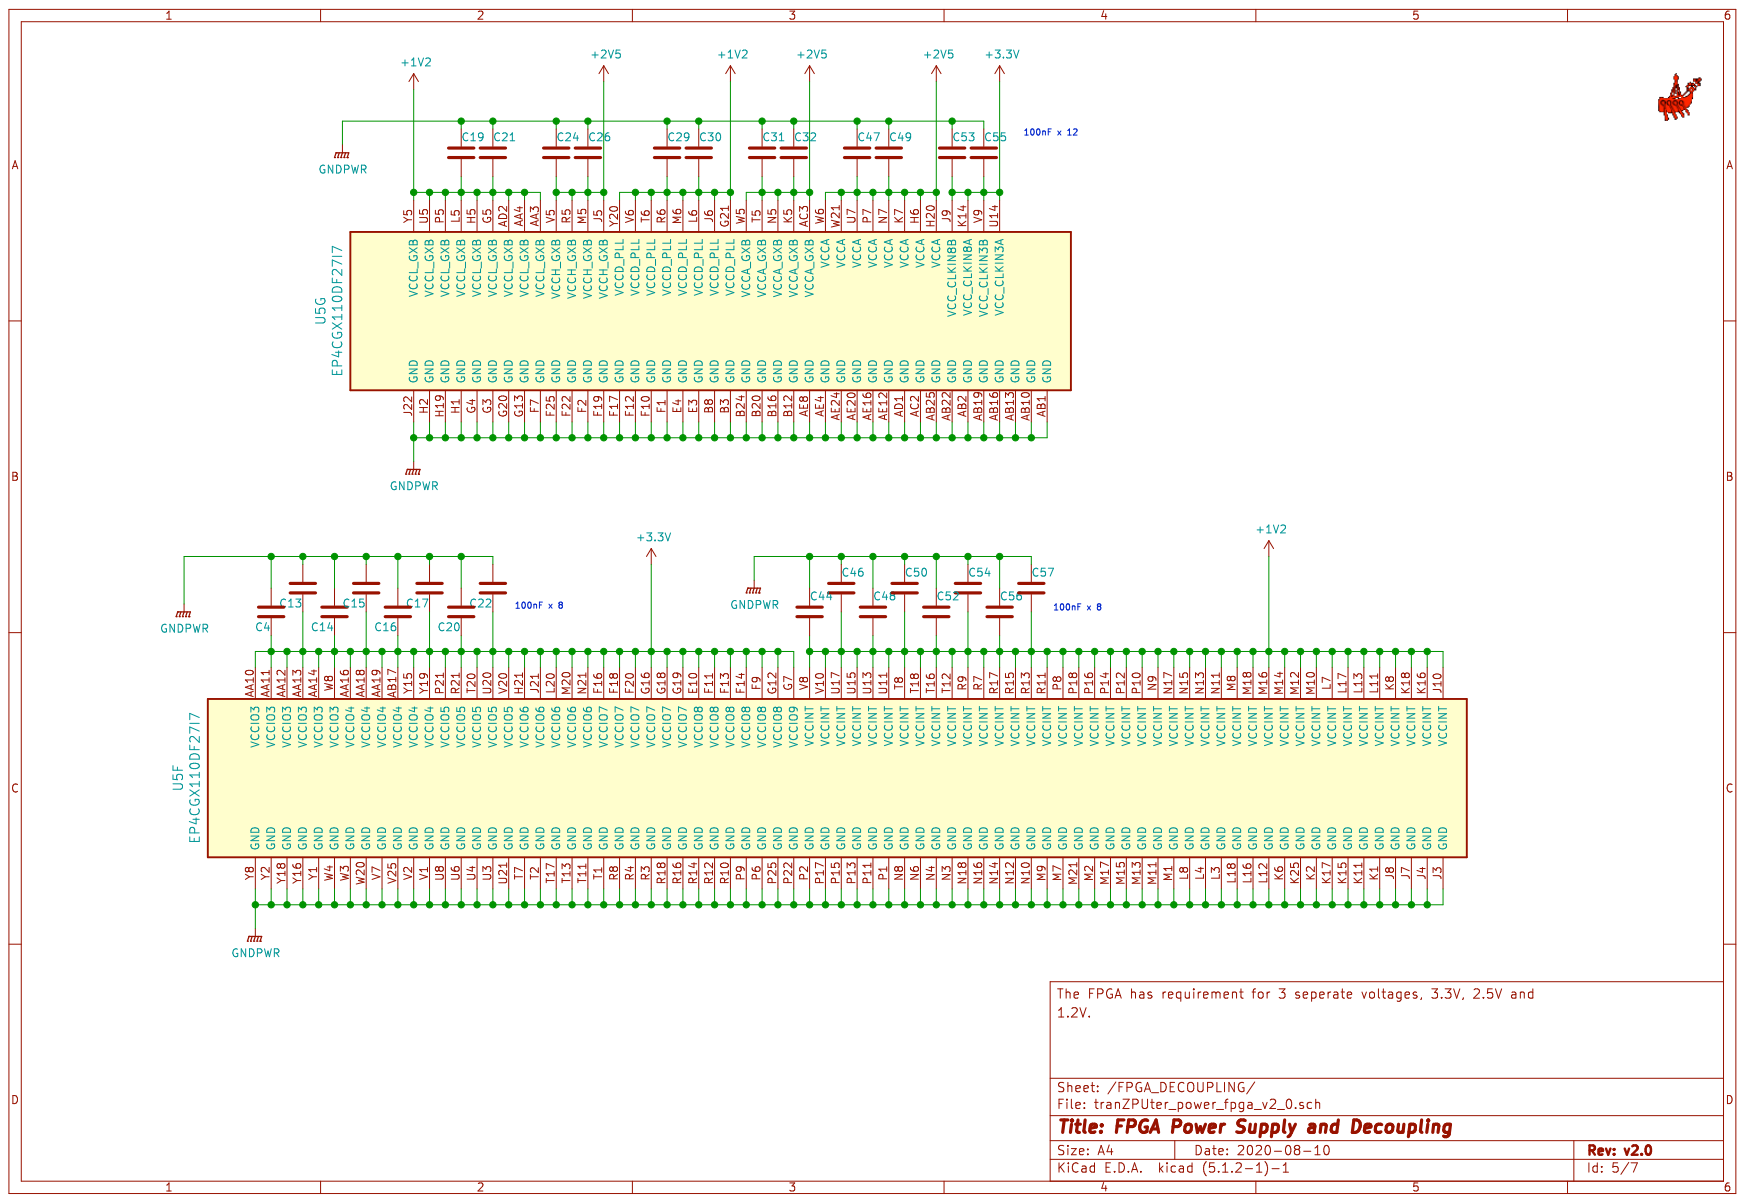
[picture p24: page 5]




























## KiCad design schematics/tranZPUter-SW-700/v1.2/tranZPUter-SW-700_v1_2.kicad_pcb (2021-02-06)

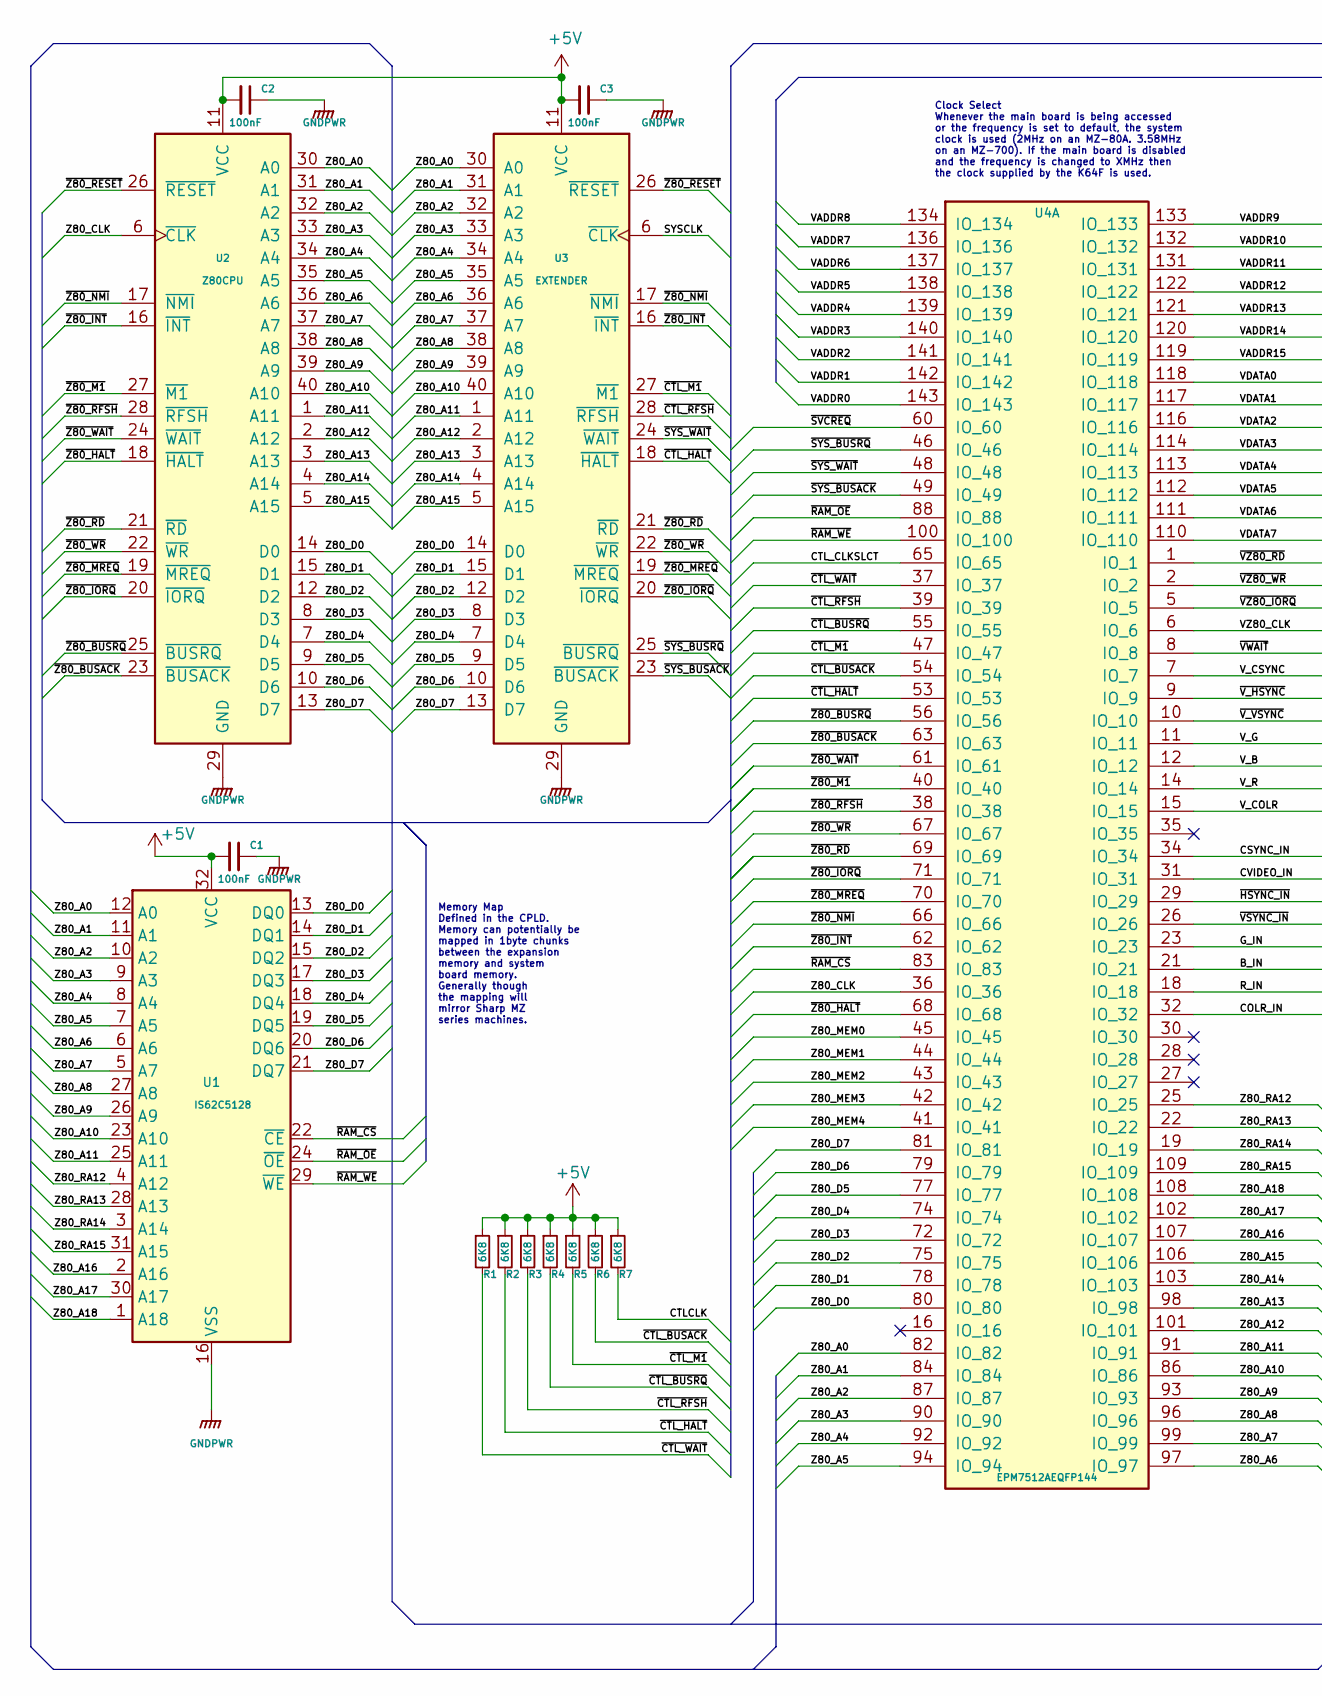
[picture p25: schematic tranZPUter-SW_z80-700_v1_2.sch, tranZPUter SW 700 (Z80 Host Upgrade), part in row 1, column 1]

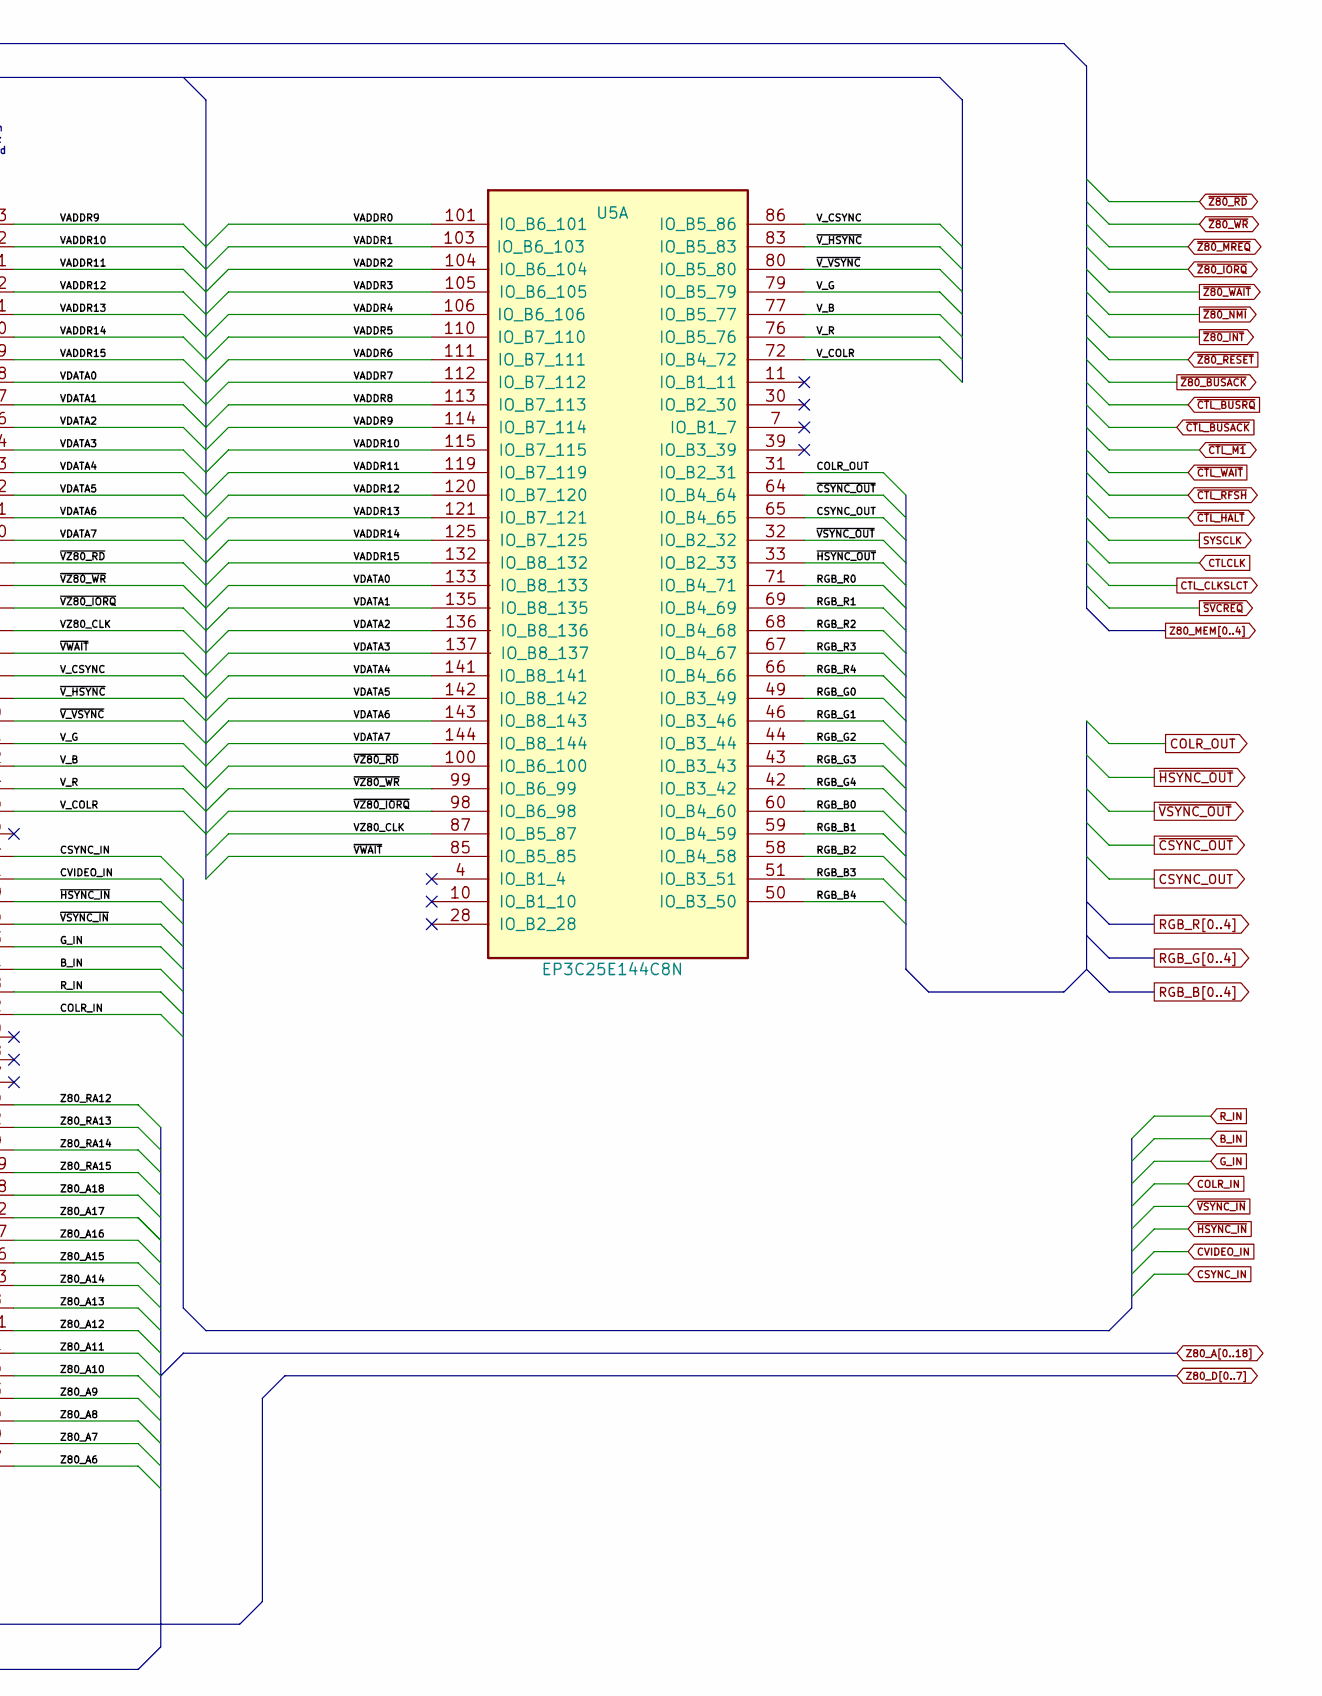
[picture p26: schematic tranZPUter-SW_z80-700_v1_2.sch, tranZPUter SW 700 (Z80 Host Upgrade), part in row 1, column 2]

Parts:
C1, C2, C3: 100nF; C_0805_2012Metric_Pad1.15x1.40mm_HandSolder
R1, R2, R3, R4, R5, R6, R7: 6K8; R_0805_2012Metric_Pad1.15x1.40mm_HandSolder
U1: IS62C5128; TSOP-II-32_21.0x10.2mm_P1.27mm
U2: Z80CPU; DIP-40_W15.24mm_Socket
U3: EXTENDER; DIP-40_W15.24mm_Extender_NoCourtyard
U4: EPM7512AEQFP144; TQFP-144_20x20mm_P0.5mm
U5: EP3C25E144C8N; EQFP-144-1EP_20x20mm_P0.5mm_EP6.61x5.615mm

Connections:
+5V: C1.2, C2.2, C3.2, R1.1, R2.1, R3.1, R4.1, R5.1, R6.1, R7.1, U1.32 (VCC), U2.11 (VCC), U3.11 (VCC); also elsewhere on the board
/Z80 Upgrade/VADDR0: U4.143 (IO_143), U5.101 (IO_B6_101)
/Z80 Upgrade/VADDR1: U4.142 (IO_142), U5.103 (IO_B6_103)
/Z80 Upgrade/VADDR2: U4.141 (IO_141), U5.104 (IO_B6_104)
/Z80 Upgrade/VADDR3: U4.140 (IO_140), U5.105 (IO_B6_105)
/Z80 Upgrade/VADDR4: U4.139 (IO_139), U5.106 (IO_B6_106)
/Z80 Upgrade/VADDR5: U4.138 (IO_138), U5.110 (IO_B7_110)
/Z80 Upgrade/VADDR6: U4.137 (IO_137), U5.111 (IO_B7_111)
/Z80 Upgrade/VADDR7: U4.136 (IO_136), U5.112 (IO_B7_112)
/Z80 Upgrade/VADDR8: U4.134 (IO_134), U5.113 (IO_B7_113)
/Z80 Upgrade/VADDR9: U4.133 (IO_133), U5.114 (IO_B7_114)
/Z80 Upgrade/VADDR10: U4.132 (IO_132), U5.115 (IO_B7_115)
/Z80 Upgrade/VADDR11: U4.131 (IO_131), U5.119 (IO_B7_119)
/Z80 Upgrade/VADDR12: U4.122 (IO_122), U5.120 (IO_B7_120)
/Z80 Upgrade/VADDR13: U4.121 (IO_121), U5.121 (IO_B7_121)
/Z80 Upgrade/VADDR14: U4.120 (IO_120), U5.125 (IO_B7_125)
/Z80 Upgrade/VADDR15: U4.119 (IO_119), U5.132 (IO_B8_132)
/Z80 Upgrade/VDATA0: U4.118 (IO_118), U5.133 (IO_B8_133)
/Z80 Upgrade/VDATA1: U4.117 (IO_117), U5.135 (IO_B8_135)
/Z80 Upgrade/VDATA2: U4.116 (IO_116), U5.136 (IO_B8_136)
/Z80 Upgrade/VDATA3: U4.114 (IO_114), U5.137 (IO_B8_137)
/Z80 Upgrade/VDATA4: U4.113 (IO_113), U5.141 (IO_B8_141)
/Z80 Upgrade/VDATA5: U4.112 (IO_112), U5.142 (IO_B8_142)
/Z80 Upgrade/VDATA6: U4.111 (IO_111), U5.143 (IO_B8_143)
/Z80 Upgrade/VDATA7: U4.110 (IO_110), U5.144 (IO_B8_144)
/Z80 Upgrade/V_B: U4.12 (IO_12), U5.77 (IO_B5_77)
/Z80 Upgrade/V_COLR: U4.15 (IO_15), U5.72 (IO_B4_72)
/Z80 Upgrade/V_CSYNC: U4.7 (IO_7), U5.86 (IO_B5_86)
/Z80 Upgrade/V_CVIDEO: U4.8 (IO_8), U5.85 (IO_B5_85)
/Z80 Upgrade/V_G: U4.11 (IO_11), U5.79 (IO_B5_79)
/Z80 Upgrade/V_R: U4.14 (IO_14), U5.76 (IO_B5_76)
/Z80 Upgrade/Z80_CLK: U2.6 (~CLK~), U4.36 (IO_36)
/Z80 Upgrade/Z80_RA12: U1.4 (A12), U4.25 (IO_25)
/Z80 Upgrade/Z80_RA13: U1.28 (A13), U4.22 (IO_22)
/Z80 Upgrade/Z80_RA14: U1.3 (A14), U4.19 (IO_19)
/Z80 Upgrade/Z80_RA15: U1.31 (A15), U4.109 (IO_109)
/Z80 Upgrade/~RAM_CS~: U1.22 (~CE~), U4.83 (IO_83)
/Z80 Upgrade/~RAM_OE~: U1.24 (~OE~), U4.88 (IO_88)
/Z80 Upgrade/~RAM_WE~: U1.29 (~WE~), U4.100 (IO_100)
/Z80 Upgrade/~SYS_BUSACK~: U3.23 (~BUSACK~), U4.49 (IO_49)
/Z80 Upgrade/~SYS_BUSRQ~: U3.25 (~BUSRQ~), U4.46 (IO_46)
/Z80 Upgrade/~SYS_WAIT~: U3.24 (~WAIT~), U4.48 (IO_48)
/Z80 Upgrade/~VZ80_IORQ~: U4.6 (IO_6), U5.87 (IO_B5_87)
/Z80 Upgrade/~VZ80_MREQ~: U4.5 (IO_5), U5.98 (IO_B6_98)
/Z80 Upgrade/~VZ80_RD~: U4.1 (IO_1), U5.100 (IO_B6_100)
/Z80 Upgrade/~VZ80_WR~: U4.2 (IO_2), U5.99 (IO_B6_99)
/Z80 Upgrade/~V_HSYNC~: U4.9 (IO_9), U5.83 (IO_B5_83)
/Z80 Upgrade/~V_VSYNC~: U4.10 (IO_10), U5.80 (IO_B5_80)
/Z80 Upgrade/~Z80_BUSRQ~: U2.25 (~BUSRQ~), U4.56 (IO_56)
/Z80 Upgrade/~Z80_HALT~: U2.18 (~HALT~), U4.68 (IO_68)
/Z80 Upgrade/~Z80_M1~: U2.27 (~M1~), U4.40 (IO_40)
/Z80 Upgrade/~Z80_RFSH~: U2.28 (~RFSH~), U4.38 (IO_38)
B_IN: U4.21 (IO_21); also elsewhere on the board
COLR_IN: U4.32 (IO_32); also elsewhere on the board
COLR_OUT: U5.31 (IO_B2_31); also elsewhere on the board
CSYNC_IN: U4.34 (IO_34); also elsewhere on the board
CSYNC_OUT: U5.65 (IO_B4_65); also elsewhere on the board
CTLCLK: R7.2; also elsewhere on the board
CTL_CLKSLCT: U4.65 (IO_65); also elsewhere on the board
CVIDEO_IN: U4.31 (IO_31); also elsewhere on the board
GNDPWR: C1.1, C2.1, C3.1, U1.16 (VSS), U2.29 (GND), U3.29 (GND); also elsewhere on the board
G_IN: U4.23 (IO_23); also elsewhere on the board
RGB_B0: U5.60 (IO_B4_60); also elsewhere on the board
RGB_B1: U5.59 (IO_B4_59); also elsewhere on the board
RGB_B2: U5.58 (IO_B4_58); also elsewhere on the board
RGB_B3: U5.51 (IO_B3_51); also elsewhere on the board
RGB_B4: U5.50 (IO_B3_50); also elsewhere on the board
RGB_G0: U5.49 (IO_B3_49); also elsewhere on the board
RGB_G1: U5.46 (IO_B3_46); also elsewhere on the board
RGB_G2: U5.44 (IO_B3_44); also elsewhere on the board
RGB_G3: U5.43 (IO_B3_43); also elsewhere on the board
RGB_G4: U5.42 (IO_B3_42); also elsewhere on the board
RGB_R0: U5.71 (IO_B4_71); also elsewhere on the board
RGB_R1: U5.69 (IO_B4_69); also elsewhere on the board
RGB_R2: U5.68 (IO_B4_68); also elsewhere on the board
RGB_R3: U5.67 (IO_B4_67); also elsewhere on the board
RGB_R4: U5.66 (IO_B4_66); also elsewhere on the board
R_IN: U4.18 (IO_18); also elsewhere on the board
SYSCLK: U3.6 (~CLK~); also elsewhere on the board
Z80_A0: U1.12 (A0), U2.30 (A0), U3.30 (A0), U4.82 (IO_82); also elsewhere on the board
Z80_A1: U1.11 (A1), U2.31 (A1), U3.31 (A1), U4.84 (IO_84); also elsewhere on the board
Z80_A2: U1.10 (A2), U2.32 (A2), U3.32 (A2), U4.87 (IO_87); also elsewhere on the board
Z80_A3: U1.9 (A3), U2.33 (A3), U3.33 (A3), U4.90 (IO_90); also elsewhere on the board
Z80_A4: U1.8 (A4), U2.34 (A4), U3.34 (A4), U4.92 (IO_92); also elsewhere on the board
Z80_A5: U1.7 (A5), U2.35 (A5), U3.35 (A5), U4.94 (IO_94); also elsewhere on the board
Z80_A6: U1.6 (A6), U2.36 (A6), U3.36 (A6), U4.97 (IO_97); also elsewhere on the board
Z80_A7: U1.5 (A7), U2.37 (A7), U3.37 (A7), U4.99 (IO_99); also elsewhere on the board
Z80_A8: U1.27 (A8), U2.38 (A8), U3.38 (A8), U4.96 (IO_96); also elsewhere on the board
Z80_A9: U1.26 (A9), U2.39 (A9), U3.39 (A9), U4.93 (IO_93); also elsewhere on the board
Z80_A10: U1.23 (A10), U2.40 (A10), U3.40 (A10), U4.86 (IO_86); also elsewhere on the board
Z80_A11: U1.25 (A11), U2.1 (A11), U3.1 (A11), U4.91 (IO_91); also elsewhere on the board
Z80_A12: U2.2 (A12), U3.2 (A12), U4.101 (IO_101); also elsewhere on the board
Z80_A13: U2.3 (A13), U3.3 (A13), U4.98 (IO_98); also elsewhere on the board
Z80_A14: U2.4 (A14), U3.4 (A14), U4.103 (IO_103); also elsewhere on the board
Z80_A15: U2.5 (A15), U3.5 (A15), U4.106 (IO_106); also elsewhere on the board
Z80_A16: U1.2 (A16), U4.107 (IO_107); also elsewhere on the board
Z80_A17: U1.30 (A17), U4.102 (IO_102); also elsewhere on the board
Z80_A18: U1.1 (A18), U4.108 (IO_108); also elsewhere on the board
Z80_D0: U1.13 (DQ0), U2.14 (D0), U3.14 (D0), U4.80 (IO_80); also elsewhere on the board
Z80_D1: U1.14 (DQ1), U2.15 (D1), U3.15 (D1), U4.78 (IO_78); also elsewhere on the board
Z80_D2: U1.15 (DQ2), U2.12 (D2), U3.12 (D2), U4.75 (IO_75); also elsewhere on the board
Z80_D3: U1.17 (DQ3), U2.8 (D3), U3.8 (D3), U4.72 (IO_72); also elsewhere on the board
Z80_D4: U1.18 (DQ4), U2.7 (D4), U3.7 (D4), U4.74 (IO_74); also elsewhere on the board
Z80_D5: U1.19 (DQ5), U2.9 (D5), U3.9 (D5), U4.77 (IO_77); also elsewhere on the board
Z80_D6: U1.20 (DQ6), U2.10 (D6), U3.10 (D6), U4.79 (IO_79); also elsewhere on the board
Z80_D7: U1.21 (DQ7), U2.13 (D7), U3.13 (D7), U4.81 (IO_81); also elsewhere on the board
Z80_MEM0: U4.45 (IO_45); also elsewhere on the board
Z80_MEM1: U4.44 (IO_44); also elsewhere on the board
Z80_MEM2: U4.43 (IO_43); also elsewhere on the board
Z80_MEM3: U4.42 (IO_42); also elsewhere on the board
Z80_MEM4: U4.41 (IO_41); also elsewhere on the board
~CSYNC_OUT~: U5.64 (IO_B4_64); also elsewhere on the board
~CTL_BUSACK~: R6.2, U4.54 (IO_54); also elsewhere on the board
~CTL_BUSRQ~: R4.2, U4.55 (IO_55); also elsewhere on the board
~CTL_HALT~: R2.2, U3.18 (~HALT~), U4.53 (IO_53); also elsewhere on the board
~CTL_M1~: R5.2, U3.27 (~M1~), U4.47 (IO_47); also elsewhere on the board
~CTL_RFSH~: R3.2, U3.28 (~RFSH~), U4.39 (IO_39); also elsewhere on the board
~CTL_WAIT~: R1.2, U4.37 (IO_37); also elsewhere on the board
~HSYNC_IN~: U4.29 (IO_29); also elsewhere on the board
~HSYNC_OUT~: U5.33 (IO_B2_33); also elsewhere on the board
~SVCREQ~: U4.60 (IO_60); also elsewhere on the board
~VSYNC_IN~: U4.26 (IO_26); also elsewhere on the board
~VSYNC_OUT~: U5.32 (IO_B2_32); also elsewhere on the board
~Z80_BUSACK~: U2.23 (~BUSACK~), U4.63 (IO_63); also elsewhere on the board
~Z80_INT~: U2.16 (~INT~), U3.16 (~INT~), U4.62 (IO_62); also elsewhere on the board
~Z80_IORQ~: U2.20 (~IORQ~), U3.20 (~IORQ~), U4.71 (IO_71); also elsewhere on the board
~Z80_MREQ~: U2.19 (~MREQ~), U3.19 (~MREQ~), U4.70 (IO_70); also elsewhere on the board
~Z80_NMI~: U2.17 (~NMI~), U3.17 (~NMI~), U4.66 (IO_66); also elsewhere on the board
~Z80_RD~: U2.21 (~RD~), U3.21 (~RD~), U4.69 (IO_69); also elsewhere on the board
~Z80_RESET~: U2.26 (~RESET~), U3.26 (~RESET~); also elsewhere on the board
~Z80_WAIT~: U2.24 (~WAIT~), U4.61 (IO_61); also elsewhere on the board
~Z80_WR~: U2.22 (~WR~), U3.22 (~WR~), U4.67 (IO_67); also elsewhere on the board

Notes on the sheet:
Clock Select Whenever the main board is being accessed or the frequency is set to default, the system clock is used (2MHz on an MZ-80A. 3.58MHz on an MZ-700). If the main board is disabled and the frequency is changed to XMHz then the clock supplied by the K64F is used.
Memory Map Defined in the CPLD. Memory can potentially be mapped in 1byte chunks between the expansion memory and system board memory. Generally though the mapping will mirror Sharp MZ series machines.

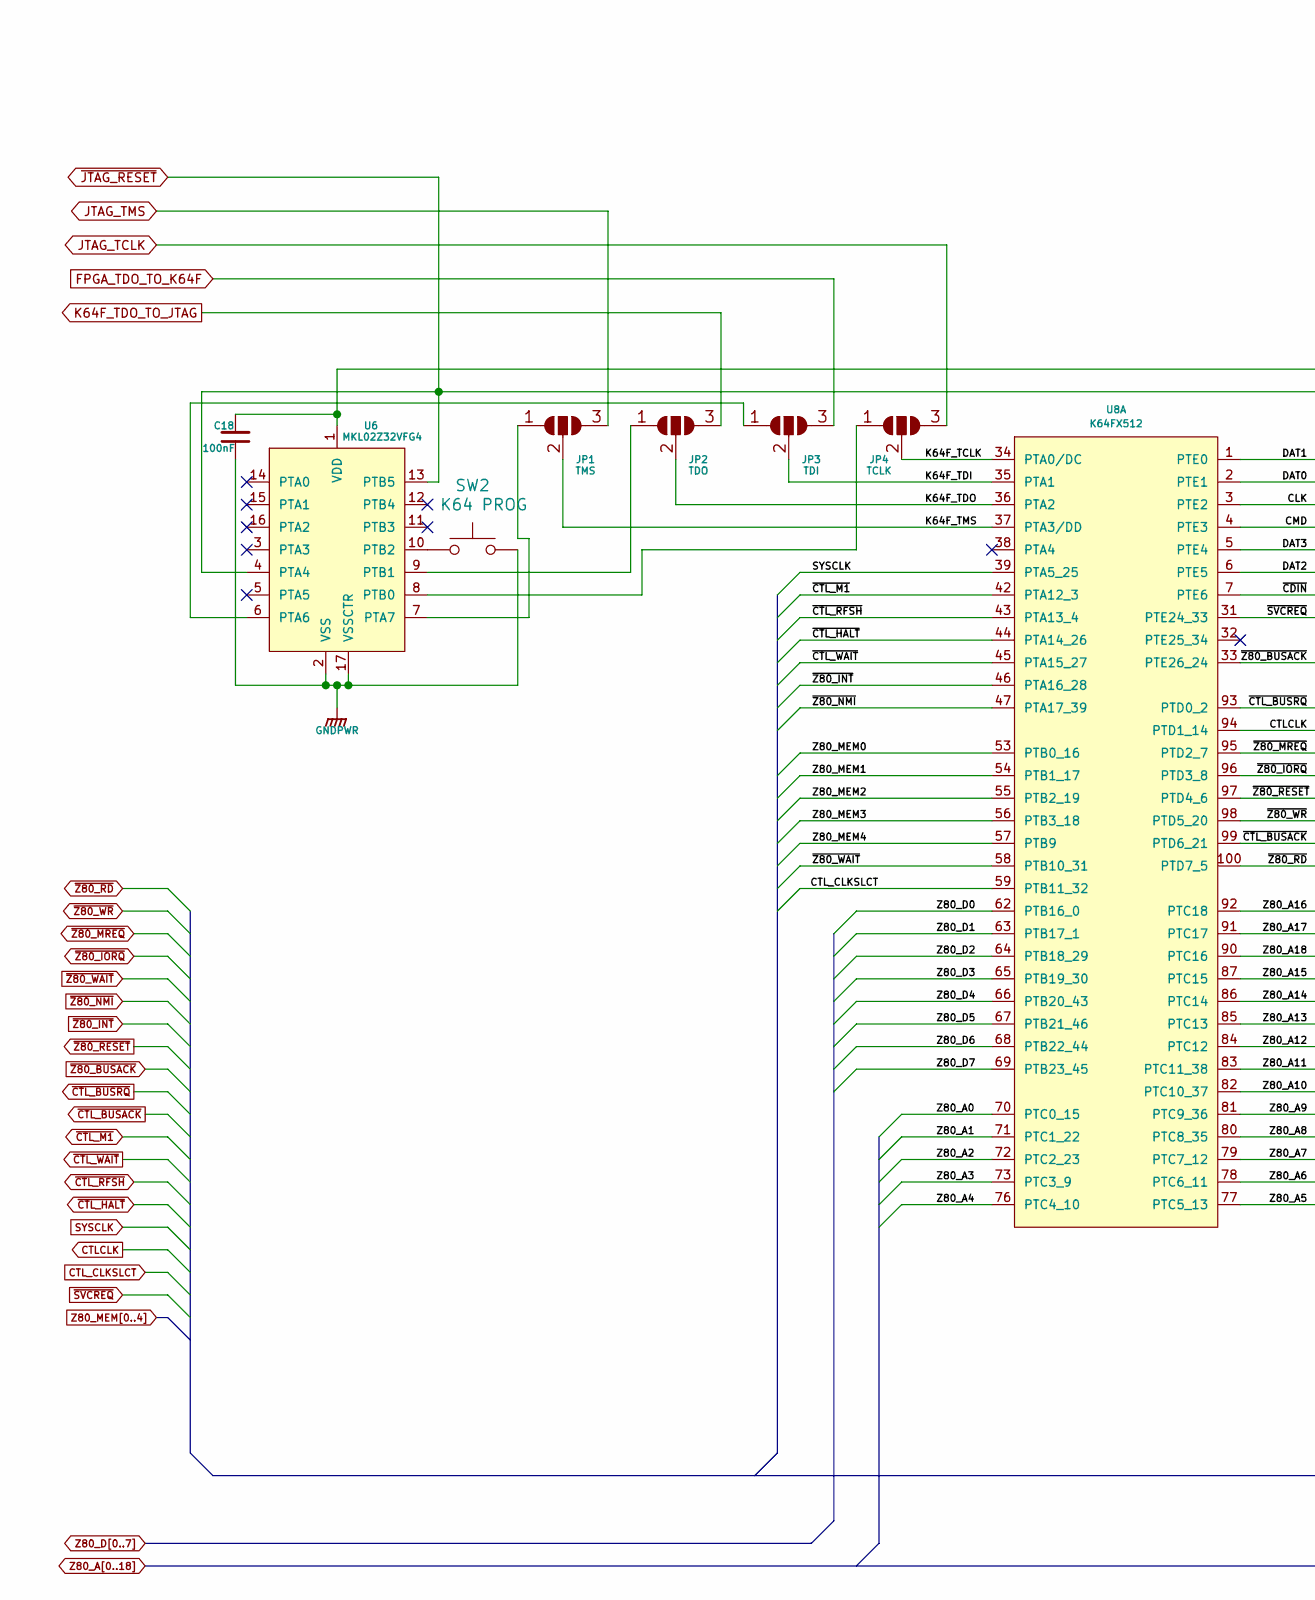
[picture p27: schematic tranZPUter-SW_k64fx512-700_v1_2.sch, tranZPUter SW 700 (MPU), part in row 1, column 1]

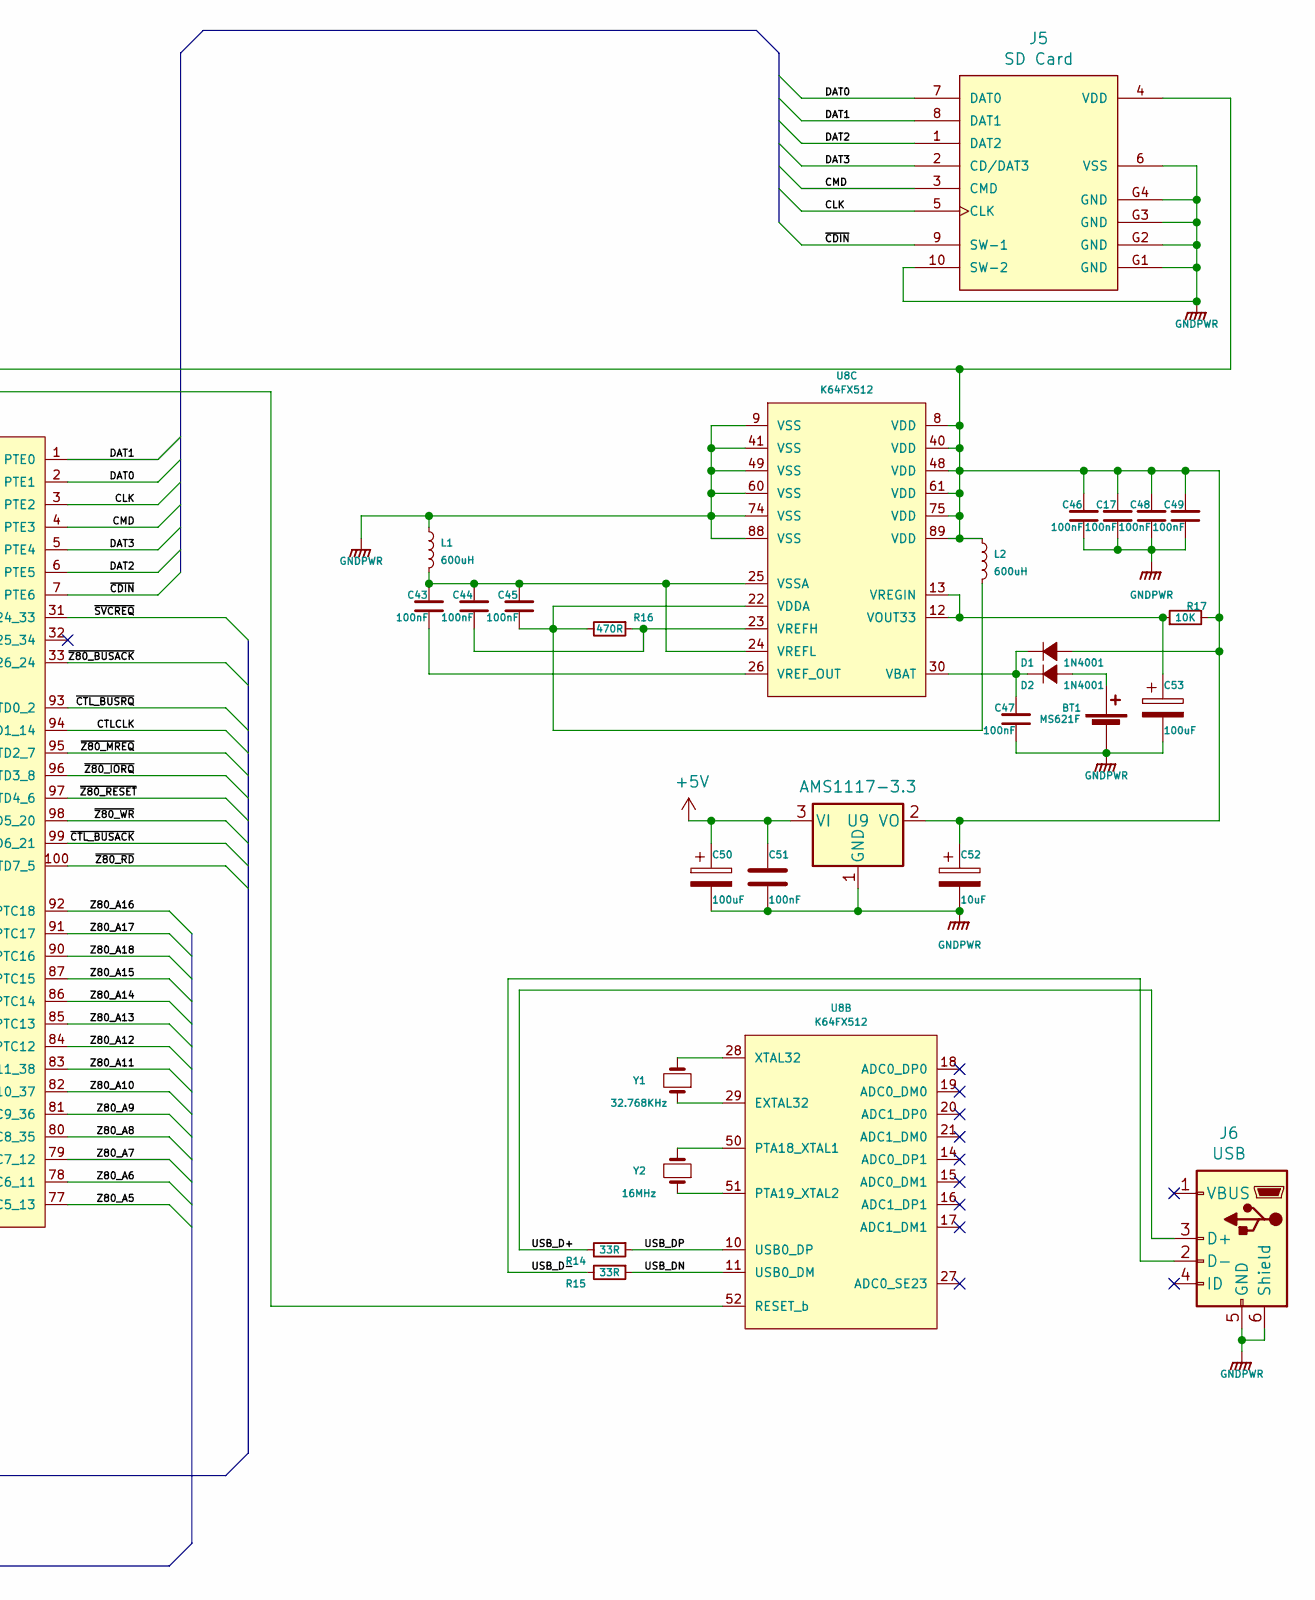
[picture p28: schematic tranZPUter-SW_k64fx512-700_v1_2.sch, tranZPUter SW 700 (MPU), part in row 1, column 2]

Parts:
BT1: MS621F; BatteryHolder_Seiko_MS621F
C17, C18, C43, C44, C45, C46, C47, C48, C49: 100nF; C_0805_2012Metric_Pad1.15x1.40mm_HandSolder
C50, C53: 100uF; C_0603_1608Metric_Pad1.05x0.95mm_HandSolder
C51: 100nF; C_0603_1608Metric_Pad1.05x0.95mm_HandSolder
C52: 10uF; C_0603_1608Metric_Pad1.05x0.95mm_HandSolder
D1, D2: 1N4001; D_1206_3216Metric
J5: SD Card; MOLEX_104031-0811
J6: USB; USB_Micro-B_Amphenol_10103594-0001LF_Horizontal
JP1: TMS; SolderJumper-3_Open
JP2: TDO; SolderJumper-3_Open
JP3: TDI; SolderJumper-3_Open
JP4: TCLK; SolderJumper-3_Open
L1, L2: 600uH; L_0603_1608Metric
R14, R15: 33R; R_0805_2012Metric_Pad1.15x1.40mm_HandSolder
R16: 470R; R_0805_2012Metric_Pad1.15x1.40mm_HandSolder
R17: 10K; R_0805_2012Metric_Pad1.15x1.40mm_HandSolder
SW2: K64 PROG; SW_SPST_B3S-1000
U6: MKL02Z32VFG4; QFN-16-1EP_3x3mm_P0.5mm_EP1.75x1.75mm
U8: K64FX512; LQFP-100_14x14mm_P0.5mm
U9: AMS1117-3.3; SOT-223-3_TabPin2
Y1: 32.768KHz; Crystal_SMD_2012-2Pin_2.0x1.2mm_HandSoldering
Y2: 16MHz; Crystal_SMD_Abracon_ABM8G-4Pin_3.2x2.5mm

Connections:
+5V: C50.1, C51.1, U9.3 (VI); also elsewhere on the board
/NXP K64FX512/CLK: J5.5 (CLK), U8.3 (PTE2)
/NXP K64FX512/CMD: J5.3 (CMD), U8.4 (PTE3)
/NXP K64FX512/DAT0: J5.7 (DAT0), U8.2 (PTE1)
/NXP K64FX512/DAT1: J5.8 (DAT1), U8.1 (PTE0)
/NXP K64FX512/DAT2: J5.1 (DAT2), U8.6 (PTE5)
/NXP K64FX512/DAT3: J5.2 (CD/DAT3), U8.5 (PTE4)
/NXP K64FX512/K64F_TCLK: JP4.2 (C), U8.34 (PTA0/DC)
/NXP K64FX512/K64F_TDI: JP3.2 (C), U8.35 (PTA1)
/NXP K64FX512/K64F_TDO: JP2.2 (C), U8.36 (PTA2)
/NXP K64FX512/K64F_TMS: JP1.2 (C), U8.37 (PTA3/DD)
/NXP K64FX512/USB_D+: J6.3 (D+), R14.2
/NXP K64FX512/USB_D-: J6.2 (D-), R15.2
/NXP K64FX512/USB_DN: R15.1, U8.11 (USB0_DM)
/NXP K64FX512/USB_DP: R14.1, U8.10 (USB0_DP)
/NXP K64FX512/~CDIN~: J5.9 (SW-1), U8.7 (PTE6)
CTLCLK: U8.94 (PTD1_14); also elsewhere on the board
CTL_CLKSLCT: U8.59 (PTB11_32); also elsewhere on the board
FPGA_TDO_TO_K64F: JP3.3 (B); also elsewhere on the board
GNDPWR: BT1.2 (-), C17.1, C18.1, C46.1, C47.1, C48.1, C49.1, C50.2, C51.2, C52.2, C53.2, J5.6 (VSS), J5.10 (SW-2), J5.G1 (GND), J5.G2 (GND), J5.G3 (GND), J5.G4 (GND), J6.5 (GND), J6.6 (Shield), L1.1, SW2.2, U6.2 (VSS), U6.17 (VSSCTR), U8.9 (VSS), U8.41 (VSS), U8.49 (VSS), U8.60 (VSS), U8.74 (VSS), U8.88 (VSS), U9.1 (GND); also elsewhere on the board
JTAG_TCLK: JP4.3 (B); also elsewhere on the board
JTAG_TMS: JP1.3 (B); also elsewhere on the board
K64F_TDO_TO_JTAG: JP2.3 (B); also elsewhere on the board
unnamed: BT1.1 (+), D2.2 (A)
unnamed: C17.2, C18.2, C46.2, C48.2, C49.2, C52.1, D1.2 (A), J5.4 (VDD), L2.1, R17.2, U6.1 (VDD), U8.8 (VDD), U8.40 (VDD), U8.48 (VDD), U8.61 (VDD), U8.75 (VDD), U8.89 (VDD), U9.2 (VO)
unnamed: C43.1, U8.26 (VREF_OUT)
unnamed: C43.2, C44.2, C45.2, L1.2, U8.24 (VREFL), U8.25 (VSSA)
unnamed: C44.1, R16.1, U8.23 (VREFH)
unnamed: C45.1, L2.2, R16.2, U8.22 (VDDA)
unnamed: C47.2, D1.1 (K), D2.1 (K), U8.30 (VBAT)
unnamed: C53.1, R17.1, U8.12 (VOUT33), U8.13 (VREGIN)
unnamed: JP1.1 (A), U6.7 (PTA7)
unnamed: JP2.1 (A), U6.9 (PTB1)
unnamed: JP3.1 (A), U6.6 (PTA6)
unnamed: JP4.1 (A), U6.8 (PTB0)
unnamed: SW2.1, U6.10 (PTB2)
unnamed: U8.28 (XTAL32), Y1.2
unnamed: U8.29 (EXTAL32), Y1.1
unnamed: U8.50 (PTA18_XTAL1), Y2.2
unnamed: U8.51 (PTA19_XTAL2), Y2.1
SYSCLK: U8.39 (PTA5_25); also elsewhere on the board
Z80_A0: U8.70 (PTC0_15); also elsewhere on the board
Z80_A1: U8.71 (PTC1_22); also elsewhere on the board
Z80_A2: U8.72 (PTC2_23); also elsewhere on the board
Z80_A3: U8.73 (PTC3_9); also elsewhere on the board
Z80_A4: U8.76 (PTC4_10); also elsewhere on the board
Z80_A5: U8.77 (PTC5_13); also elsewhere on the board
Z80_A6: U8.78 (PTC6_11); also elsewhere on the board
Z80_A7: U8.79 (PTC7_12); also elsewhere on the board
Z80_A8: U8.80 (PTC8_35); also elsewhere on the board
Z80_A9: U8.81 (PTC9_36); also elsewhere on the board
Z80_A10: U8.82 (PTC10_37); also elsewhere on the board
Z80_A11: U8.83 (PTC11_38); also elsewhere on the board
Z80_A12: U8.84 (PTC12); also elsewhere on the board
Z80_A13: U8.85 (PTC13); also elsewhere on the board
Z80_A14: U8.86 (PTC14); also elsewhere on the board
Z80_A15: U8.87 (PTC15); also elsewhere on the board
Z80_A16: U8.92 (PTC18); also elsewhere on the board
Z80_A17: U8.91 (PTC17); also elsewhere on the board
Z80_A18: U8.90 (PTC16); also elsewhere on the board
Z80_D0: U8.62 (PTB16_0); also elsewhere on the board
Z80_D1: U8.63 (PTB17_1); also elsewhere on the board
Z80_D2: U8.64 (PTB18_29); also elsewhere on the board
Z80_D3: U8.65 (PTB19_30); also elsewhere on the board
Z80_D4: U8.66 (PTB20_43); also elsewhere on the board
Z80_D5: U8.67 (PTB21_46); also elsewhere on the board
Z80_D6: U8.68 (PTB22_44); also elsewhere on the board
Z80_D7: U8.69 (PTB23_45); also elsewhere on the board
Z80_MEM0: U8.53 (PTB0_16); also elsewhere on the board
Z80_MEM1: U8.54 (PTB1_17); also elsewhere on the board
Z80_MEM2: U8.55 (PTB2_19); also elsewhere on the board
Z80_MEM3: U8.56 (PTB3_18); also elsewhere on the board
Z80_MEM4: U8.57 (PTB9); also elsewhere on the board
~CTL_BUSACK~: U8.99 (PTD6_21); also elsewhere on the board
~CTL_BUSRQ~: U8.93 (PTD0_2); also elsewhere on the board
~CTL_HALT~: U8.44 (PTA14_26); also elsewhere on the board
~CTL_M1~: U8.42 (PTA12_3); also elsewhere on the board
~CTL_RFSH~: U8.43 (PTA13_4); also elsewhere on the board
~CTL_WAIT~: U8.45 (PTA15_27); also elsewhere on the board
~JTAG_RESET~: U6.4 (PTA4), U6.13 (PTB5), U8.52 (RESET_b); also elsewhere on the board
~SVCREQ~: U8.31 (PTE24_33); also elsewhere on the board
~Z80_BUSACK~: U8.33 (PTE26_24); also elsewhere on the board
~Z80_INT~: U8.46 (PTA16_28); also elsewhere on the board
~Z80_IORQ~: U8.96 (PTD3_8); also elsewhere on the board
~Z80_MREQ~: U8.95 (PTD2_7); also elsewhere on the board
~Z80_NMI~: U8.47 (PTA17_39); also elsewhere on the board
~Z80_RD~: U8.100 (PTD7_5); also elsewhere on the board
~Z80_RESET~: U8.97 (PTD4_6); also elsewhere on the board
~Z80_WAIT~: U8.58 (PTB10_31); also elsewhere on the board
~Z80_WR~: U8.98 (PTD5_20); also elsewhere on the board

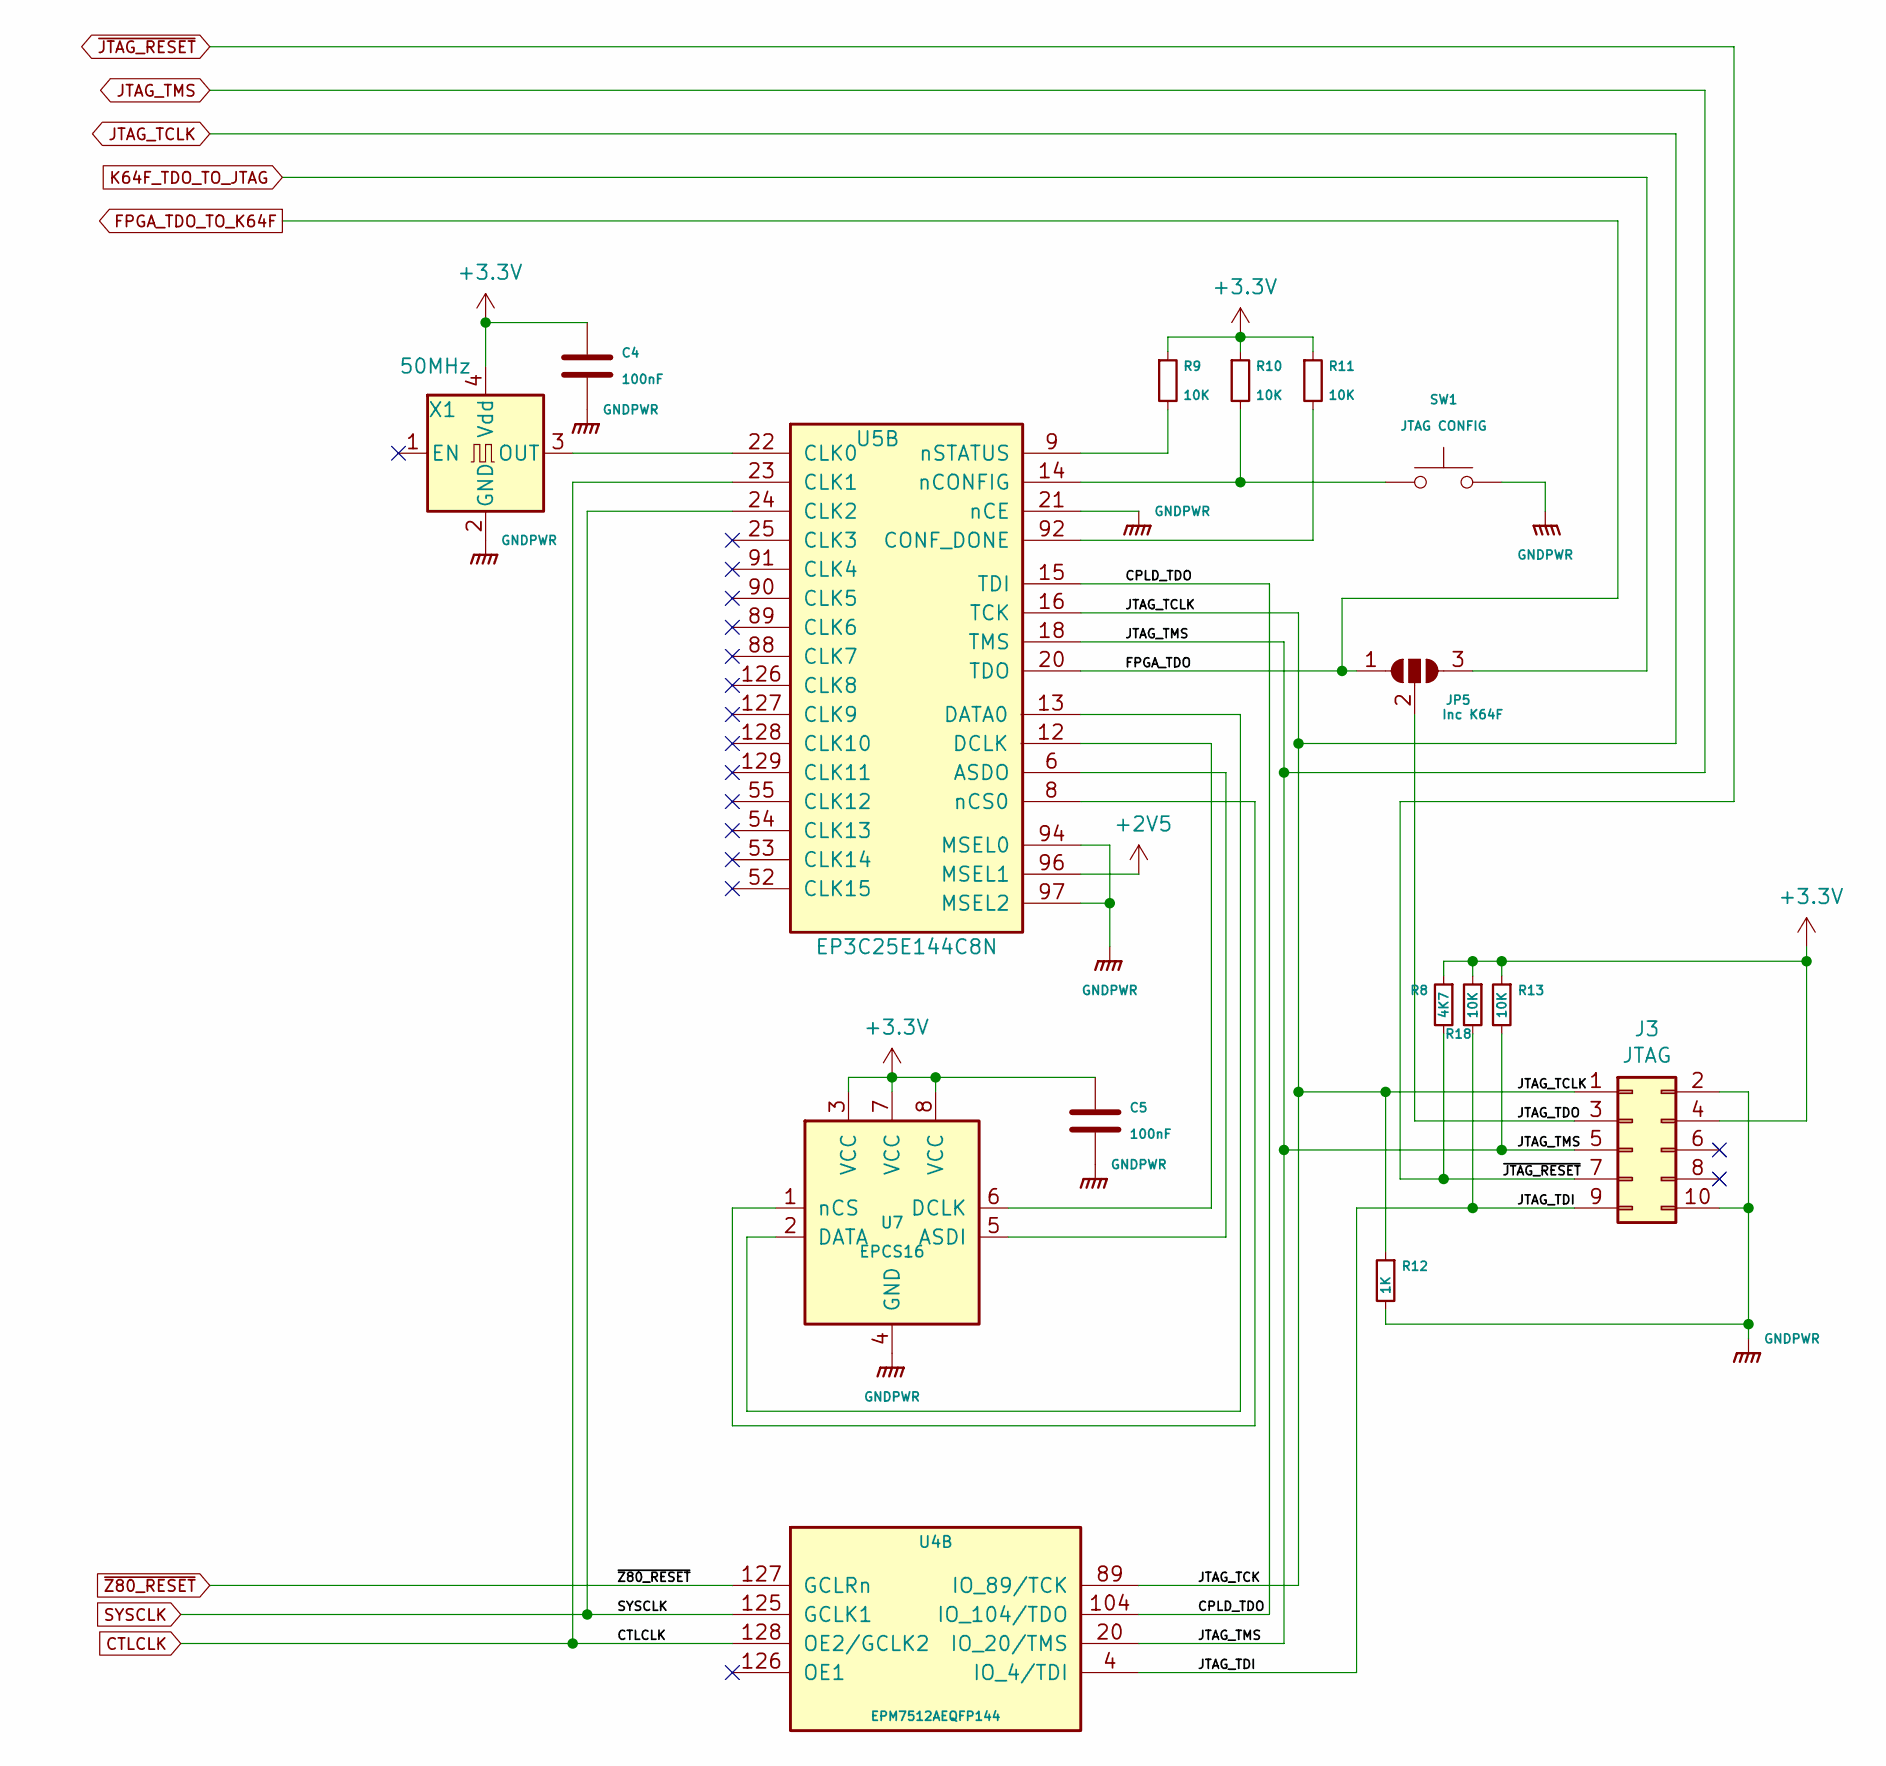
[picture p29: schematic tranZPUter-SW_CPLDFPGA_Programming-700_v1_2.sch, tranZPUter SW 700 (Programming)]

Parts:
C4, C5: 100nF; C_0603_1608Metric_Pad1.05x0.95mm_HandSolder
J3: JTAG; PinHeader_2x05_P2.54mm_Horizontal_NoBug
JP5: Inc K64F; SolderJumper-3_Open
R8: 4K7; R_0805_2012Metric_Pad1.15x1.40mm_HandSolder
R9, R10, R11, R13, R18: 10K; R_0805_2012Metric_Pad1.15x1.40mm_HandSolder
R12: 1K; R_0805_2012Metric_Pad1.15x1.40mm_HandSolder
SW1: JTAG CONFIG; SW_SPST_B3S-1000
U4: EPM7512AEQFP144; TQFP-144_20x20mm_P0.5mm
U5: EP3C25E144C8N; EQFP-144-1EP_20x20mm_P0.5mm_EP6.61x5.615mm
U7: EPCS16; SOIC-8_3.9x4.9mm_P1.27mm
X1: 50MHz; Oscillator_SMD_Abracon_ASE-4Pin_3.2x2.5mm

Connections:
+2V5: U5.96 (MSEL1); also elsewhere on the board
/CPLD and FPGA Programming/CPLD_TDO: U4.104 (IO_104/TDO), U5.15 (TDI)
/CPLD and FPGA Programming/JTAG_TDI: J3.9, R18.2, U4.4 (IO_4/TDI)
/CPLD and FPGA Programming/JTAG_TDO: J3.3, JP5.2 (C)
CTLCLK: U4.128 (OE2/GCLK2), U5.23 (CLK1); also elsewhere on the board
FPGA_TDO_TO_K64F: JP5.1 (A), U5.20 (TDO); also elsewhere on the board
GNDPWR: C4.2, C5.2, J3.2, J3.10, R12.2, SW1.2, U5.21 (nCE), U5.94 (MSEL0), U5.97 (MSEL2), U7.4 (GND), X1.2 (GND); also elsewhere on the board
JTAG_TCLK: J3.1, R12.1, U4.89 (IO_89/TCK), U5.16 (TCK); also elsewhere on the board
JTAG_TMS: J3.5, R13.2, U4.20 (IO_20/TMS), U5.18 (TMS); also elsewhere on the board
K64F_TDO_TO_JTAG: JP5.3 (B); also elsewhere on the board
unnamed: R9.2, U5.9 (nSTATUS)
unnamed: R10.2, SW1.1, U5.14 (nCONFIG)
unnamed: R11.2, U5.92 (CONF_DONE)
unnamed: U5.6 (ASDO), U7.5 (ASDI)
unnamed: U5.8 (nCS0), U7.1 (nCS)
unnamed: U5.12 (DCLK), U7.6 (DCLK)
unnamed: U5.13 (DATA0), U7.2 (DATA)
unnamed: U5.22 (CLK0), X1.3 (OUT)
SYSCLK: U4.125 (GCLK1), U5.24 (CLK2); also elsewhere on the board
~JTAG_RESET~: J3.7, R8.2; also elsewhere on the board
~Z80_RESET~: U4.127 (GCLRn); also elsewhere on the board

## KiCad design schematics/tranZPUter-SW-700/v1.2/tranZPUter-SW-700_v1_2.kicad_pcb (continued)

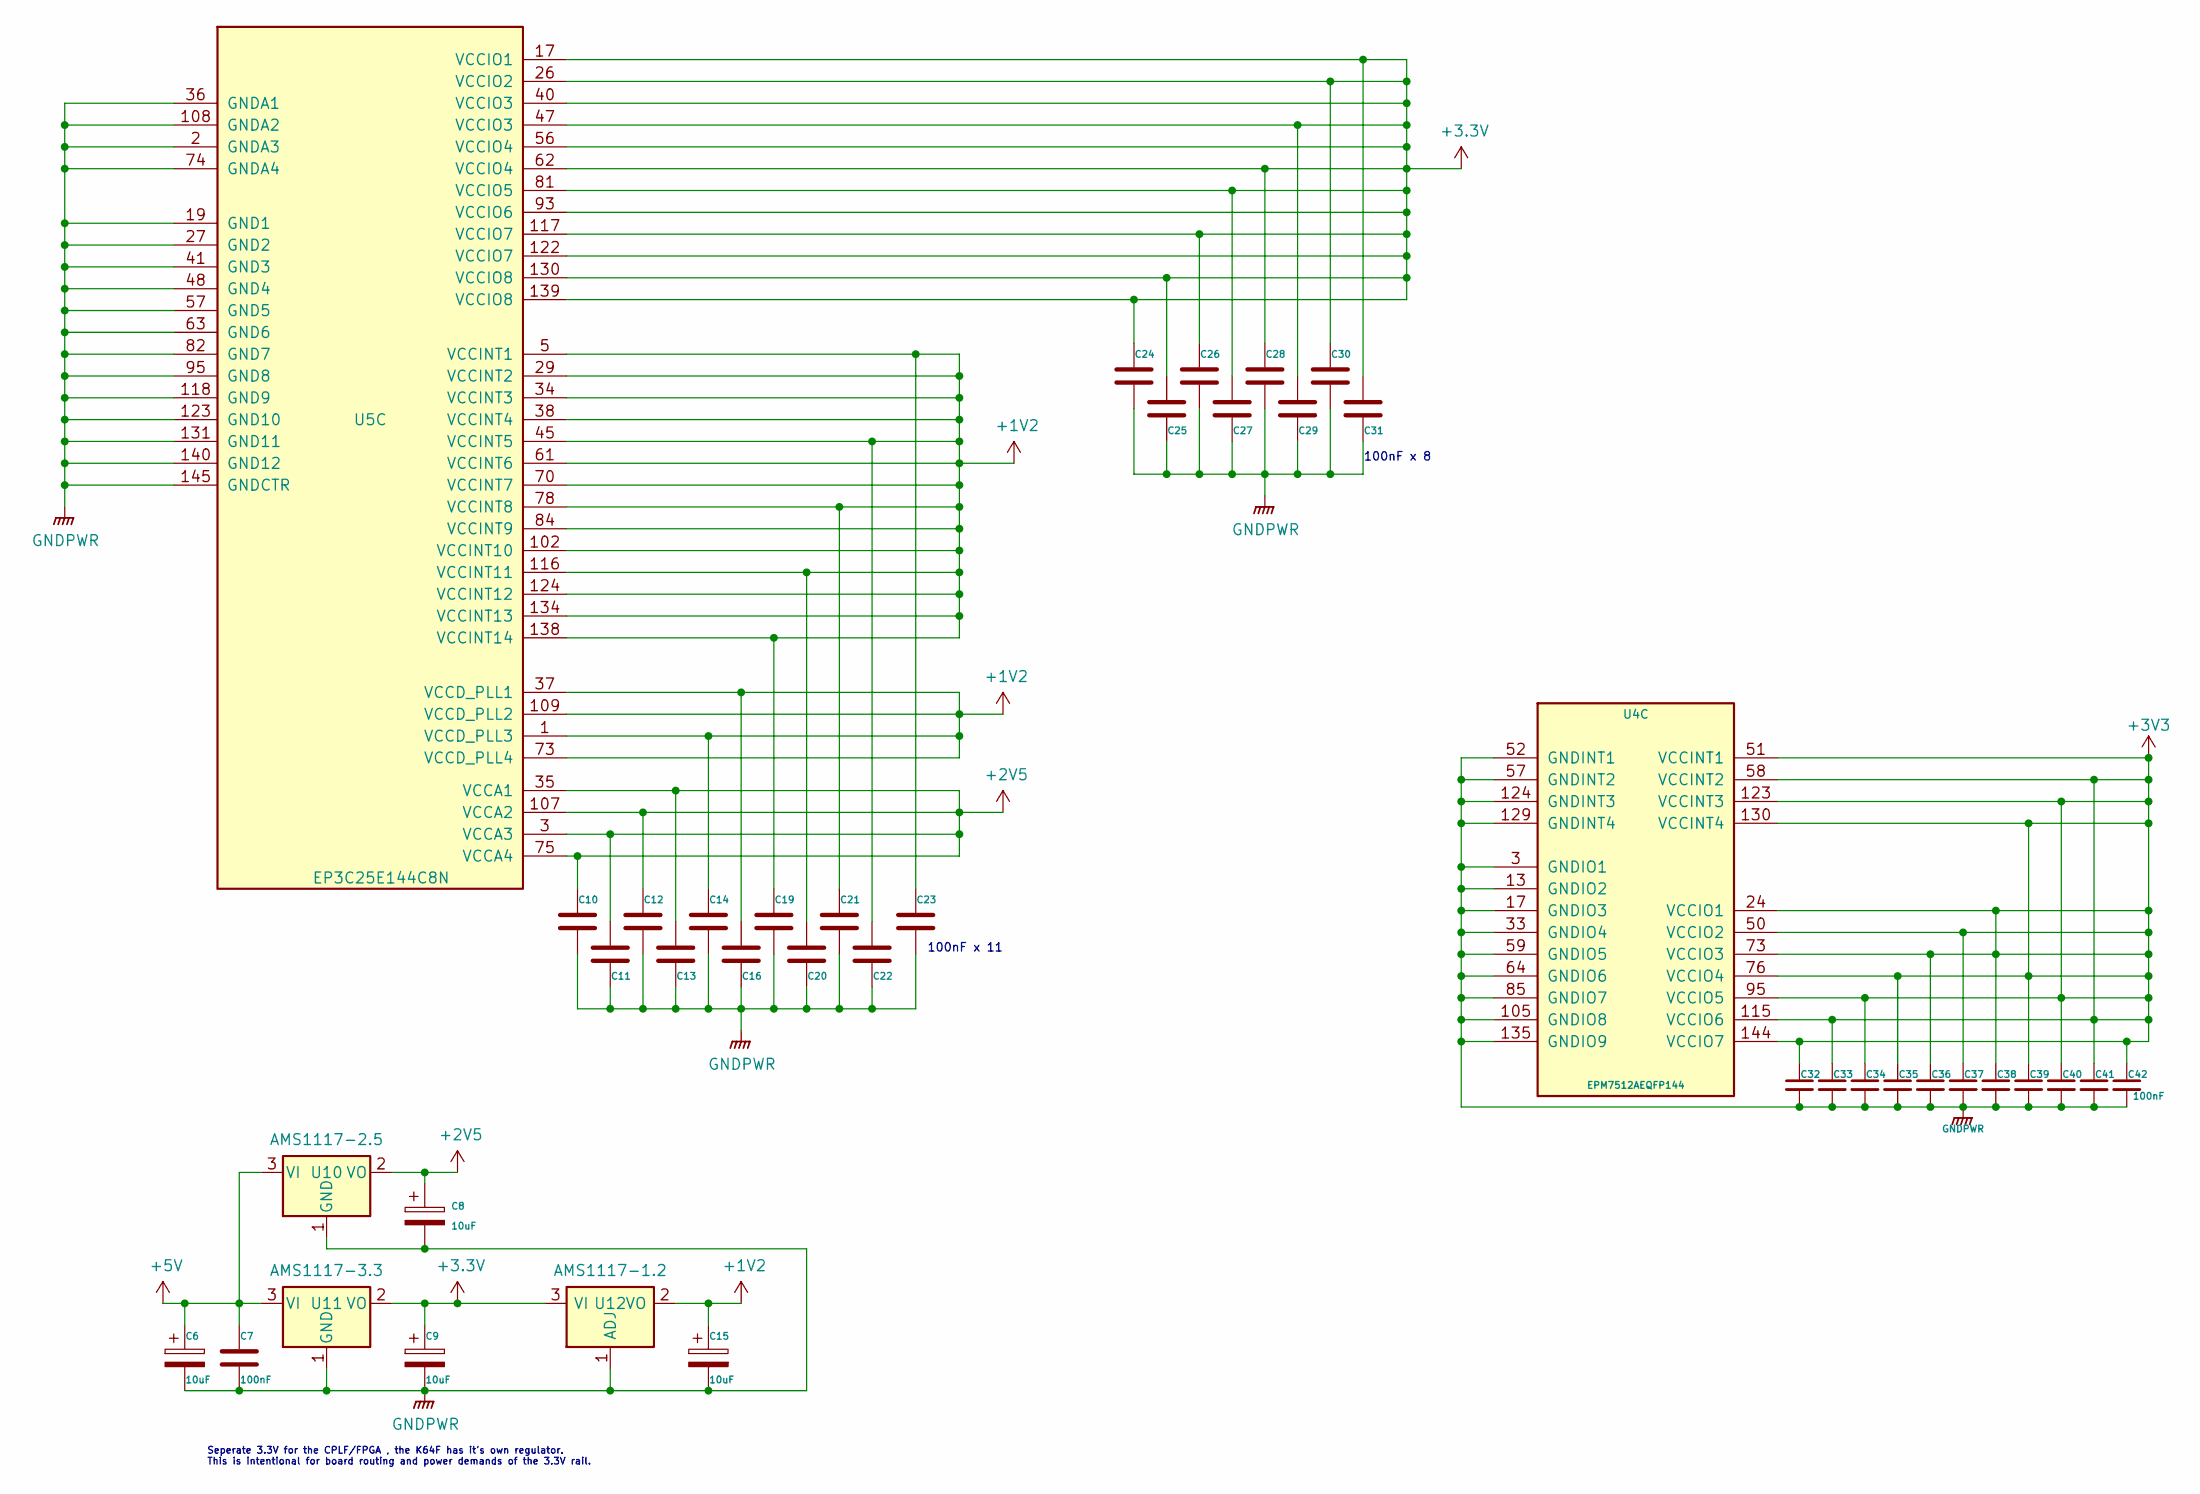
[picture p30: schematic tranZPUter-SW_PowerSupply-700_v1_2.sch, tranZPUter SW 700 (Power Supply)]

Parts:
C6, C8, C9, C15: 10uF; C_0603_1608Metric_Pad1.05x0.95mm_HandSolder
C7, C10, C11, C12, C13, C14, C16, C19, C20, C21, C22, C23, C27: 100nF; C_0603_1608Metric_Pad1.05x0.95mm_HandSolder
C24, C25, C26, C28, C29, C30, C31: 100nF; C_0805_2012Metric
C32, C33, C34, C35, C36, C37, C38, C39, C40, C41, C42: 100nF; C_0603_1608Metric
U4: EPM7512AEQFP144; TQFP-144_20x20mm_P0.5mm
U5: EP3C25E144C8N; EQFP-144-1EP_20x20mm_P0.5mm_EP6.61x5.615mm
U10: AMS1117-2.5; SOT-223-3_TabPin2
U11: AMS1117-3.3; SOT-223-3_TabPin2
U12: AMS1117-1.2; SOT-223-3_TabPin2

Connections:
+1V2: C14.1, C15.1, C16.1, C19.1, C20.1, C21.1, C22.1, C23.1, U5.1 (VCCD_PLL3), U5.5 (VCCINT1), U5.29 (VCCINT2), U5.34 (VCCINT3), U5.37 (VCCD_PLL1), U5.38 (VCCINT4), U5.45 (VCCINT5), U5.61 (VCCINT6), U5.70 (VCCINT7), U5.73 (VCCD_PLL4), U5.78 (VCCINT8), U5.84 (VCCINT9), U5.102 (VCCINT10), U5.109 (VCCD_PLL2), U5.116 (VCCINT11), U5.124 (VCCINT12), U5.134 (VCCINT13), U5.138 (VCCINT14), U12.2 (VO)
+2V5: C8.1, C10.1, C11.1, C12.1, C13.1, U5.3 (VCCA3), U5.35 (VCCA1), U5.75 (VCCA4), U5.107 (VCCA2), U10.2 (VO); also elsewhere on the board
+5V: C6.1, C7.1, U10.3 (VI), U11.3 (VI); also elsewhere on the board
GNDPWR: C6.2, C7.2, C8.2, C9.2, C10.2, C11.2, C12.2, C13.2, C14.2, C15.2, C16.2, C19.2, C20.2, C21.2, C22.2, C23.2, C24.2, C25.2, C26.2, C27.2, C28.2, C29.2, C30.2, C31.2, C32.2, C33.2, C34.2, C35.2, C36.2, C37.2, C38.2, C39.2, C40.2, C41.2, C42.2, U4.3 (GNDIO1), U4.13 (GNDIO2), U4.17 (GNDIO3), U4.33 (GNDIO4), U4.52 (GNDINT1), U4.57 (GNDINT2), U4.59 (GNDIO5), U4.64 (GNDIO6), U4.85 (GNDIO7), U4.105 (GNDIO8), U4.124 (GNDINT3), U4.129 (GNDINT4), U4.135 (GNDIO9), U5.2 (GNDA3), U5.19 (GND1), U5.27 (GND2), U5.36 (GNDA1), U5.41 (GND3), U5.48 (GND4), U5.57 (GND5), U5.63 (GND6), U5.74 (GNDA4), U5.82 (GND7), U5.95 (GND8), U5.108 (GNDA2), U5.118 (GND9), U5.123 (GND10), U5.131 (GND11), U5.140 (GND12), U5.145 (GNDCTR), U10.1 (GND), U11.1 (GND), U12.1 (ADJ); also elsewhere on the board

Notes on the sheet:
100nF x 11
100nF x 8
Seperate 3.3V for the CPLF/FPGA , the K64F has it’s own regulator. This is intentional for board routing and power demands of the 3.3V rail.

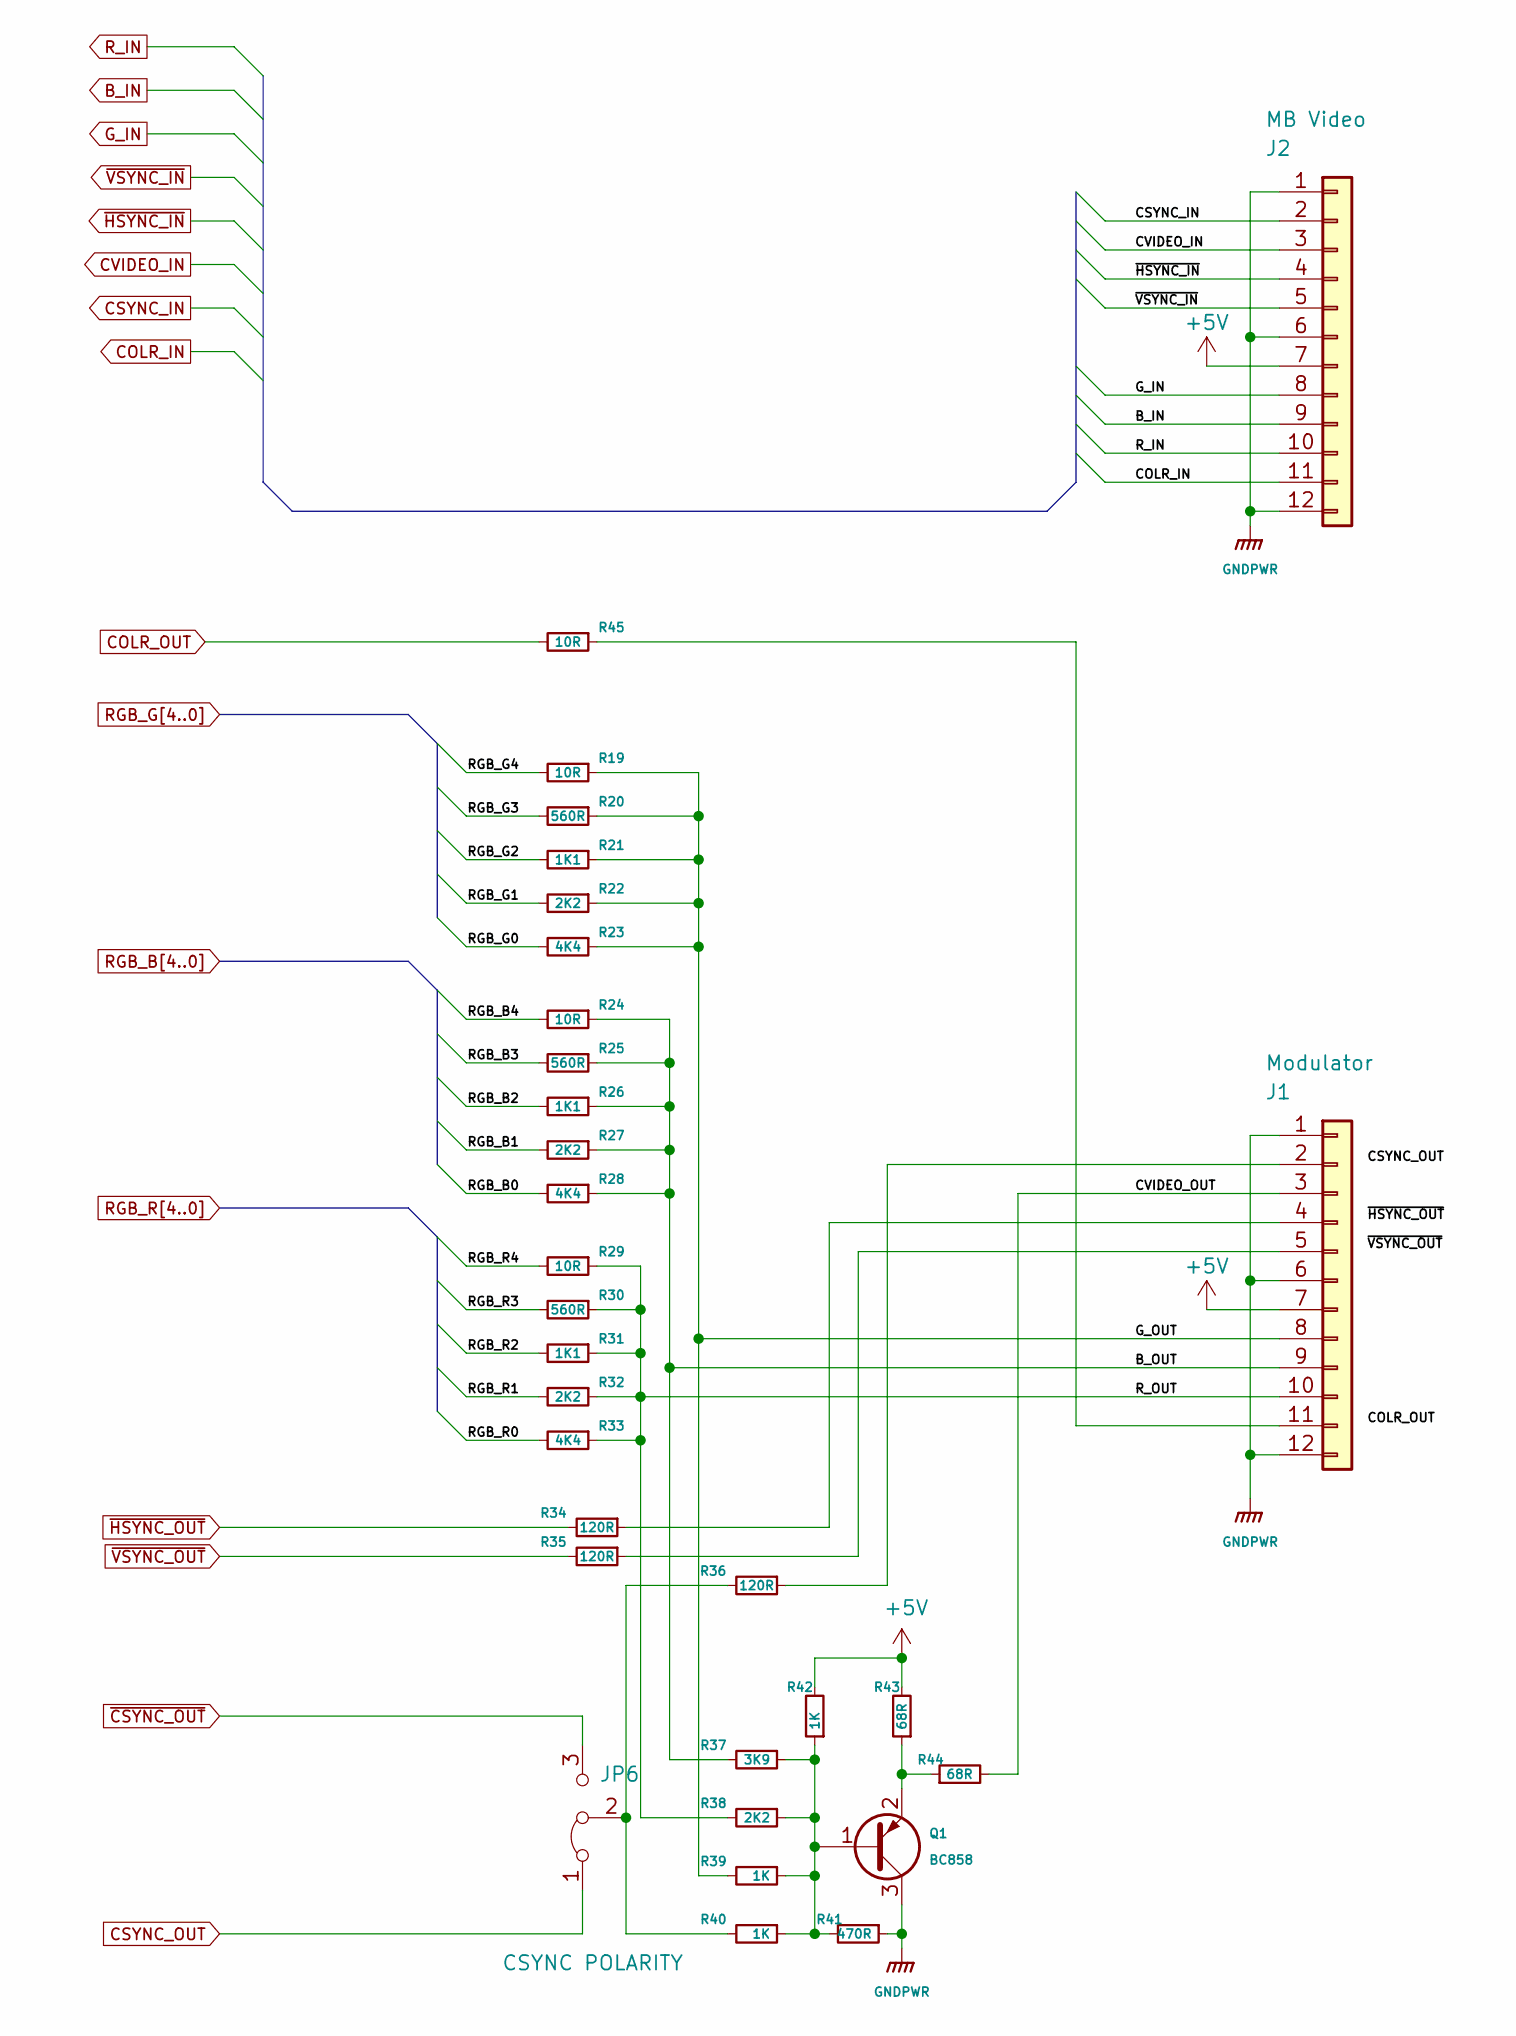
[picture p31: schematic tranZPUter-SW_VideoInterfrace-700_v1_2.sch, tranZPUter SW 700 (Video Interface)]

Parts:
J1: Modulator; PinHeader_1x12_P2.54mm_Vertical
J2: MB Video; PinHeader_1x12_P2.54mm_Vertical
JP6: CSYNC POLARITY; PinHeader_1x03_P2.00mm_Vertical
Q1: BC858; SOT-23
R19, R24, R29, R45: 10R; R_0805_2012Metric_Pad1.15x1.40mm_HandSolder
R20, R25, R30: 560R; R_0805_2012Metric_Pad1.15x1.40mm_HandSolder
R21, R26, R31: 1K1; R_0805_2012Metric_Pad1.15x1.40mm_HandSolder
R22, R27, R32, R38: 2K2; R_0805_2012Metric_Pad1.15x1.40mm_HandSolder
R23, R28, R33: 4K4; R_0805_2012Metric_Pad1.15x1.40mm_HandSolder
R34, R35, R36: 120R; R_0805_2012Metric_Pad1.15x1.40mm_HandSolder
R37: 3K9; R_0805_2012Metric_Pad1.15x1.40mm_HandSolder
R39, R40, R42: 1K; R_0805_2012Metric_Pad1.15x1.40mm_HandSolder
R41: 470R; R_0805_2012Metric_Pad1.15x1.40mm_HandSolder
R43, R44: 68R; R_0805_2012Metric_Pad1.15x1.40mm_HandSolder

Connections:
+5V: J1.7, J2.7, R42.2, R43.2; also elsewhere on the board
/Video Interface/B_OUT: J1.9, R24.1, R25.1, R26.1, R27.1, R28.1, R37.2
/Video Interface/CVIDEO_OUT: J1.3, R44.2
/Video Interface/G_OUT: J1.8, R19.1, R20.1, R21.1, R22.1, R23.1, R39.2
/Video Interface/R_OUT: J1.10, R29.1, R30.1, R31.1, R32.1, R33.1, R38.2
B_IN: J2.9; also elsewhere on the board
COLR_IN: J2.11; also elsewhere on the board
COLR_OUT: R45.2; also elsewhere on the board
CSYNC_IN: J2.2; also elsewhere on the board
CSYNC_OUT: JP6.1 (A); also elsewhere on the board
CVIDEO_IN: J2.3; also elsewhere on the board
GNDPWR: J1.1, J1.6, J1.12, J2.1, J2.6, J2.12, Q1.3 (C), R41.1; also elsewhere on the board
G_IN: J2.8; also elsewhere on the board
unnamed: J1.2, R36.1
unnamed: J1.4, R34.1
unnamed: J1.5, R35.1
unnamed: J1.11, R45.1
unnamed: JP6.2 (C), R36.2, R40.2
unnamed: Q1.1 (B), R37.1, R38.1, R39.1, R40.1, R41.2, R42.1
unnamed: Q1.2 (E), R43.1, R44.1
RGB_B0: R28.2; also elsewhere on the board
RGB_B1: R27.2; also elsewhere on the board
RGB_B2: R26.2; also elsewhere on the board
RGB_B3: R25.2; also elsewhere on the board
RGB_B4: R24.2; also elsewhere on the board
RGB_G0: R23.2; also elsewhere on the board
RGB_G1: R22.2; also elsewhere on the board
RGB_G2: R21.2; also elsewhere on the board
RGB_G3: R20.2; also elsewhere on the board
RGB_G4: R19.2; also elsewhere on the board
RGB_R0: R33.2; also elsewhere on the board
RGB_R1: R32.2; also elsewhere on the board
RGB_R2: R31.2; also elsewhere on the board
RGB_R3: R30.2; also elsewhere on the board
RGB_R4: R29.2; also elsewhere on the board
R_IN: J2.10; also elsewhere on the board
~CSYNC_OUT~: JP6.3 (B); also elsewhere on the board
~HSYNC_IN~: J2.4; also elsewhere on the board
~HSYNC_OUT~: R34.2; also elsewhere on the board
~VSYNC_IN~: J2.5; also elsewhere on the board
~VSYNC_OUT~: R35.2; also elsewhere on the board

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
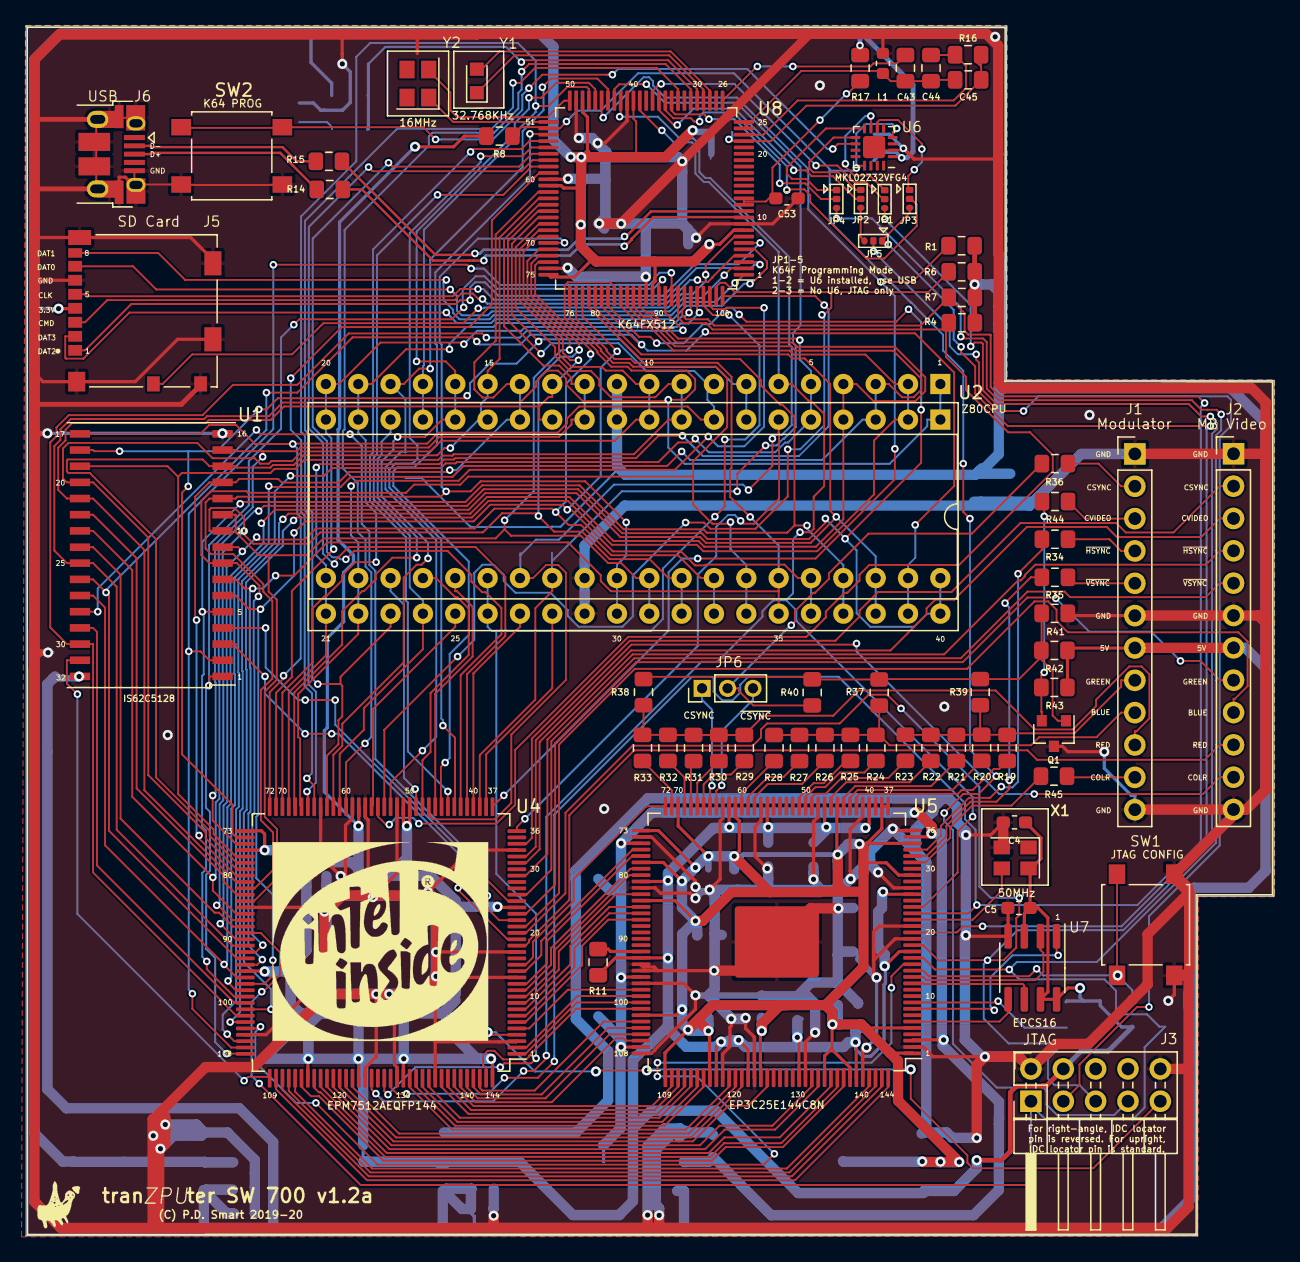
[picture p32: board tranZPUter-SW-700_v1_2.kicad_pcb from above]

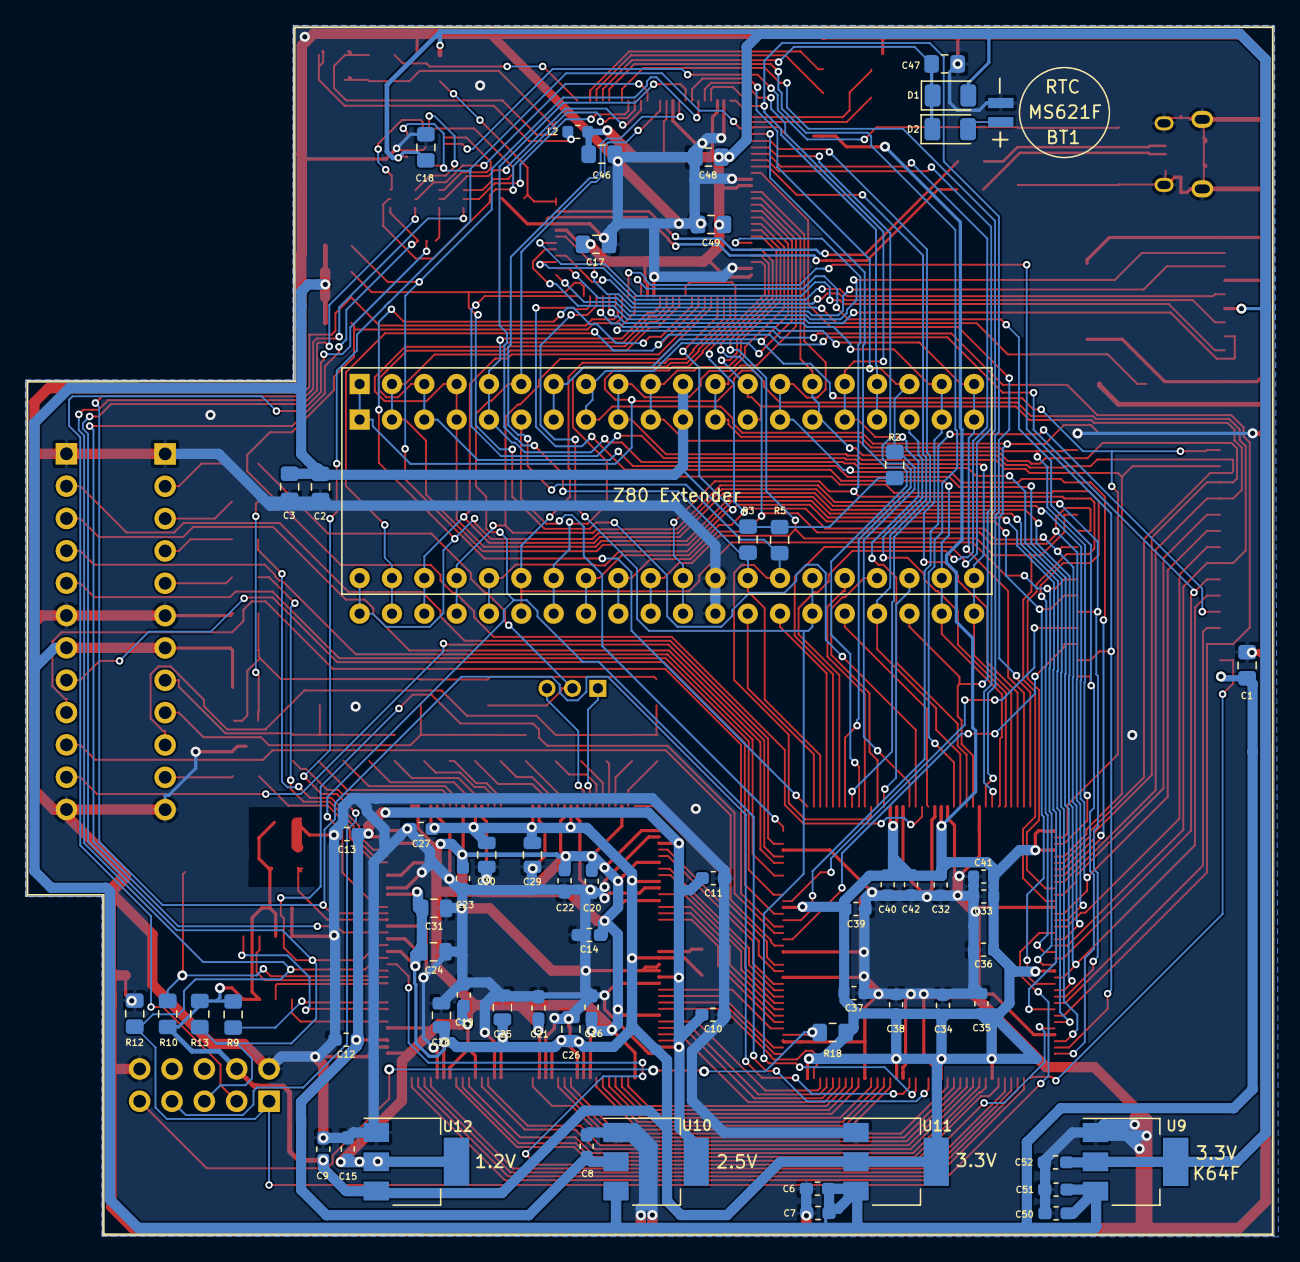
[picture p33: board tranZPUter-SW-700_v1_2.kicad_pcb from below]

Board: 2 copper layers, 98.0 x 95.0 mm, 132 parts (63 on the bottom side), 194 nets.

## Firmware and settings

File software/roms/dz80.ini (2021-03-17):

----------------------------------------
-- dZ80 configuration file
----------------------------------------

----------------------------------------
-- Disassembly control
----------------------------------------

cpu="z80"
inputfile="MZ800_IOCS.ORI"
outputfile="MZ800_IOCS.asm"
--fileheadersize=27
filebaseaddr=0
disstart=0
disend=3072
--disstart=0
--disend=3584
--quiet=0
labelledoutput=1

----------------------------------------
-- Layout
----------------------------------------

labelreference=1
addresscolumn=1
opcodecolumn=1
relativejumpcomment=1
uppercase=1
autoblanklines=1
db="db"
comment="; "
radix=16
numprefix="0"
numsuffix="H"

----------------------------------------
-- Scripts
----------------------------------------

--script="scripts\\spectrum.lua"

----------------------------------------
-- References
----------------------------------------

referencefile="MZ800_IOCS.ref"
inportreference=1
outportreference=1
addressreference=1
indirectaddressreference=1
limitreferences=1

----------------------------------------
-- Opcode mapfile and code/data areas
----------------------------------------

--opmapfile="mayhem.map"
d_SetCodeRegion(0, 2464)

--
--d_SetDataRegion(45568 + 51,     1)     -- flag
--d_SetDataRegion(45568 + 70,     79)    -- dpbase
--d_SetDataRegion(45568 + 268,    15 )   -- dpb0
--d_SetDataRegion(45568 + 283,    15 )   -- dpb

--d_SetDataRegion(45568 + 2152,  1047)   -- Unused
--d_SetDataRegion(45568 + 3200,   117)   -- Copyright
--d_SetDataRegion(45568 + 3317,   266)   -- Unused


--d_SetDataRegion(3488,  608 )   -- Loading P-CP/M80
--d_SetDataRegion(200,  15 )   -- No system file
--d_SetDataRegion(215,  11 )   -- Boot error
--d_SetDataRegion(1167, 255)   -- Data
--d_SetDataRegion(1477, 58)    -- Data



--d_SetDataRegion(161, 13)    -- BOOT DRIVE ?<cr>
--d_SetDataRegion(174, 14)    -- LOADING ERROR<cr>
--d_SetDataRegion(188, 16)    -- IPL IS LOADING <cr>
--d_SetDataRegion(204, 7)     -- <02>IPLPRO
--d_SetDataRegion(211, 10)    -- DATA
--d_SetDataRegion(221, 11)    -- DATA
--d_SetDataRegion(232, 28)    -- THIS DISKETTE IS NOT MASTER<cr>

--d_SetDataRegion(733 + 1024, 291)   -- Unused
--d_SetDataRegion(161 + 1024, 13)    -- BOOT DRIVE ?<cr>
--d_SetDataRegion(174 + 1024, 14)    -- LOADING ERROR<cr>
--d_SetDataRegion(188 + 1024, 16)    -- IPL IS LOADING <cr>
--d_SetDataRegion(204 + 1024, 7)     -- <02>IPLPRO
--d_SetDataRegion(211 + 1024, 10)    -- DATA
--d_SetDataRegion(221 + 1024, 11)    -- DATA
--d_SetDataRegion(232 + 1024, 28)    -- THIS DISKETTE IS NOT MASTER<cr>



----------------------------------------
-- End of configuration file
----------------------------------------

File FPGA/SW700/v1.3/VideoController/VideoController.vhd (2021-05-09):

---------------------------------------------------------------------------------------------------------
--
-- Name:            VideoController.vhd
-- Created:         June 2020
-- Author(s):       Philip Smart
-- Description:     Sharp MZ Series Video Module FPGA logic definition file.
--                  This module contains the definition of the video controller used in tranZPUter FPGA
--                  core whicch appears on the tranZPUter and tranZPUter SW 700 boards. The controller
--                  emulates the video logic of the Sharp MZ80A, MZ-700 and MZ80B including pixel graphics.
--                  The design needs 64KB of memory, so using a smaller FPGA would require the addition
--                  of an external SRAM and like most developments, more is better until the design is
--                  finalised as it gives you more options. This is especially true as the core FPGA will
--                  also instantiate Soft-CPU's for the Sharp MZ series, either the T80 clocking at 50-100MHz
--                  or other processors as time deems feasible to incorporate.
--
--                  One aim of this module is to maintain a degree of compatibility with the Sharp MZ
--                  emulator hardware I wrote, backporting enhancements made here and potentially making a
--                  single design shared by both.
--
-- Credits:         
-- Copyright:       (c) 2018-21 Philip Smart <philip.smart@net2net.org>
--
-- History:         June 2020 - Initial creation.
--                  Sep 2020  - Working first version. Slight sync issues on the VGA modes 1 & 2 as
--                              they use a seperate PLL so sometimes switching to these modes causes
--                              flicker which can be resolved by just reswitching to the same mode.
--                              All the MZ80B logic etc has been ported from my Emulator but not yet
--                              tested as I need to finish implementing the MZ80B mode on the MZ80A
--                              via the tranZPUter. Will feed back the video output generation into the
--                              Emulator as the original emulator design has bugs!
--                              A nice to have would be a seperate video output stream to the internal
--                              monitor when using VGA modes on the external display but this requires
--                              another framebuffer and the FPGA hasnt got the resources. Maybe v2.1
--                              will contain a bigger FPGA (or external RAM)!!!!
--                  Oct 2020  - Split off from the Sharp MZ80A Video Module, the Video Module for the 
--                              Sharp MZ700 has the same roots but different control functionality. The
--                              MZ700 version resides within the tranZPUter memory and not the mainboard
--                              allowing for generally easier control. The MZ80A and MZ700 graphics logic
--                              should be pretty much identical.
--                  Nov 2020 -  A further split from the SW700 board v1.2 logic, this time as part of 
--                              a reorganisation where the larger v1.3 FPGA will not only incorporate
--                              video logic but also soft-cpu's.
--                  Dec 2020 -  Added logic to accommodate direct addressing of the various internal
--                              memory devices to allow soft CPU's to avoid using the Sharp MZ register
--                              selection and 8K address space window.
--
---------------------------------------------------------------------------------------------------------
-- This source file is free software: you can redistribute it and-or modify
-- it under the terms of the GNU General Public License as published
-- by the Free Software Foundation, either version 3 of the License, or
-- (at your option) any later version.
--
-- This source file is distributed in the hope that it will be useful,
-- but WITHOUT ANY WARRANTY; without even the implied warranty of
-- MERCHANTABILITY or FITNESS FOR A PARTICULAR PURPOSE.  See the
-- GNU General Public License for more details.
--
-- You should have received a copy of the GNU General Public License
-- along with this program.  If not, see <http:--www.gnu.org-licenses->.
---------------------------------------------------------------------------------------------------------
library ieee;
library altera;
library altera_mf;
library pkgs;
use     ieee.std_logic_1164.all;
use     ieee.std_logic_unsigned.all;
use     ieee.numeric_std.all;
use     work.VideoController_pkg.all;
use     altera.altera_syn_attributes.all;
use     altera_mf.all;
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

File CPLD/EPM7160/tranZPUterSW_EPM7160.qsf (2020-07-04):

# -------------------------------------------------------------------------- #
#
# Copyright (C) 1991-2013 Altera Corporation
# Your use of Altera Corporation's design tools, logic functions 
# and other software and tools, and its AMPP partner logic 
# functions, and any output files from any of the foregoing 
# (including device programming or simulation files), and any 
# associated documentation or information are expressly subject 
# to the terms and conditions of the Altera Program License 
# Subscription Agreement, Altera MegaCore Function License 
# Agreement, or other applicable license agreement, including, 
# without limitation, that your use is for the sole purpose of 
# programming logic devices manufactured by Altera and sold by 
# Altera or its authorized distributors.  Please refer to the 
# applicable agreement for further details.
#
# -------------------------------------------------------------------------- #
#
# Quartus II 64-Bit
# Version 13.0.1 Build 232 06/12/2013 Service Pack 1 SJ Web Edition
# Date created = 16:29:32  June 24, 2020
#
# -------------------------------------------------------------------------- #
#
# Notes:
#
# 1) The default values for assignments are stored in the file:
#		tranZPUterSW_assignment_defaults.qdf
#    If this file doesn't exist, see file:
#		assignment_defaults.qdf
#
# 2) Altera recommends that you do not modify this file. This
#    file is updated automatically by the Quartus II software
#    and any changes you make may be lost or overwritten.
#
# -------------------------------------------------------------------------- #


set_global_assignment -name FAMILY MAX7000S
set_global_assignment -name DEVICE "EPM7160STC100-10"
set_global_assignment -name TOP_LEVEL_ENTITY tranZPUterSW
set_global_assignment -name ORIGINAL_QUARTUS_VERSION "13.0 SP1"
set_global_assignment -name PROJECT_CREATION_TIME_DATE "16:29:32  JUNE 24, 2020"
set_global_assignment -name LAST_QUARTUS_VERSION "13.0 SP1"
set_global_assignment -name PROJECT_OUTPUT_DIRECTORY output_files
set_global_assignment -name ERROR_CHECK_FREQUENCY_DIVISOR "-1"
set_global_assignment -name EDA_DESIGN_ENTRY_SYNTHESIS_TOOL "<None>"
set_global_assignment -name EDA_INPUT_VCC_NAME VDD -section_id eda_design_synthesis
set_global_assignment -name EDA_INPUT_DATA_FORMAT EDIF -section_id eda_design_synthesis
set_global_assignment -name EDA_SIMULATION_TOOL "ModelSim-Altera (VHDL)"
set_global_assignment -name EDA_OUTPUT_DATA_FORMAT VHDL -section_id eda_simulation
set_global_assignment -name OPTIMIZE_HOLD_TIMING OFF
set_global_assignment -name OPTIMIZE_MULTI_CORNER_TIMING OFF
set_global_assignment -name FITTER_EFFORT "STANDARD FIT"
set_global_assignment -name MAX7000_DEVICE_IO_STANDARD TTL

# Z80 Address Bus
# ===============
set_location_assignment PIN_79 -to Z80_HI_ADDR[18]
set_location_assignment PIN_78 -to Z80_HI_ADDR[17]
set_location_assignment PIN_77 -to Z80_HI_ADDR[16]
set_location_assignment PIN_76 -to Z80_ADDR[15]
set_location_assignment PIN_75 -to Z80_ADDR[14]
set_location_assignment PIN_72 -to Z80_ADDR[13]
set_location_assignment PIN_71 -to Z80_ADDR[12]
set_location_assignment PIN_70 -to Z80_ADDR[11]
set_location_assignment PIN_69 -to Z80_ADDR[10]
set_location_assignment PIN_68 -to Z80_ADDR[9]
set_location_assignment PIN_67 -to Z80_ADDR[8]
set_location_assignment PIN_65 -to Z80_ADDR[7]
set_location_assignment PIN_64 -to Z80_ADDR[6]
set_location_assignment PIN_63 -to Z80_ADDR[5]
set_location_assignment PIN_61 -to Z80_ADDR[4]
set_location_assignment PIN_60 -to Z80_ADDR[3]
set_location_assignment PIN_58 -to Z80_ADDR[2]
set_location_assignment PIN_57 -to Z80_ADDR[1]
set_location_assignment PIN_56 -to Z80_ADDR[0]

# Z80 Data Bus
# ============
set_location_assignment PIN_55 -to Z80_DATA[0]
set_location_assignment PIN_54 -to Z80_DATA[1]
set_location_assignment PIN_53 -to Z80_DATA[2]
set_location_assignment PIN_52 -to Z80_DATA[3]
set_location_assignment PIN_50 -to Z80_DATA[4]
set_location_assignment PIN_49 -to Z80_DATA[5]
set_location_assignment PIN_48 -to Z80_DATA[6]
set_location_assignment PIN_47 -to Z80_DATA[7]

# Graphics extension address and control.
# =======================================
set_location_assignment PIN_5 -to VADDR[13]
set_location_assignment PIN_6 -to VADDR[12]
set_location_assignment PIN_7 -to VADDR[11]
set_location_assignment PIN_1 -to VMEM_CSn

# RAM control
# ===========
set_location_assignment PIN_81 -to RAM_CSn
set_location_assignment PIN_16 -to RAM_OEn
set_location_assignment PIN_17 -to RAM_WEn

# K64F Interrupt requests
# =======================
set_location_assignment PIN_8 -to SYSREQn
set_location_assignment PIN_9 -to SVCREQn

# K64F control
# ============
set_location_assignment PIN_20 -to CTL_WAITn
set_location_assignment PIN_21 -to CTL_RFSHn
set_location_assignment PIN_19 -to CTL_CLKSLCT
set_location_assignment PIN_25 -to CTL_HALTn
set_location_assignment PIN_90 -to CTLCLK
set_location_assignment PIN_23 -to CTL_M1n
set_location_assignment PIN_24 -to CTL_BUSACKn
set_location_assignment PIN_22 -to CTL_BUSRQn
set_location_assignment PIN_42 -to TZ_BUSACKn
set_location_assignment PIN_94 -to ENIOWAIT
set_location_assignment PIN_96 -to Z80_MEM[4]
set_location_assignment PIN_97 -to Z80_MEM[3]
set_location_assignment PIN_98 -to Z80_MEM[2]
set_location_assignment PIN_99 -to Z80_MEM[1]
set_location_assignment PIN_100 -to Z80_MEM[0]
set_location_assignment PIN_84 -to TBA[0]
set_location_assignment PIN_85 -to TBA[1]
set_location_assignment PIN_92 -to TBA[2]
set_location_assignment PIN_93 -to TBA[3]

# Z80 Control signals.
# ====================
set_location_assignment PIN_36 -to Z80_MREQn
set_location_assignment PIN_35 -to Z80_IORQn
set_location_assignment PIN_33 -to Z80_RDn
set_location_assignment PIN_32 -to Z80_WRn
set_location_assignment PIN_31 -to Z80_RFSHn
set_location_assignment PIN_30 -to Z80_M1n
set_location_assignment PIN_29 -to Z80_WAITn
set_location_assignment PIN_44 -to Z80_HALTn
set_location_assignment PIN_28 -to Z80_BUSACKn
set_location_assignment PIN_27 -to Z80_BUSRQn
set_location_assignment PIN_40 -to Z80_INTn
set_location_assignment PIN_37 -to Z80_NMIn
set_location_assignment PIN_80 -to Z80_CLK
set_location_assignment PIN_89 -to Z80_RESETn

# Mainboard control signals.
# ==========================
set_location_assignment PIN_87 -to SYSCLK
set_location_assignment PIN_12 -to SYS_WAITn
set_location_assignment PIN_10 -to SYS_BUSRQn
set_location_assignment PIN_13 -to SYS_BUSACKn

set_global_assignment -name VHDL_FILE ../tranZPUterSW_Toplevel_EPM7160.vhd
set_global_assignment -name VHDL_FILE ../tranZPUterSW_pkg_EPM7160.vhd
set_global_assignment -name VHDL_FILE ../tranZPUterSW_EPM7160.vhd
set_global_assignment -name SDC_FILE tranZPUterSW_constraints_EPM7160.sdc

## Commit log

2019-10-25 Additional files
    [tranZPUter-B_Cu.gbl, tranZPUter-B_Mask.gbs, tranZPUter-B_SilkS.gbo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]
2020-01-14 Updates to SDRAM and SoC
    [tranZPUter.stp]
2020-04-28 Added READNE, schematic and Gerber files for tranZPUterSW
    [tranZPUter-SW-B_Adhes.gbr, tranZPUter-SW-B_CrtYd.gbr, tranZPUter-SW-B_Cu.gbr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]
2020-05-29 Initial developments of TZFS and preparation of CPM
    [COPY.CFG, FILEATTR.CFG, FILEDATE.CFG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]
2020-06-03 Updated changed schematic
2020-06-10 Updates to test the MZ700 memory mode switching
2020-06-10 Updated schematic
2020-07-04 Updated schematics
2020-07-16 Updates for v1.1 board
2020-07-24 v2.1 first cut
2020-07-29 Updates for v2.1 board
2020-07-29 Updates for v2.1 of the tranZPUter board
2020-09-02 New schematic for v2.2
2020-09-06 Updates to CPM and Microsoft BASIC to configure the new Video Module and system board speed
2020-11-02 Video and tranZPUter developments for the SW700 board
2020-11-08 Updates for SW-700 board
2021-02-06 Added schematics, kicad and pcb gerber files
    [tranZPUter-SW-700_v1_2-B_Adhes.gbr, tranZPUter-SW-700_v1_2-B_CrtYd.gbr, tranZPUter-SW-700_v1_2-B_Cu.gbr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]
2021-03-03 Removed files which shouldnt be on github
    [MUSIMP.OBJ, NZBLTZ14.CFG, RELOCCPM.OBJ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]
2021-03-03 Removed files which shouldnt be on git
    [COPY.CFG, FILEATTR.CFG, FILEDATE.CFG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]
2021-04-18 sync with rfs, 40/80 versions, bug fixes
    [cbios.asm, cbiosII.asm]
